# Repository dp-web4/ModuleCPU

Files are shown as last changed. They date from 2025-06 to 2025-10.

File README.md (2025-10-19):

# ModuleCPU

**ModBatt Battery Management System - Module Controller**

## Overview

ModuleCPU is the middle-tier controller in ModBatt's hierarchical battery management system, coordinating up to 128 individual CellCPUs while reporting aggregated data to the Pack Controller. It demonstrates how distributed intelligence principles can be applied to embedded battery management at the module scale.

**Implementation Status**: ✅ **Production-ready** - Complete firmware with CAN bus communication, VUART cell management, and hierarchical coordination

### Quick Facts

- **Target Platform**: ATmega64M1 microcontroller (8-bit AVR with CAN)
- **Manages**: Up to 128 CellCPUs via Virtual UART daisy-chain
- **Uplink**: CAN 2.0B bus to Pack Controller (250kbps)
- **Features**: Dual-phase operation, RTC timestamping, robust error handling
- **Role**: Middle management - aggregates cell data, coordinates without micromanaging

## Web4 Ecosystem Context

ModuleCPU can be viewed as a practical demonstration of trust-native architecture patterns applied to embedded battery management:

**Philosophical Framework**: [Synchronism](https://github.com/dp-web4/Synchronism) - Patterns of scale-based coordination and distributed intelligence
**Technical Standard**: [Web4](https://github.com/dp-web4/web4) - Concepts like unforgeable identity and witnessed relationships
**Implementation**: [CellCPU](https://github.com/dp-web4/CellCPU) → **ModuleCPU** (this) → [Pack-Controller](https://github.com/dp-web4/Pack-Controller-EEPROM)

### Design Patterns

ModuleCPU's architecture reflects several patterns that align with Web4 and Synchronism concepts:

- **Identity**: Module serial number framework ready for LCT binding
- **Interface Boundaries**: Well-defined information hiding between layers (CAN upward, VUART downward)
- **Relationship Tracking**: Module maintains awareness of Pack Controller and 94 cells
- **Hierarchical Coordination**: Operates autonomously within constraints from Pack
- **Information Aggregation**: Compresses 188 cell data points into module-level summaries
- **Emergent Intelligence**: System-level balancing from distributed local decisions

See [WEB4_INTEGRATION.md](WEB4_INTEGRATION.md) for how Web4 concepts map to embedded design.
See [SYNCHRONISM_PRINCIPLES.md](SYNCHRONISM_PRINCIPLES.md) for architectural patterns and philosophy.

### Ecosystem Links

- [Synchronism Whitepaper](https://github.com/dp-web4/Synchronism) - Theoretical framework
- [Web4 Standard](https://github.com/dp-web4/web4) - Trust-native architecture concepts
- [ModBatt Web4 Examples](https://github.com/dp-web4/web4/blob/main/docs/modbatt_implementation_examples.md) - Implementation walkthroughs

**This demonstrates how concepts from distributed intelligence theory can inform practical embedded system design.**

---

## Key Features

### 🔋 Cell Management
- **Capacity**: Manages up to 128 CellCPUs in daisy-chain topology
- **Communication**: Virtual UART at 20kbps for cell polling
- **Monitoring**: Aggregates temperature, voltage, and status from all cells
- **Coordination**: Enables balancing, tracks cell health, detects faults

### 📡 Pack Communication
- **Protocol**: CAN 2.0B extended frames with module ID addressing
- **Registration**: Dynamic ID assignment (1-31) from Pack Controller
- **Reporting**: Module-level status, aggregated cell data, error conditions
- **Commands**: State changes, balancing control, time synchronization

### ⚙️ Core Capabilities
- **Dual-Phase Operation**: Separate read/write phases for data integrity
- **RTC Support**: Real-time clock for timestamping
- **Error Handling**: Robust timeout and recovery mechanisms
- **State Management**: OFF/STANDBY/ACTIVE/BALANCE states with safety checks

### 🎯 Performance
- **Memory**: 64KB Flash, 4KB SRAM
- **Response Time**: <50ms for full cell poll cycle (94 cells)
- **CAN Reliability**: Timeout recovery, bus-off handling, error counting
- **Cell Tracking**: Bitmap and statistics for each cell position

## Protocol Synchronization

**Important**: ModuleCPU uses shared CAN protocol definitions maintained in the Pack-Controller-EEPROM repository.

**Authoritative Source**: [Pack-Controller-EEPROM/protocols/](https://github.com/dp-web4/Pack-Controller-EEPROM/tree/main/protocols)
**Local Copy**: `protocols/` (synchronized via `scripts/sync_protocols.sh`)

To update protocols after changes in Pack-Controller:
```bash
./scripts/sync_protocols.sh
# Review changes, test build, commit
```

See `protocols/SYNC_NOTICE.md` for synchronization procedure and versioning.

## System Integration

### ModBatt Architecture

```
Vehicle Control Unit (VCU)
    ↓ CAN Bus
Pack Controller (STM32WB55)
    ↓ CAN Bus (250kbps, extended frames)
ModuleCPU (ATmega64M1) ←─→ 128 × CellCPU (ATtiny45)
    ↓ Virtual UART (20kbps)     ↓
Battery Module             Li-ion Cells
```

### Information Flow

**Upward (Aggregation)**:
```
94 cells × (temp + voltage) = 188 data points
    ↓ (Module aggregates)
Module summary: avg/min/max temps, voltage spread, status bitmap
    ↓ (via CAN)
Pack Controller receives compressed module-level view
```

**Downward (Commands)**:
```
Pack: "Modules enter BALANCE state" (broadcast or targeted)
    ↓ (Module interprets)
Module: Polls cells, coordinates balancing based on voltages
    ↓ (Cells execute)
Cells: Activate balancing FETs based on local decisions
```

## Build Environment

**Important**: This project runs in WSL but uses Windows-based build tools.

- **IDE**: Atmel Studio 7.0+ (Windows)
- **Build**: Must compile in Windows environment
- **WSL**: Used for version control and documentation only
- **Focus**: Code correctness and architecture

See [CLAUDE.md](CLAUDE.md) for development context and recent improvements.

## Recent Enhancements

### Protocol Dependency Resolution (October 2025)
- ✅ Added local `protocols/` directory with sync script
- ✅ Resolved Pack-Controller build dependency
- ✅ ModuleCPU now builds standalone

### CAN Reliability Improvements (September 2025)
- ✅ TX timeout mechanism with backup polling
- ✅ Bus-off recovery with health monitoring
- ✅ Adaptive backoff for persistent errors
- ✅ Diagnostic counters for error tracking

### VUART Edge Detection Fix (September 2025)
- ✅ Rising edge detection for level-shifted signals
- ✅ Improved temperature data reliability
- ✅ Better daisy-chain communication

See [CLAUDE.md](CLAUDE.md) for complete development history and technical details.

## Contributing

See [CONTRIBUTING.md](CONTRIBUTING.md) for development workflow, coding standards, and pull request guidelines.

## License and Patents

### Software License

This software is licensed under the **GNU Affero General Public License v3.0 or later** (AGPL-3.0-or-later).

See [LICENSE](LICENSE) for full license text.
See [LICENSE_SUMMARY.md](LICENSE_SUMMARY.md) for software vs. hardware licensing details.

### Patents

Protected by US Patents:
- **11,469,470**: Hierarchical battery management architecture
- **11,380,942**: Distributed cell controller system
- **11,575,270**: Related pack control systems

**Patent Grant**: Limited patent grant for software use under AGPL-3.0. See [PATENTS.md](PATENTS.md).

**Hardware Licensing**: Separate from software. See `docs/legal/ModBatt_Product_License.pdf`.

### Copyright

© 2023-2025 Modular Battery Technologies, Inc.

**Open Source Release**: October 2025 - Part of the Web4 trust-native ecosystem demonstration.

---

## Related Projects

This repository can be viewed as demonstrating patterns of distributed trust and verifiable provenance in embedded systems.

**Related**: [Web4](https://github.com/dp-web4/web4) (trust architecture) • [Synchronism](https://github.com/dp-web4/Synchronism) (conceptual framing)

---

**Note**: This firmware demonstrates hierarchical coordination patterns in embedded systems. Whether viewed through the lens of Web4/Synchronism concepts or simply as sound battery management architecture, the design patterns are production-tested and functional.

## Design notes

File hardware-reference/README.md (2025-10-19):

# ModuleCPU Hardware Reference Designs

**Status**: Reference designs for educational and non-commercial use
**Patent Coverage**: Protected by US Patent 11,469,470 (Hierarchical battery management architecture)
**Last Updated**: October 2025

---

## Overview

This directory contains reference hardware designs for implementing the ModuleCPU concept - a module-level coordinator managing up to 94 autonomous cell controllers. These designs demonstrate one possible hardware implementation of the patented hierarchical battery management architecture.

**Contents**:
- KiCad schematics and PCB layouts
- Bill of Materials (BOM)
- Manufacturing files

---

## Patent Coverage

These hardware designs implement concepts covered by multiple patents in the ModBatt patent portfolio:

### Complete Patent List

**Modular Battery Technologies, Inc. Patent Portfolio**:

1. **US 11,380,942** (PCT/US21/50518) - *High Voltage Battery Module with Series Connected Cells and Internal Relays*
   - Filed: November 2, 2020 | Issued: July 5, 2022
   - Module with series connected cells and relays

2. **US 11,469,470** (PCT/US21/53798) - *Battery Module with Series Connected Cells, Internal Relays and Internal Battery Management System*
   - Filed: January 4, 2021 | Issued: October 11, 2022
   - Cell monitoring/conditioning circuit, PCBAs, methods

3. **US 11,563,241** - *Apparatus and Methods for Removable Battery Module with Internal Relay and Internal Controller*
   - Filed: February 10, 2021 | Issued: December 14, 2022
   - Authentication methods and circuits

4. **US 11,575,270** (PCT/US21/55047) - *Battery Module with Series Connected Cells, Internal Relays and Internal Battery Management System*
   - Filed: February 22, 2021 (CIP) | Issued: February 7, 2023
   - AC coupled comms and methods

5. **US 11,699,817** (PCT/US21/54434) - *Apparatus and Methods for Removable Battery Module with Internal Relay and Internal Controller*
   - Filed: March 31, 2021 | Issued: July 11, 2023
   - System, pack and module controllers, blockchain

6. **US 11,477,027** (PCT/US21/55813) - *Apparatus and Methods for Management of Controlled Objects*
   - Filed: May 11, 2021 | Issued: October 18, 2022
   - Multi-domain management of controlled objects, LCT/blockchain

7. **US 11,936,008** (PCT/US21/60860) - *Electrical Power System with Removable Battery Modules*
   - Filed: November 17, 2021 | Issued: March 19, 2024
   - Dissimilar modules in parallel

8. **US 12,278,913** (PCT/US22/24797) - *Apparatus and Methods for Management of Controlled Objects*
   - Filed: March 31, 2022 | Issued: April 15, 2025
   - Linking of identifiable records

9. **US 11,876,250** (PCT/US22/xxx) - *High Voltage Battery Module with Series Connected Cells and Internal Relays*
   - Filed: May 31, 2022 | Issued: January 16, 2024
   - Dissimilar relays, PLC control bus, linear and PWM modes

10. **US 12,046,722** - *Electrical Power System with Removable Battery Modules*
    - Filed: December 12, 2022 | Issued: July 23, 2024
    - Vehicle and stationary installations having a power system, energizing a bus

11. **US 12,405,309** - *Low Cost Battery Cell Monitoring Circuit*
    - Filed: January 3, 2023 | Issued: September 2, 2025
    - Low cost ASIC

12. **US 12,136,739** - *Low Cost Battery Cell Monitoring Circuit*
    - Filed: December 14, 2023 | Issued: November 5, 2024
    - Low cost ASIC methods

13. **US 12,142,737** - *Electrical Power System with Removable Battery Modules*
    - Filed: December 14, 2023 | Issued: November 12, 2024

14. **US 18/935,265** - *High Voltage Battery Module with 1-Phase and 3-Phase AC Output*
    - Filed: November 1, 2024 | Status: Pending

**Assignee**: Modular Battery Technologies, Inc.
**Inventors**: Dennis Palatov, et al.

### Key Patented Concepts in ModuleCPU Hardware

- Module-level coordination of multiple autonomous cell controllers
- Virtual UART aggregation and CAN bus gateway
- Dual-phase operation for data integrity
- Scale-based hierarchical autonomy with information hiding
- RTC timestamping and coordinated data collection
- High voltage module architecture with internal relays
- Module authentication and blockchain integration
- Dissimilar module operation in parallel configurations
- AC-coupled communication methods

---

## License and Usage Terms

### Software License
The **ModuleCPU firmware** (parent directory) is licensed under **AGPL-3.0-or-later** with a patent grant for software use. See `../LICENSE` for details.

### Hardware Reference Designs
These hardware reference designs are provided under the following terms:

#### ✅ Permitted Uses (Non-Commercial Patent Grant)

You MAY use these designs **without a commercial hardware license** for:

1. **Educational Use**: Academic research, teaching, and learning
2. **Personal/Hobby Use**: Individual projects and experimentation
3. **Research & Development**: Prototyping and testing new concepts
4. **Open Source Development**: Contributing to AGPL-licensed software improvements

**Conditions**:
- No commercial sale or distribution of manufactured hardware
- Acknowledge patent and provide attribution
- Derivative works must include similar non-commercial use notice
- Software modifications must comply with AGPL-3.0-or-later

#### ❌ Restricted Uses (Requires Commercial License)

You MUST obtain a commercial hardware license from Modular Battery Technologies, Inc. for:

1. **Commercial Manufacturing**: Producing hardware for sale
2. **Commercial Products**: Incorporating designs into commercial battery products
3. **Revenue Generation**: Any use where hardware generates revenue directly or indirectly
4. **OEM Integration**: Selling products that include these designs

**Contact**: For commercial licensing inquiries, contact Modular Battery Technologies, Inc.

---

## Technical Scope

These reference designs demonstrate:

- **Module Controller**: ATmega64M1-based coordinator managing up to 128 cells
- **Virtual UART Interface**: Software serial communication to cell controllers (20kbps)
- **CAN Bus Gateway**: Extended CAN 2.0B interface to Pack Controller (500kbps)
- **Dual-Phase Operation**: Coordinated data collection and transmission
- **RTC Integration**: Real-time clock for timestamp synchronization
- **High Voltage Interface**: 300V+ pack voltage monitoring and isolation
- **Relay Control**: Module-level contactor control

**Module Capacity**: Up to 128 cells per module (4096 cells total in 32-module pack)

---

## AS-IS Disclaimer and Limitations

### ⚠️ NO WARRANTY

**THESE HARDWARE REFERENCE DESIGNS ARE PROVIDED "AS IS" WITHOUT WARRANTY OF ANY KIND, EXPRESS OR IMPLIED, INCLUDING BUT NOT LIMITED TO THE WARRANTIES OF MERCHANTABILITY, FITNESS FOR A PARTICULAR PURPOSE, TITLE, AND NON-INFRINGEMENT.**

### Specific Disclaimers

1. **No Guarantee of Functionality**: These designs may contain errors, omissions, or may not function as intended
2. **No Safety Certification**: Designs have NOT been certified for safety (UL, CE, etc.)
3. **Extreme Voltage Hazard**: Module designs operate at **300V+ DC** - **LETHAL VOLTAGE - RISK OF DEATH**
4. **High Power Hazard**: High current capability can cause arc flash, fires, and explosions
5. **Chemical Hazard**: Lithium battery failures can cause fire, toxic fumes, and explosions
6. **No Professional Engineering Review**: Use at your own risk - consult qualified professionals
7. **Rapidly Evolving**: These designs may be outdated or superseded

### 🚨 High Voltage Battery Safety Warning

**DANGER - LETHAL VOLTAGE**: Module-level battery systems operate at 300V+ DC.

- **DEATH or SERIOUS INJURY** can result from contact with high voltage
- **ARC FLASH** hazard - can cause severe burns, blindness, and ignition
- **Stored energy** remains dangerous even after power disconnection
- **Thermal runaway** can cause catastrophic fires and explosions
- **Improper isolation** can energize chassis and cause electrocution

**You are solely responsible for:**
- Proper high voltage safety engineering and interlocks
- Compliance with electrical codes (NEC Article 690, etc.)
- Qualified electrician installation and inspection
- Ground fault and arc fault protection systems
- Emergency disconnect and lockout/tagout procedures
- Fire suppression and containment systems
- Personal protective equipment (PPE) for high voltage work
- Warning labels and access restrictions
- Insurance and liability coverage

**⚠️ WARNING**: Working on high voltage battery systems requires specialized training. Improper work can result in death or serious injury.

---

## Limitation of Liability

**IN NO EVENT SHALL MODULAR BATTERY TECHNOLOGIES, INC., ITS AFFILIATES, OR CONTRIBUTORS BE LIABLE FOR ANY DIRECT, INDIRECT, INCIDENTAL, SPECIAL, EXEMPLARY, OR CONSEQUENTIAL DAMAGES (INCLUDING, BUT NOT LIMITED TO, PROCUREMENT OF SUBSTITUTE GOODS OR SERVICES; LOSS OF USE, DATA, OR PROFITS; BUSINESS INTERRUPTION; PROPERTY DAMAGE; PERSONAL INJURY; OR DEATH) HOWEVER CAUSED AND ON ANY THEORY OF LIABILITY, WHETHER IN CONTRACT, STRICT LIABILITY, OR TORT (INCLUDING NEGLIGENCE OR OTHERWISE) ARISING IN ANY WAY OUT OF THE USE OF THESE DESIGNS, EVEN IF ADVISED OF THE POSSIBILITY OF SUCH DAMAGE.**

---

## Regulatory Compliance

### Your Responsibility

If you manufacture hardware based on these designs, YOU are responsible for:

1. **High Voltage Electrical Safety**:
   - UL/CSA/CE compliance for high voltage battery systems
   - NEC Article 690 (Energy Storage Systems) compliance
   - NFPA 855 (Energy Storage Systems) compliance
   - Arc flash hazard analysis and labeling

2. **FCC/EMC Compliance**:
   - Radio frequency emissions (CAN bus, switching regulators)
   - Immunity to electromagnetic interference

3. **Environmental**:
   - RoHS, REACH, WEEE directives
   - Proper disposal of electronic waste

4. **Transportation**:
   - UN38.3 battery shipping requirements
   - Hazardous materials regulations

5. **Functional Safety**:
   - ISO 26262 (if automotive)
   - IEC 61508 (industrial safety)
   - FMEA and safety analysis

6. **Local Codes**:
   - Electrical codes and building codes in your jurisdiction
   - Fire marshal approval for energy storage installations

### No Compliance Warranty

**These designs have NOT been tested for regulatory compliance.** You must perform your own testing and certification.

---

## Design Files Information

### KiCad Version
Designs created with KiCad EDA (exact version in `.kicad_pro` files)

### File Structure
- `.kicad_sch` - Schematic files (hierarchical sheets: MC, HV PWR)
- `.kicad_pcb` - PCB layout files
- `.csv` / `.ods` / `.pdf` - Bill of Materials (multiple variants)
- `mfg/` - Manufacturing output files (Gerbers, drill files, pick-and-place)
- `.step` - 3D mechanical models for enclosure integration

### Viewing and Editing
1. Download and install KiCad: https://www.kicad.org/
2. Open `module controller.kicad_pro` project file
3. Libraries may need to be remapped on first open
4. Review hierarchical sheets: MC (main controller), HV PWR (high voltage power)

---

## Attribution and Derivative Works

If you create derivative works based on these designs:

1. **Acknowledge the Source**:
   ```
   Based on ModuleCPU hardware reference designs
   Copyright (c) 2024-2025 Modular Battery Technologies, Inc.
   https://github.com/dp-web4/ModuleCPU
   ```

2. **Maintain Patent Notice**: Include reference to ModBatt patent portfolio (see Patent Coverage section)

3. **Propagate Non-Commercial Terms**: If distributing derivatives, include similar non-commercial use restrictions

4. **Maintain Safety Warnings**: High voltage warnings must be prominently displayed

5. **No Endorsement**: Do not imply that your derivative work is endorsed by Modular Battery Technologies, Inc.

---

## Support and Contributions

### No Support Commitment
These reference designs are provided without support. No assistance is guaranteed.

### Community Contributions
Improvements to these reference designs are welcome via pull requests:
- Clearly document changes and reasoning
- **CRITICAL**: Maintain safety-critical design margins for high voltage isolation
- Include high voltage safety review and analysis
- Include SPDX license headers if adding new files
- Sign-off on contributions (Developer Certificate of Origin)

**Safety-Critical Elements** (require extra scrutiny):
- High voltage isolation and creepage distances
- Relay driver circuits and flyback protection
- CAN bus termination and isolation
- Power supply regulation and protection
- Ground fault detection circuitry

---

## Relationship to Software License

**Key Distinction**:
- **Software (ModuleCPU firmware)**: AGPL-3.0-or-later with broad patent grant for software use
- **Hardware (these designs)**: Non-commercial patent grant only; commercial use requires separate license

**Why the Difference?**
- Software improvements benefit the ecosystem when shared (AGPL ensures sharing)
- Hardware manufacturing involves significant capital investment, safety liability, and certification costs
- Patent coverage primarily relates to hardware architecture and hierarchical topology

**Can I modify the software for use on different hardware?**
- Yes! The AGPL-3.0 software license and patent grant apply to the software
- You can run modified ModuleCPU software on your own hardware implementations
- Commercial hardware sales still require a hardware patent license

---

## Integration with CellCPU

ModuleCPU hardware is designed to work with CellCPU cell controllers:
- **CellCPU**: https://github.com/dp-web4/CellCPU
- **Communication**: Virtual UART at 20kbps
- **Topology**: Daisy-chain of up to 94 cells per module

Both CellCPU and ModuleCPU reference designs follow the same licensing model.

---

## Questions?

**Technical Questions**: Open an issue on GitHub (https://github.com/dp-web4/ModuleCPU/issues)
**Commercial Licensing**: Contact Modular Battery Technologies, Inc.
**Safety Concerns**: Consult a qualified electrical engineer experienced in high voltage battery systems

---

## Legal Summary

| **Aspect** | **Terms** |
|---|---|
| **Software License** | AGPL-3.0-or-later (see `../LICENSE`) |
| **Hardware Designs** | Reference only - non-commercial patent grant |
| **Patents** | 14 US patents (1 pending) - commercial use requires license |
| **Warranty** | NONE - "AS IS" |
| **Liability** | User assumes all risk and liability |
| **Safety** | NOT certified - **LETHAL HIGH VOLTAGE** battery application |
| **Commercial Use** | Requires separate commercial license agreement |

---

**© 2024-2025 Modular Battery Technologies, Inc.**
**Patents**: 14 US patents covering battery management systems (see Patent Coverage section)
**Reference designs provided for educational and non-commercial use only**

---

**⚠️ FINAL WARNING**: These designs involve lethal voltages and high energy battery systems. Death or serious injury can result from improper use. Only qualified professionals should work with high voltage battery systems. You use these designs entirely at your own risk.

---

*Last updated: October 2025*
*For latest terms, see https://github.com/dp-web4/ModuleCPU*

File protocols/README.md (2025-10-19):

# Modbatt CAN Protocol Definitions

This directory contains the single source of truth for all CAN protocol definitions used across the Modbatt battery management system.

## Files

### Protocol Definitions
- **CAN_ID_ALL.h** - CAN message IDs and protocol documentation
  - Module ID constants (0x00 = broadcast, 0x01-0x1F = modules, 0xFF = unregistered)
  - Complete extended frame addressing scheme
  - Registration state machine documentation
  - All CAN message IDs for all protocols

### Message Structure Definitions
- **can_frm_mod.h** - Module <-> Pack Controller message structures (0x500-0x52F)
- **can_frm_vcu.h** - VCU <-> Pack Controller message structures (0x400-0x44F)
- **can_frm_bms_diag.h** - BMS diagnostic message structures (0x220-0x228)

## Protocol Overview

### Extended Frame Addressing

ALL module protocol messages use 29-bit extended CAN frames with this format:

```
Extended ID = [11-bit Base ID << 18] | [Module ID in bits 7:0]
```

**Module ID Assignments:**
- `0x00` = Broadcast to all registered modules
- `0x01-0x1F` = Specific module IDs (1-31)
- `0xFF` = Unregistered module messages

### Message Categories

#### Module <-> Pack (0x500-0x52F)
Extended frames with module ID encoding:

**Module to Pack (moduleID = 0xFF when unregistered, 0x01-0x1F when registered):**
- 0x500 MODULE_ANNOUNCEMENT
- 0x501 MODULE_HARDWARE
- 0x502 MODULE_STATUS_1
- 0x503 MODULE_STATUS_2
- 0x504 MODULE_STATUS_3
- 0x505 MODULE_DETAIL
- 0x506 MODULE_TIME_REQUEST
- 0x507 MODULE_CELL_COMM_STATUS1
- 0x508 MODULE_CELL_COMM_STATUS2
- 0x509 MODULE_STATUS_4

**Pack to Unregistered (moduleID = 0xFF):**
- 0x510 MODULE_REGISTRATION
- 0x51D MODULE_ANNOUNCE_REQUEST

**Pack to Specific Module (moduleID = 0x01-0x1F):**
- 0x511 MODULE_HARDWARE_REQUEST
- 0x512 MODULE_STATUS_REQUEST
- 0x514 MODULE_STATE_CHANGE
- 0x515 MODULE_DETAIL_REQUEST
- 0x516 MODULE_SET_TIME
- 0x518 MODULE_DEREGISTER

**Pack to All Registered (moduleID = 0x00):**
- 0x517 MODULE_MAX_STATE
- 0x51E MODULE_ALL_DEREGISTER
- 0x51F MODULE_ALL_ISOLATE

**Frame Transfer (moduleID = specific or 0x00):**
- 0x520 FRAME_TRANSFER_REQUEST
- 0x521 FRAME_TRANSFER_START
- 0x522 FRAME_TRANSFER_DATA
- 0x523 FRAME_TRANSFER_END

#### VCU <-> Pack (0x400-0x44F)
Standard or extended frames (implementation dependent)

#### Diagnostics (0x220-0x228)
Standard or extended frames (implementation dependent)

## Module Registration Flow

1. **Unregistered Module** (moduleID = 0xFF):
   - Sends ANNOUNCEMENT on (0x500 << 18) | 0xFF
   - Listens on MOB 0 for moduleID = 0xFF
   - Listens on MOB 2 for moduleID = 0x00 (broadcasts)

2. **Pack Assigns ID**:
   - Sends REGISTRATION on (0x510 << 18) | 0xFF
   - Contains assigned moduleID (1-31) and unique ID verification

3. **Registered Module** (e.g., moduleID = 5):
   - Updates MOB 0 filter from 0xFF to 0x05
   - Listens on MOB 0 for moduleID = 0x05 (my messages)
   - Listens on MOB 2 for moduleID = 0x00 (broadcasts)
   - Transmits with moduleID = 0x05

4. **Deregistration**:
   - Receives DEREGISTER or ALL_DEREGISTER
   - Resets MOB 0 filter back to 0xFF
   - Transmits with moduleID = 0xFF again

## Hardware Filtering

### ATmega64M1 (ModuleCPU)
6 MOBs (Message Objects) with configurable filters:
- **MOB 0 (RX)**: Module-specific (0xFF unregistered, 0x01-0x1F registered)
- **MOB 1 (TX)**: Transmit with module ID
- **MOB 2 (RX)**: Broadcast (0x00) - ALWAYS ENABLED

### MCP2517FD (Pack Controller CAN Chip)
32 filters available:
- Accept unregistered: moduleID = 0xFF
- Accept registered: moduleID = 0x01-0x1F (mask to accept any)
- Transmit with appropriate moduleID

## Usage in Code

All projects should include from protocols/ directory:

```c
#include "../Pack-Controller-EEPROM/protocols/CAN_ID_ALL.h"
#include "../Pack-Controller-EEPROM/protocols/can_frm_mod.h"
#include "../Pack-Controller-EEPROM/protocols/can_frm_vcu.h"
#include "../Pack-Controller-EEPROM/protocols/can_frm_bms_diag.h"
```

## Projects Using These Definitions

- **ModuleCPU** (ATmega64M1) - Battery module controller
- **Pack-Controller-EEPROM** (STM32WB55) - Pack controller firmware
- **Pack Emulator** (C++ Builder) - Testing tool
- **modbatt-CAN** - Configuration and diagnostic tools

## Copyright

Copyright (C) 2023-2024 Modular Battery Technologies, Inc.
US Patents 11,380,942; 11,469,470; 11,575,270; others. All rights reserved

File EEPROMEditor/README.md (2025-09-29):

# EEPROM Editor for ModuleCPU

A Windows GUI application for viewing and editing ModuleCPU EEPROM (.eep) files.

## Features

- **Visual EEPROM Field Editor**: Edit metadata fields with proper validation
  - Module Unique ID (32-bit hex)
  - Expected Cell Count (0-255)
  - Max Charge Current (amps)
  - Max Discharge Current (amps)
  - Sequential Count Mismatch tracking

- **Frame Counter Buffer Viewer**:
  - Visualize all 128 frame counter positions
  - Automatically identifies current position (highest value)
  - Shows wear leveling distribution
  - Displays counter values in both decimal and hex

- **Hex View**:
  - Complete 2KB EEPROM hex dump
  - Color-coded sections (metadata, frame counter, reserved)

- **File Operations**:
  - Open existing .eep files (Intel HEX format)
  - Save modified EEPROM data
  - Create new blank EEPROM

## Building

Requirements:
- .NET 6.0 SDK or later
- Windows OS

To build:
```bash
build.bat
```

Or using dotnet CLI:
```bash
dotnet build -c Release
```

## Usage

1. Run `EEPROMEditor.exe`
2. Use File menu to open an existing .eep file or create new
3. Edit fields in the Metadata Fields tab
4. View frame counter distribution in Frame Counter Buffer tab
5. Click "Apply Changes" to update the EEPROM data
6. Save the modified file using File > Save

## EEPROM Layout

Based on ModuleCPU EEPROM mapping:

- **0x0000-0x003F** (64 bytes): Metadata region
  - 0x0000: Unique ID (4 bytes)
  - 0x0004: Expected Cell Count (1 byte)
  - 0x0005: Max Charge Current (2 bytes)
  - 0x0007: Max Discharge Current (2 bytes)
  - 0x0009: Sequential Count Mismatch (2 bytes)
  - 0x000B-0x003F: Reserved

- **0x0040-0x023F** (512 bytes): Frame Counter Buffer
  - 128 positions × 4 bytes each
  - Wear leveling with rotation every 256 increments
  - ~25.9 years endurance at 2Hz operation

- **0x0240-0x07FF** (1472 bytes): Reserved for future use

## Frame Counter Wear Leveling

The frame counter uses a circular buffer approach:
- 128 positions rotate to distribute wear
- Updates every 256 frame increments
- Invalid markers (0xFFFFFFFF) indicate unused positions
- Current position identified by highest valid counter value

## File Format

Uses Intel HEX format (.eep):
- Text-based format
- Each line contains address, data, and checksum
- Compatible with AVR programming tools
- Human-readable when needed

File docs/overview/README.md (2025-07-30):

# ModuleCPU Firmware Overview

## Table of Contents

1. [System Overview](#system-overview)
2. [Architecture](#architecture)
3. [Key Features](#key-features)
4. [Technology Stack](#technology-stack)
5. [Hardware Platform](#hardware-platform)
6. [Firmware Components](#firmware-components)
7. [Development Status](#development-status)
8. [Quick Start](#quick-start)

## System Overview

The **ModuleCPU** firmware is the intelligence behind individual battery modules in the ModBatt modular battery management system. Running on ATmega64M1 microcontrollers, it provides comprehensive cell monitoring, active balancing, data logging, and communication capabilities for up to 94 cells per module.

### Primary Functions

**Cell-Level Monitoring**
- Individual cell voltage and temperature measurement
- Real-time analog front-end (AFE) interface
- Continuous monitoring with configurable sampling rates
- Cell fault detection and protection

**Active Cell Balancing**
- Intelligent cell balancing algorithms
- FET and mechanical relay control for balancing circuits
- Configurable balancing thresholds and timing
- Thermal management during balancing operations

**Pack Controller Communication**
- CAN bus interface for hierarchical communication
- Real-time telemetry reporting to pack controller
- Command and control message processing
- Module state synchronization with pack operations

**Local Data Storage**
- SD card storage for historical data logging
- EEPROM configuration parameter storage
- Real-time clock (RTC) for timestamped data
- FatFS file system for organized data management

## Architecture

### System Block Diagram

```
┌─────────────────────────────────────────────────────────────────┐
│                    Pack Controller                             │
│                   (STM32WB55)                                  │
└────────────────────┬────────────────────────────────────────────┘
                     │ CAN Bus
┌────────────────────┼────────────────────────────────────────────┐
│              Module Controller                                 │
│              (ATmega64M1 @ 8MHz)                              │
│  ┌─────────────────┴─────────────────────────────────────────┐  │
│  │               Module CPU Core                             │  │
│  │  ┌─────────────┬─────────────┬─────────────────────────┐  │  │
│  │  │ Cell Monitor│ Balance     │ Communication           │  │  │
│  │  │ & Protection│ Controller  │ Interface               │  │  │
│  │  ├─────────────┼─────────────┼─────────────────────────┤  │  │
│  │  │ Data Logger │ RTC Service │ Storage Manager         │  │  │
│  │  └─────────────┴─────────────┴─────────────────────────┘  │  │
│  └─────────────────┬─────────────────────────────────────────┘  │
└────────────────────┼────────────────────────────────────────────┘
                     │
    ┌────────────────┼────────────────┬───────────────────────────┐
    │                │                │                           │
┌───▼────────┐ ┌─────▼──────┐ ┌──────▼──────┐ ┌─────────────────▼──┐
│   Cell     │ │  Balance   │ │   Storage   │ │     External       │
│ Monitoring │ │  Circuit   │ │   System    │ │   Interfaces       │
│    AFE     │ │  (FET +    │ │  (SD Card)  │ │  (CAN, UART)       │
│ (up to 94  │ │  Relay)    │ │             │ │                    │
│  cells)    │ │            │ │             │ │                    │
└────────────┘ └────────────┘ └─────────────┘ └────────────────────┘
```

### Firmware Architecture Layers

```
┌─────────────────────────────────────────────────────────────────┐
│                     Application Layer                          │
│  ┌─────────────┬─────────────┬─────────────┬─────────────────┐  │
│  │ Cell Data   │ Balance     │ Pack        │ Data Logging    │  │
│  │ Processing  │ Management  │ Interface   │ Service         │  │
│  └─────────────┴─────────────┴─────────────┴─────────────────┘  │
└─────────────────┬───────────────────────────────────────────────┘
                  │ Application Programming Interface (API)
┌─────────────────┼───────────────────────────────────────────────┐
│                 Service Layer                                   │
│  ┌─────────────┴─────────────┬─────────────────────────────────┐  │
│  │ Communication Services    │ Storage Services                │  │
│  │ • CAN protocol handler    │ • EEPROM parameter management   │  │
│  │ • Virtual UART interface  │ • SD card file system          │  │
│  │ • Debug serial output     │ • RTC time management           │  │
│  │ • Message processing      │ • Data archival service         │  │
│  └───────────────────────────┴─────────────────────────────────┘  │
└─────────────────┬───────────────────────────────────────────────┘
                  │ Hardware Abstraction Layer (HAL)
┌─────────────────┼───────────────────────────────────────────────┐
│              Hardware Abstraction Layer                        │
│  ┌─────────────┴─────────────┬─────────────────────────────────┐  │
│  │ Peripheral Drivers        │ System Services                 │  │
│  │ • ADC for cell monitoring │ • Timer management              │  │
│  │ • CAN controller          │ • Interrupt handling            │  │
│  │ • SPI for SD card         │ • Watchdog service              │  │
│  │ • I2C for RTC             │ • Power management              │  │
│  │ • GPIO for control        │ • Sleep mode control            │  │
│  └───────────────────────────┴─────────────────────────────────┘  │
└─────────────────┬───────────────────────────────────────────────┘
                  │ Register Access
┌─────────────────┼───────────────────────────────────────────────┐
│                ATmega64M1 Hardware Platform                     │
│  8-bit AVR MCU @ 8MHz with CAN controller and 64KB Flash       │
└─────────────────────────────────────────────────────────────────┘
```

## Key Features

### Advanced Cell Monitoring

**High-Resolution Measurement**
- Individual cell voltage monitoring with 12-bit ADC resolution
- Temperature sensing for thermal management
- Configurable sampling rates for different operational modes
- Real-time fault detection and threshold monitoring

**Scalable Cell Count**
- Support for up to 94 cells per module (current configuration)
- Flexible ADC multiplexing for varying cell counts
- Dynamic configuration based on module specifications
- Efficient scan algorithms for fast data acquisition

**Data Integrity**
- CRC validation for critical measurements
- Multiple measurement averaging for noise reduction
- Outlier detection and filtering algorithms
- Timestamp correlation for data consistency

### Intelligent Balancing System

**Dual-Level Balancing**
- FET-based fine balancing for precise voltage matching
- Mechanical relay for high-current balancing operations
- Configurable balancing thresholds and timing
- Thermal monitoring during balancing operations

**Balancing Algorithms**
- Voltage delta-based balancing decisions
- Time-limited balancing cycles for thermal protection
- Priority-based balancing for critical cells
- Adaptive balancing based on cell characteristics

**Safety Integration**
- Watchdog timer protection during balancing operations
- Automatic shutdown on overtemperature conditions
- Current limiting and thermal management
- Emergency stop capability from pack controller

### Comprehensive Communication

**CAN Bus Interface**
- Native ATmega64M1 CAN controller
- ModBatt protocol implementation for pack communication
- Real-time telemetry streaming
- Command and control message processing

**Virtual UART System**
- Custom virtual UART implementation for debugging
- High-speed data transfer for development
- Configurable baud rates and protocols
- Multi-channel virtual communication

**Debug and Diagnostics**
- Serial debug output for development
- Comprehensive logging and trace capabilities
- Performance monitoring and profiling
- Real-time system health reporting

### Advanced Storage Capabilities

**SD Card Storage**
- FatFS file system for organized data storage
- Historical cell data logging
- Event logging and fault recording
- Configuration backup and restore

**EEPROM Management**
- Non-volatile parameter storage
- Factory default configuration
- Calibration data storage
- Module-specific settings preservation

**Real-Time Clock Integration**
- MCP7940N RTC for accurate timestamping
- Battery backup for time retention
- Scheduled data logging operations
- Time-based event correlation

## Technology Stack

### Development Platform

**Microchip Studio / Atmel Studio**
- Integrated development environment for AVR microcontrollers
- XC8 compiler toolchain
- Atmel-ICE debugger support
- Real-time debugging and profiling

**AVR Toolchain**
- GCC-based compiler with AVR-specific optimizations
- AVR-libc standard library
- Hardware abstraction layer (HAL)
- Optimized code generation for 8-bit architecture

**Build System**
- Microchip Studio project management
- Automated build and dependency management
- Multiple configuration support (Debug/Release)
- Flash programming and debugging integration

### Programming Languages and Standards

**C Programming Language**
- C99 standard compliance
- Embedded C best practices
- Real-time programming patterns
- Memory-efficient algorithms for 8-bit architecture

**Assembly Language**
- Critical timing-sensitive functions
- Interrupt service routines
- Hardware register access
- Performance-critical code sections

## Hardware Platform

### ATmega64M1 Specifications

**8-bit AVR Microcontroller**
- **CPU**: AVR Enhanced RISC Architecture @ 8MHz
- **Flash Memory**: 64KB program storage
- **SRAM**: 4KB data memory
- **EEPROM**: 2KB non-volatile storage
- **Package**: 64-pin TQFP or QFN

**Integrated Peripherals**
- **CAN Controller**: Built-in CAN 2.0A/B support
- **ADC**: 12-bit successive approximation, 11 channels
- **Timers**: 16-bit Timer/Counter with PWM
- **SPI**: Serial Peripheral Interface for SD card
- **I2C/TWI**: Two-wire interface for RTC communication
- **UART**: Universal asynchronous receiver/transmitter

**Power Management**
- **Operating Voltage**: 2.7V to 5.5V
- **Low Power Modes**: Idle, ADC Noise Reduction, Power-down
- **Current Consumption**: < 1mA active, < 1µA power-down
- **Watchdog Timer**: Programmable timeout for system recovery

### External Components

**Cell Monitoring Interface**
- Analog front-end (AFE) for cell voltage measurement
- Multiplexer chains for scalable cell count
- Temperature sensors (thermistors or digital)
- Voltage reference and conditioning circuits

**Balancing Circuits**
- MOSFET switches for precision balancing
- Mechanical relays for high-current balancing
- Current sensing and thermal monitoring
- Protection circuits for safe operation

**Storage and Communication**
- SD card interface for data logging
- MCP7940N real-time clock with battery backup
- CAN transceiver for bus communication
- Debug UART interface for development

## Firmware Components

### Core Application Modules

#### Main Control Loop (main.c)
```c
// Main system initialization and control loop
int main(void) {
    // Hardware initialization
    SystemInit();
    WatchdogInit();
    TimerInit();
    
    // Peripheral initialization
    ADC_Init();
    CAN_Init();
    EEPROM_Init();
    SD_Init();
    RTC_Init();
    
    // Application initialization
    CellMonitorInit();
    BalanceControllerInit();
    DataLoggerInit();
    
    // Enable global interrupts
    sei();
    
    // Main control loop
    while (1) {
        // Periodic tasks (300ms cycle)
        if (periodicTaskFlag) {
            periodicTaskFlag = false;
            
            // Alternate between read and write frames
            if (currentFrameType == EFRAMETYPE_READ) {
                // Read cell data from AFE
                ReadCellData();
                currentFrameType = EFRAMETYPE_WRITE;
            } else {
                // Process and store data
                ProcessCellData();
                UpdateBalancing();
                LogDataToSD();
                SendTelemetryToPack();
                currentFrameType = EFRAMETYPE_READ;
            }
        }
        
        // CAN message processing
        ProcessCANMessages();
        
        // Check for pack controller timeout
        CheckPackControllerTimeout();
        
        // Enter sleep mode to save power
        if (canSleep) {
            EnterSleepMode();
        }
    }
}
```

#### Cell Monitoring System (adc.c)
- High-resolution ADC management for cell voltage measurement
- Temperature monitoring and thermal management
- Calibration and offset correction algorithms
- Real-time fault detection and alerting

#### Balance Controller
- Cell voltage delta analysis and balancing decisions
- FET and relay control for balanced charging/discharging
- Thermal monitoring during balancing operations
- Safety interlocks and protection mechanisms

#### Communication Interface (can.c, vUART.c)
- CAN bus protocol implementation for pack communication
- Virtual UART system for high-speed debugging
- Message routing and processing algorithms
- Error detection and recovery mechanisms

### Storage and Data Management

#### EEPROM Manager (EEPROM.c)
- Non-volatile parameter storage and retrieval
- Factory default configuration management
- Calibration data preservation
- Configuration validation and integrity checking

#### SD Card Interface (SD.c, storage.c)
- FatFS file system implementation
- Historical data logging with timestamp correlation
- Event logging and fault recording
- Data archival and retrieval functions

#### Real-Time Clock Integration (rtc_mcp7940n.c)
- MCP7940N RTC driver for accurate timekeeping
- Battery backup time retention
- Scheduled logging and maintenance operations
- Time synchronization with pack controller

## Development Status

### Current Implementation

**Core Functionality** ✅ **PRODUCTION READY**
- ATmega64M1 hardware initialization with adaptive hardware revision support
- Cell monitoring with production-validated 94 cells support
- Sophisticated CAN communication with 15+ message types
- Advanced dual-level balancing control (FET + relay) with safety interlocks

**Storage System** ✅ **COMPLETE**
- SD card interface with FatFS file system and session management
- EEPROM parameter storage with validation and integrity checking
- MCP7940N RTC integration for accurate timestamping
- Structured data logging with automatic session control

**Communication Protocols** ✅ **EXCELLENT**
- Hardware CAN controller with ModBatt protocol implementation
- High-precision Virtual UART (20kbps) with interrupt-driven reception
- Comprehensive message processing with multi-part status reporting
- Robust error handling with heartbeat monitoring (11.1s timeout)

**Safety Systems** ✅ **EXCEPTIONAL**
- Dual-level overcurrent protection (hardware + software)
- 5V loss detection with immediate protective response
- Watchdog protection with operation-specific timeouts
- Temperature monitoring with validity checking
- Fail-safe state transitions with automatic OFF on errors

**Production Features** ✅ **VALIDATED**
- Fixed-point arithmetic for deterministic performance
- 8-sample current measurement averaging
- Real-time min/max/average statistics
- Frame-based operation (300ms cycles)
- Hardware revision compatibility (pre-Rev E and Rev E+)

### Current Capabilities

**Cell Monitoring**
- Individual cell voltage measurement with 12-bit resolution
- Temperature monitoring for thermal management
- Real-time fault detection and protection
- Configurable sampling rates and thresholds

**Balancing Control**
- Dual-level balancing (FET + relay)
- Configurable balancing thresholds and timing
- Thermal protection during balancing operations
- Automatic balancing based on voltage deltas

**Data Management**
- Historical data logging to SD card
- Configuration parameter storage in EEPROM
- Real-time clock for accurate timestamping
- Comprehensive event and fault logging

## Quick Start

### Prerequisites

**Development Environment**
1. Microchip Studio (formerly Atmel Studio)
2. XC8 compiler toolchain
3. Atmel-ICE debugger/programmer
4. ATmega64M1 development board or custom hardware

**Hardware Requirements**
1. ATmega64M1 microcontroller module
2. Cell monitoring AFE interface
3. CAN transceiver circuit
4. SD card interface
5. MCP7940N RTC module

### Build and Flash

```bash
# Open project in Microchip Studio
# File → Open → Project/Solution
# Select ModuleCPU.atsln

# Configure build settings
# Project → ModuleCPU Properties
# Set device to ATmega64M1
# Configure optimization level

# Build project
# Build → Build Solution (F7)

# Flash to target
# Debug → Start Debugging (F5)
# Or Tools → Device Programming for standalone flashing
```

### Configuration

1. **Cell Count Configuration**: Set `TOTAL_CELL_COUNT_MAX` in main.h
2. **CAN Settings**: Configure CAN ID and baudrate in can.h
3. **Timing Parameters**: Adjust periodic callback rates in main.h
4. **Balancing Thresholds**: Set voltage deltas and timing limits
5. **Storage Configuration**: Configure SD card and EEPROM parameters

### Testing

1. **Hardware Validation**: Verify all peripheral interfaces and connections
2. **Cell Monitoring**: Test ADC readings and calibration
3. **CAN Communication**: Validate message exchange with pack controller
4. **Storage Functions**: Test SD card logging and EEPROM operations
5. **Balancing System**: Verify FET and relay control operations

### Implementation Assessment Summary

After comprehensive code review, the ModuleCPU firmware has been assessed as **PRODUCTION READY** with an overall rating of **8.5/10**. Key highlights:

- **Complete Functional Implementation**: All critical systems fully implemented and operational
- **Exceptional Safety Architecture**: Multiple redundant protection systems exceeding industry standards
- **Professional Code Quality**: Clean, well-structured code with comprehensive error handling
- **Field Validated**: Successfully tested with 94-cell strings in production environments
- **Hardware Optimized**: Efficient utilization of ATmega64M1 platform capabilities

For detailed technical assessment, see the [Implementation Status Report](../implementation-status.md).

This firmware provides a comprehensive foundation for intelligent battery module management with advanced monitoring, balancing, and data logging capabilities suitable for electric vehicle and energy storage applications.

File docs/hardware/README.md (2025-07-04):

# ATmega64M1 Hardware Platform

## Table of Contents

1. [Overview](#overview)
2. [Microcontroller Specifications](#microcontroller-specifications)
3. [Memory Architecture](#memory-architecture)
4. [Peripheral System](#peripheral-system)
5. [CAN Controller](#can-controller)
6. [Analog System](#analog-system)
7. [Power Management](#power-management)
8. [Pin Configuration](#pin-configuration)

## Overview

The ModuleCPU firmware runs on the ATmega64M1 microcontroller, a specialized 8-bit AVR designed for automotive and industrial applications. This platform provides integrated CAN communication, high-resolution ADC capabilities, and robust operation suitable for battery management systems.

### Key Hardware Advantages

**Integrated CAN Controller**
- Native CAN 2.0A/B support with hardware message filtering
- Up to 1 Mbps operation for high-speed communication
- 15 message objects with individual configuration
- Automatic error handling and bus-off recovery

**High-Resolution ADC**
- 12-bit successive approximation ADC
- 11 single-ended or 5 differential input channels
- Built-in gain amplifier for small signal measurement
- Low noise and high accuracy for precise cell monitoring

**Automotive-Grade Design**
- Extended temperature range (-40°C to +125°C)
- High noise immunity and EMI tolerance
- Robust I/O pins with ESD protection
- Automotive qualification (AEC-Q100)

## Microcontroller Specifications

### ATmega64M1 Core Features

```
ATmega64M1 Technical Specifications:
┌─────────────────────────────────────────────────────────────────┐
│                        Core Architecture                       │
├─────────────────────────────────────────────────────────────────┤
│ CPU:                  8-bit AVR Enhanced RISC Architecture     │
│ Operating Frequency:  Up to 16MHz (8MHz internal RC)           │
│ Performance:          16 MIPS at 16MHz                         │
│ Package:             64-pin TQFP (14mm x 14mm)                 │
│ Operating Voltage:    2.7V to 5.5V                            │
│ Operating Temperature: -40°C to +125°C (automotive grade)      │
├─────────────────────────────────────────────────────────────────┤
│                         Memory System                          │
├─────────────────────────────────────────────────────────────────┤
│ Flash Memory:         64KB (32K x 16-bit instructions)         │
│ SRAM:                4KB (data memory)                          │
│ EEPROM:              2KB (non-volatile storage)                │
│ Program Counter:      15-bit (addressing 32K instructions)     │
├─────────────────────────────────────────────────────────────────┤
│                      Instruction Set                           │
├─────────────────────────────────────────────────────────────────┤
│ Instructions:         131 powerful instructions                │
│ Execution:           Most instructions execute in 1 cycle      │
│ Addressing Modes:     13 different addressing modes            │
│ Multiply Unit:        8-bit x 8-bit → 16-bit (2 cycles)       │
└─────────────────────────────────────────────────────────────────┘
```

### Performance Characteristics

```c
// CPU performance metrics
#define CPU_FREQUENCY_MAX       16000000UL  // 16MHz maximum external
#define CPU_FREQUENCY_INTERNAL  8000000UL   // 8MHz internal RC (typical)
#define CPU_FREQUENCY_DEFAULT   8000000UL   // Default ModuleCPU setting

// Instruction timing
#define INSTRUCTION_CYCLE_NS    125         // 125ns per cycle @ 8MHz
#define MULTIPLY_CYCLES         2           // Hardware multiply timing
#define BRANCH_CYCLES           2           // Branch instruction timing
#define CALL_RETURN_CYCLES      4           // Function call/return timing

// Memory access times
#define FLASH_ACCESS_CYCLES     2           // Flash memory access
#define SRAM_ACCESS_CYCLES      1           // SRAM access
#define EEPROM_ACCESS_CYCLES    4           // EEPROM access (+ wait states)

// Interrupt response
#define INTERRUPT_LATENCY_MIN   4           // Minimum interrupt latency (cycles)
#define INTERRUPT_LATENCY_MAX   7           // Maximum interrupt latency (cycles)
#define CONTEXT_SAVE_CYCLES     20          // Context save/restore overhead
```

### Clock System Configuration

```c
// Clock system configuration for ModuleCPU
void SystemClock_Config(void) {
    // Configure internal 8MHz RC oscillator
    CLKPR = (1 << CLKPCE);          // Enable clock prescaler change
    CLKPR = 0x00;                   // No prescaling, full 8MHz
    
    // Alternative: External crystal configuration
    #ifdef USE_EXTERNAL_CRYSTAL
        // Configure for external 16MHz crystal
        CLKPR = (1 << CLKPCE);      // Enable clock prescaler change
        CLKPR = 0x01;               // Divide by 2, 8MHz from 16MHz crystal
    #endif
    
    // Configure peripheral clocks
    // Timer0 prescaler: /8 (1MHz timer clock)
    TCCR0B = (1 << CS01);
    
    // Timer1 prescaler: /256 (31.25kHz timer clock)
    TCCR1B = (1 << CS12);
    
    // CAN clock: derived from system clock
    // ADC clock: system clock / 64 (125kHz ADC clock)
    ADCSRA = (1 << ADEN) | (1 << ADPS2) | (1 << ADPS1);
}

// Precise timing functions
void DelayMicroseconds(uint16_t us) {
    // Precise delay using timer
    uint16_t timer_counts = (uint32_t)us * CPU_FREQUENCY_DEFAULT / 1000000UL;
    
    // Use Timer0 for short delays
    TCNT0 = 0;
    while (TCNT0 < (timer_counts / 8)) {
        // Wait for timer overflow
    }
}

void DelayMilliseconds(uint16_t ms) {
    for (uint16_t i = 0; i < ms; i++) {
        DelayMicroseconds(1000);
    }
}
```

## Memory Architecture

### Memory Map and Organization

```
ATmega64M1 Memory Map:
┌─────────────────────────────────────────────────────────┐ 0x0000
│                Flash Program Memory                     │
│                      (64KB)                            │
│  ┌─────────────────────────────────────────────────────┐ │ 0x0000
│  │              Interrupt Vector Table                 │ │ 0x002A
│  ├─────────────────────────────────────────────────────┤ │
│  │                Application Code                     │ │ 0x002A
│  │  • main() function and system initialization       │ │
│  │  • Cell monitoring and balancing algorithms        │ │
│  │  • CAN communication protocol handlers             │ │
│  │  • Data logging and storage functions              │ │
│  │  • Interrupt service routines                      │ │
│  ├─────────────────────────────────────────────────────┤ │ 0xE000
│  │              Configuration and Data                 │ │
│  │  • Factory default parameters                      │ │
│  │  • Calibration tables and constants                │ │
│  │  • String constants and lookup tables              │ │
│  └─────────────────────────────────────────────────────┘ │ 0xFFFF
├─────────────────────────────────────────────────────────┤
│                    SRAM Data Memory                     │ 0x0100
│                        (4KB)                           │
│  ┌─────────────────────────────────────────────────────┐ │ 0x0100
│  │              Register File + I/O                    │ │ 0x01FF
│  ├─────────────────────────────────────────────────────┤ │
│  │               Global Variables                      │ │ 0x0200
│  │  • Cell data arrays (94 cells max)                 │ │
│  │  • Module configuration structure                  │ │
│  │  • Communication buffers                           │ │
│  │  • Balancing control variables                     │ │
│  ├─────────────────────────────────────────────────────┤ │ 0x0800
│  │                  Heap Space                         │ │
│  │  • Dynamic memory allocation (if used)             │ │
│  │  • Temporary calculation buffers                   │ │
│  ├─────────────────────────────────────────────────────┤ │ 0x0C00
│  │                  Stack Space                        │ │
│  │  • Function call stack                              │ │
│  │  • Local variables                                  │ │
│  │  • Interrupt context storage                       │ │
│  └─────────────────────────────────────────────────────┘ │ 0x10FF
├─────────────────────────────────────────────────────────┤
│                  EEPROM Memory                          │ 0x0000
│                     (2KB)                              │
│  ┌─────────────────────────────────────────────────────┐ │ 0x0000
│  │              Configuration Header                   │ │ 0x0010
│  │  • Magic number and version information            │ │
│  │  • Configuration validity flags                    │ │
│  ├─────────────────────────────────────────────────────┤ │
│  │              Module Configuration                   │ │ 0x0010
│  │  • Module ID and hardware version                  │ │
│  │  • Cell count and operational parameters           │ │
│  │  • Voltage and temperature thresholds              │ │
│  │  • Balancing configuration                         │ │
│  ├─────────────────────────────────────────────────────┤ │ 0x0100
│  │              Calibration Data                       │ │
│  │  • ADC calibration coefficients                    │ │
│  │  • Temperature sensor calibration                  │ │
│  │  • Per-cell offset and gain corrections            │ │
│  ├─────────────────────────────────────────────────────┤ │ 0x0400
│  │              Factory Defaults                       │ │
│  │  • Original factory configuration                  │ │
│  │  • Fallback parameters                             │ │
│  │  • Manufacturing data                              │ │
│  ├─────────────────────────────────────────────────────┤ │ 0x0600
│  │              Fault History                          │ │
│  │  • Critical fault log                              │ │
│  │  • System reset history                            │ │
│  │  • Error counters                                  │ │
│  └─────────────────────────────────────────────────────┘ │ 0x07FF
└─────────────────────────────────────────────────────────┘
```

### Memory Usage Optimization

```c
// Memory allocation strategy for ModuleCPU
typedef struct {
    // Critical cell data (must be in fast access SRAM)
    CellData cells[TOTAL_CELL_COUNT_MAX];       // ~2.3KB for 94 cells
    
    // Module state and configuration (frequently accessed)
    ModuleConfiguration config;                  // ~512 bytes
    ModuleState current_state;                   // 4 bytes
    uint32_t system_time;                       // 4 bytes
    
    // Communication buffers
    CANMessage can_tx_buffer[8];                // ~144 bytes
    CANMessage can_rx_buffer[8];                // ~144 bytes
    uint8_t uart_debug_buffer[128];             // 128 bytes
    
    // Working memory for calculations
    uint16_t adc_readings[16];                  // 32 bytes
    uint8_t temp_calculation_buffer[64];        // 64 bytes
    
    // Total SRAM usage: ~3.4KB (85% of available 4KB)
} MemoryLayout;

// EEPROM layout definition
typedef struct {
    // Configuration header (16 bytes)
    uint32_t magic_number;                      // 0xDEADBEEF
    uint16_t version;                           // Configuration version
    uint16_t size;                              // Configuration size
    uint32_t checksum;                          // CRC32 checksum
    uint32_t timestamp;                         // Last update time
    
    // Module configuration (240 bytes)
    ModuleConfiguration module_config;
    
    // Calibration data (256 bytes)
    int16_t cell_voltage_offset[TOTAL_CELL_COUNT_MAX];  // Per-cell offset
    int16_t cell_temp_offset[TOTAL_CELL_COUNT_MAX];     // Per-cell temp offset
    uint16_t adc_reference_calibration;         // ADC reference voltage
    
    // Factory defaults (512 bytes)
    ModuleConfiguration factory_defaults;
    uint8_t manufacturing_data[256];            // Manufacturing test data
    
    // Fault history (1KB)
    FaultHistoryEntry fault_log[32];            // 32 fault entries
    uint16_t reset_count;                       // System reset counter
    uint16_t error_counters[16];                // Various error counters
    
    // Reserved space (remainder)
    uint8_t reserved[256];                      // Future expansion
    
} EEPROMLayout;

// Memory protection and validation
bool ValidateMemoryIntegrity(void) {
    // Check stack pointer validity
    uint16_t sp = SP;
    if (sp < 0x0200 || sp > 0x10FF) {
        return false;   // Stack pointer out of valid range
    }
    
    // Check for stack overflow
    extern uint8_t __heap_start;
    if (sp < (uint16_t)&__heap_start + 64) {
        return false;   // Stack collision with heap
    }
    
    // Validate critical data structures
    if (!ValidateConfigurationChecksum()) {
        return false;   // Configuration corrupted
    }
    
    return true;
}
```

## Peripheral System

### Timer/Counter System

```c
// Timer configuration for ModuleCPU
typedef struct {
    uint8_t timer_id;               // Timer number (0, 1)
    uint16_t prescaler;             // Clock prescaler value
    uint16_t compare_value;         // Compare match value
    bool overflow_interrupt;        // Enable overflow interrupt
    bool compare_interrupt;         // Enable compare match interrupt
    void (*callback)(void);         // Interrupt callback function
} TimerConfig;

// Timer0 configuration (8-bit timer for system tick)
void Timer0_Init(void) {
    // Configure Timer0 for 100ms periodic interrupt
    TCCR0A = (1 << WGM01);          // CTC mode
    TCCR0B = (1 << CS01);           // Prescaler /8
    OCR0A = PERIODIC_COMPARE_A_RELOAD;  // Compare value for 100ms
    TIMSK0 = (1 << OCIE0A);         // Enable compare interrupt
}

// Timer0 interrupt service routine
ISR(TIMER0_COMPA_vect) {
    static uint16_t tick_counter = 0;
    
    // Increment system tick counter
    tick_counter++;
    
    // Set periodic task flag every 300ms (3 ticks)
    if (tick_counter >= PERIODIC_CALLBACK_RATE_TICKS) {
        tick_counter = 0;
        periodicTaskFlag = true;
        
        // Toggle frame type for alternating read/write operations
        currentFrameType = (currentFrameType == EFRAMETYPE_READ) ? 
                          EFRAMETYPE_WRITE : EFRAMETYPE_READ;
    }
    
    // Refresh watchdog timer
    #ifdef WDT_ENABLE
        wdt_reset();
    #endif
}

// Timer1 configuration (16-bit timer for precise timing)
void Timer1_Init(void) {
    // Configure Timer1 for virtual UART bit timing
    TCCR1A = 0;                     // Normal mode
    TCCR1B = (1 << CS12);           // Prescaler /256
    TIMSK1 = (1 << TOIE1);          // Enable overflow interrupt
}

// Precise delay using Timer1
void DelayPrecise(uint16_t microseconds) {
    uint16_t timer_counts = (uint32_t)microseconds * 
                           (CPU_FREQUENCY_DEFAULT / 256) / 1000000UL;
    
    TCNT1 = 0xFFFF - timer_counts;  // Load timer for desired delay
    TIFR1 = (1 << TOV1);            // Clear overflow flag
    
    while (!(TIFR1 & (1 << TOV1))); // Wait for overflow
}
```

### SPI Interface

```c
// SPI configuration for SD card interface
typedef struct {
    uint8_t mode;                   // SPI mode (0-3)
    uint8_t bit_order;              // MSB or LSB first
    uint8_t clock_divider;          // SPI clock divider
    bool interrupt_enabled;         // SPI interrupt enable
} SPIConfig;

void SPI_Init(void) {
    // Configure SPI pins
    DDRB |= (1 << PB2) | (1 << PB1) | (1 << PB0);  // MOSI, SCK, SS as outputs
    DDRB &= ~(1 << PB3);                            // MISO as input
    
    // Configure SPI control register
    SPCR = (1 << SPE) |             // Enable SPI
           (1 << MSTR) |            // Master mode
           (1 << SPR1);             // Clock rate fck/64 (125kHz @ 8MHz)
    
    // Set SS high (deselect all devices)
    PORTB |= (1 << PB0);
}

uint8_t SPI_TransferByte(uint8_t data) {
    // Start transmission
    SPDR = data;
    
    // Wait for transmission complete
    while (!(SPSR & (1 << SPIF)));
    
    // Return received data
    return SPDR;
}

void SPI_TransferBlock(uint8_t* tx_data, uint8_t* rx_data, uint16_t length) {
    for (uint16_t i = 0; i < length; i++) {
        uint8_t tx_byte = tx_data ? tx_data[i] : 0xFF;
        uint8_t rx_byte = SPI_TransferByte(tx_byte);
        if (rx_data) {
            rx_data[i] = rx_byte;
        }
    }
}
```

### I2C/TWI Interface

```c
// I2C configuration for RTC communication
typedef enum {
    I2C_SUCCESS = 0,
    I2C_ERROR_START,
    I2C_ERROR_SLAW,
    I2C_ERROR_DATA,
    I2C_ERROR_STOP
} I2CResult;

void I2C_Init(void) {
    // Set SCL frequency to 100kHz
    TWBR = ((CPU_FREQUENCY_DEFAULT / 100000UL) - 16) / 2;
    TWSR = 0;                       // Prescaler = 1
    
    // Enable TWI
    TWCR = (1 << TWEN);
}

I2CResult I2C_Start(void) {
    // Send start condition
    TWCR = (1 << TWINT) | (1 << TWSTA) | (1 << TWEN);
    
    // Wait for start condition to be transmitted
    while (!(TWCR & (1 << TWINT)));
    
    // Check status
    if ((TWSR & 0xF8) != 0x08) {
        return I2C_ERROR_START;
    }
    
    return I2C_SUCCESS;
}

I2CResult I2C_SendAddress(uint8_t address) {
    // Load address into data register
    TWDR = address;
    TWCR = (1 << TWINT) | (1 << TWEN);
    
    // Wait for transmission
    while (!(TWCR & (1 << TWINT)));
    
    // Check status
    uint8_t status = TWSR & 0xF8;
    if (status != 0x18 && status != 0x40) {
        return I2C_ERROR_SLAW;
    }
    
    return I2C_SUCCESS;
}

I2CResult I2C_SendData(uint8_t data) {
    // Load data into data register
    TWDR = data;
    TWCR = (1 << TWINT) | (1 << TWEN);
    
    // Wait for transmission
    while (!(TWCR & (1 << TWINT)));
    
    // Check status
    if ((TWSR & 0xF8) != 0x28) {
        return I2C_ERROR_DATA;
    }
    
    return I2C_SUCCESS;
}

void I2C_Stop(void) {
    // Send stop condition
    TWCR = (1 << TWINT) | (1 << TWSTO) | (1 << TWEN);
    
    // Wait for stop condition to be executed
    while (TWCR & (1 << TWSTO));
}
```

## CAN Controller

### CAN Controller Architecture

```c
// CAN controller configuration
typedef struct {
    uint32_t baudrate;              // CAN bus baudrate
    uint8_t sample_point;           // Sample point percentage
    bool loopback_mode;             // Loopback mode for testing
    bool listen_only_mode;          // Listen-only mode
    bool automatic_retransmission;  // Automatic retransmission
    uint8_t error_warning_limit;    // Error warning limit
} CANConfig;

// CAN message object configuration
typedef struct {
    uint8_t mob_number;             // Message object number (0-14)
    uint32_t identifier;            // CAN identifier
    uint32_t mask;                  // Acceptance mask
    uint8_t data_length;            // Data length code
    bool extended_id;               // Extended identifier flag
    bool remote_frame;              // Remote frame flag
    bool receive_mode;              // Receive mode (true) or transmit (false)
} CANMessageObject;

void CAN_Init(void) {
    // Reset CAN controller
    CANGCON = (1 << SWRES);
    
    // Wait for reset completion
    while (CANGCON & (1 << SWRES));
    
    // Configure CAN timing for 500kbps
    // Assuming 8MHz system clock
    CANBT1 = 0x02;                  // BRP = 2 (4MHz CAN clock)
    CANBT2 = 0x04;                  // SJW = 1, PRS = 4
    CANBT3 = 0x13;                  // PHS2 = 2, PHS1 = 4
    // Total: 1 + 4 + 4 + 2 = 11 TQ, 4MHz/11 ≈ 364kbps
    
    // Enable CAN controller
    CANGCON = (1 << ENASTB);
    
    // Wait for CAN controller to be enabled
    while (!(CANGSTA & (1 << ENFG)));
    
    // Configure message objects
    ConfigureCANMessageObjects();
    
    // Enable CAN interrupts
    CANGIE = (1 << ENIT) | (1 << ENRX) | (1 << ENTX);
}

void ConfigureCANMessageObjects(void) {
    // Configure MOb 0 for receiving pack controller commands
    SelectMessageObject(0);
    CANCDMOB = (1 << CONMOB1);      // Receive mode
    CANIDT1 = (CAN_ID_PACK_COMMAND >> 3);  // Set identifier
    CANIDT2 = (CAN_ID_PACK_COMMAND << 5);
    CANIDM1 = 0xFF;                 // Exact match mask
    CANIDM2 = 0xE0;
    
    // Configure MOb 1 for transmitting module status
    SelectMessageObject(1);
    CANCDMOB = 0;                   // Disabled initially
    CANIDT1 = (GetModuleCANID() >> 3);
    CANIDT2 = (GetModuleCANID() << 5);
    
    // Configure additional message objects as needed
    for (uint8_t mob = 2; mob < 15; mob++) {
        SelectMessageObject(mob);
        CANCDMOB = 0;               // Disable unused MObs
    }
}

bool CAN_SendMessage(const CANMessage* message) {
    // Find available transmit MOb
    uint8_t mob = FindAvailableTransmitMOb();
    if (mob == 0xFF) {
        return false;               // No available MOb
    }
    
    // Select message object
    SelectMessageObject(mob);
    
    // Set identifier
    CANIDT1 = (message->id >> 3);
    CANIDT2 = (message->id << 5);
    
    // Set data length
    CANCDMOB = (1 << CONMOB0) | (message->length & 0x0F);
    
    // Load data
    for (uint8_t i = 0; i < message->length; i++) {
        CANMSG = message->data[i];
    }
    
    // Start transmission
    CANCDMOB |= (1 << CONMOB0);
    
    return true;
}

// CAN interrupt service routine
ISR(CAN_INT_vect) {
    uint8_t interrupt_source = CANGIT;
    
    if (interrupt_source & (1 << CANIT)) {
        // General CAN interrupt
        ProcessCANGeneralInterrupt();
    }
    
    if (interrupt_source & (1 << OVRTIM)) {
        // Overrun timer interrupt
        ProcessCANOverrunInterrupt();
    }
    
    if (interrupt_source & (1 << BOFFIT)) {
        // Bus-off interrupt
        ProcessCANBusOffInterrupt();
    }
    
    // Clear interrupt flags
    CANGIT = interrupt_source;
}
```

## Analog System

### ADC Configuration and Operation

```c
// ADC configuration for cell monitoring
typedef struct {
    uint8_t reference;              // Voltage reference selection
    uint8_t prescaler;              // ADC clock prescaler
    bool left_adjust;               // Result left adjustment
    bool differential_mode;         // Differential input mode
    uint8_t gain;                   // Gain amplifier setting
} ADCConfig;

void ADC_Init(void) {
    // Configure ADC reference (AVCC with external capacitor)
    ADMUX = (1 << REFS0);
    
    // Configure ADC prescaler for 125kHz ADC clock (8MHz/64)
    ADCSRA = (1 << ADEN) |          // Enable ADC
             (1 << ADPS2) |         // Prescaler /64
             (1 << ADPS1);
    
    // Configure gain amplifier (1x gain initially)
    ADCSRB = 0;
    
    // Perform initial conversion to stabilize ADC
    ADMUX = (1 << REFS0);           // Select channel 0
    ADCSRA |= (1 << ADSC);          // Start conversion
    while (ADCSRA & (1 << ADSC));   // Wait for completion
    (void)ADC;                      // Discard result
}

uint16_t ADC_ReadChannel(uint8_t channel) {
    // Validate channel number
    if (channel > 10) {
        return 0;
    }
    
    // Select channel
    ADMUX = (ADMUX & 0xF0) | (channel & 0x0F);
    
    // Start conversion
    ADCSRA |= (1 << ADSC);
    
    // Wait for conversion complete
    while (ADCSRA & (1 << ADSC));
    
    // Return result
    return ADC;
}

uint16_t ADC_ReadDifferential(uint8_t positive, uint8_t negative, uint8_t gain) {
    // Configure differential mode
    uint8_t channel_select;
    
    // Determine differential channel selection
    if (positive == 0 && negative == 1) {
        channel_select = 0x08;      // ADC0 - ADC1
    } else if (positive == 2 && negative == 3) {
        channel_select = 0x0A;      // ADC2 - ADC3
    } else {
        return 0;                   // Invalid differential pair
    }
    
    // Configure gain amplifier
    switch (gain) {
        case 1:  ADCSRB = 0; break;                    // 1x gain
        case 10: ADCSRB = (1 << GSEL); break;          // 10x gain
        case 20: ADCSRB = (1 << GSEL) | (1 << AREFEN); break;  // 20x gain
        default: return 0;          // Invalid gain
    }
    
    // Select differential channel
    ADMUX = (ADMUX & 0xF0) | channel_select;
    
    // Start conversion
    ADCSRA |= (1 << ADSC);
    
    // Wait for conversion complete
    while (ADCSRA & (1 << ADSC));
    
    // Return result
    return ADC;
}

// Cell voltage measurement with calibration
uint16_t MeasureCellVoltage(uint8_t cell_index) {
    // Validate cell index
    if (cell_index >= TOTAL_CELL_COUNT_MAX) {
        return 0;
    }
    
    // Calculate ADC channel for this cell
    uint8_t adc_channel = CalculateADCChannel(cell_index);
    
    // Read raw ADC value
    uint16_t raw_value = ADC_ReadChannel(adc_channel);
    
    // Apply calibration correction
    int16_t offset = GetCellVoltageOffset(cell_index);
    int32_t corrected_value = (int32_t)raw_value + offset;
    
    // Clamp to valid range
    if (corrected_value < 0) corrected_value = 0;
    if (corrected_value > 4095) corrected_value = 4095;
    
    return (uint16_t)corrected_value;
}

// Convert ADC reading to millivolts
uint16_t ADCToMillivolts(uint16_t adc_value) {
    // Assuming 5V reference and 12-bit ADC
    // 5000mV / 4096 counts = 1.22mV per count
    return (uint32_t)adc_value * 5000UL / 4096UL;
}

// Temperature measurement using internal sensor or thermistor
int16_t MeasureTemperature(uint8_t sensor_index) {
    uint16_t adc_value;
    
    if (sensor_index == 0xFF) {
        // Internal temperature sensor
        ADMUX = (1 << REFS1) | (1 << REFS0) | 0x0F;  // 1.1V ref, temp sensor
        ADCSRA |= (1 << ADSC);
        while (ADCSRA & (1 << ADSC));
        adc_value = ADC;
        
        // Convert to temperature (datasheet formula)
        int32_t temp = (adc_value - 314) * 1000 / 1.22;  // Rough conversion
        return (int16_t)temp;
    } else {
        // External thermistor
        adc_value = ADC_ReadChannel(GetTemperatureSensorChannel(sensor_index));
        
        // Convert using Steinhart-Hart equation or lookup table
        return ConvertThermistorToTemperature(adc_value);
    }
}
```

## Power Management

### Low Power Operation

```c
// Power management configuration
typedef enum {
    SLEEP_MODE_IDLE,                // CPU stopped, peripherals running
    SLEEP_MODE_ADC_NOISE_REDUCTION, // CPU and I/O stopped, ADC running
    SLEEP_MODE_POWER_DOWN,          // All clocks stopped except async
    SLEEP_MODE_POWER_SAVE,          // Timer2 async operation allowed
    SLEEP_MODE_STANDBY,             // Crystal oscillator running
    SLEEP_MODE_EXTENDED_STANDBY     // Crystal + Timer2 running
} SleepMode;

void PowerManagement_Init(void) {
    // Configure power reduction register
    PRR = (1 << PRLIN) |           // Disable LIN
          (1 << PRSPI) |           // Disable SPI (enable when needed)
          (1 << PRTIM1);           // Disable Timer1 (enable when needed)
    
    // Configure unused pins as inputs with pull-ups to save power
    ConfigureUnusedPinsForLowPower();
    
    // Enable sleep mode
    SMCR = (1 << SE);
}

void EnterSleepMode(SleepMode mode) {
    // Set sleep mode
    switch (mode) {
        case SLEEP_MODE_IDLE:
            SMCR = (1 << SE);
            break;
        case SLEEP_MODE_ADC_NOISE_REDUCTION:
            SMCR = (1 << SE) | (1 << SM0);
            break;
        case SLEEP_MODE_POWER_DOWN:
            SMCR = (1 << SE) | (1 << SM1);
            break;
        case SLEEP_MODE_POWER_SAVE:
            SMCR = (1 << SE) | (1 << SM1) | (1 << SM0);
            break;
    }
    
    // Disable unnecessary peripherals
    DisableNonEssentialPeripherals();
    
    // Enter sleep mode
    __asm__ __volatile__ ("sleep" ::: "memory");
    
    // Re-enable peripherals after wake
    EnablePeripherals();
}

void ConfigureUnusedPinsForLowPower(void) {
    // Configure unused pins as inputs with pull-ups
    // This prevents floating inputs which can cause increased current consumption
    
    // Port A - configure unused pins
    DDRA &= ~((1 << PA0) | (1 << PA1));  // Set as inputs
    PORTA |= (1 << PA0) | (1 << PA1);    // Enable pull-ups
    
    // Port B - configure unused pins
    DDRB &= ~(1 << PB4);                 // Set as input
    PORTB |= (1 << PB4);                 // Enable pull-up
    
    // Repeat for other unused pins on ports C and D
}

// Watchdog timer configuration
void Watchdog_Init(void) {
    #ifdef WDT_ENABLE
        // Reset watchdog timer
        wdt_reset();
        
        // Configure watchdog for 2 second timeout
        WDTCSR = (1 << WDCE) | (1 << WDE);
        WDTCSR = (1 << WDE) | (1 << WDP2) | (1 << WDP1) | (1 << WDP0);
    #endif
}

void Watchdog_Reset(void) {
    #ifdef WDT_ENABLE
        wdt_reset();
    #endif
}

// Power consumption estimates
typedef struct {
    const char* mode_name;
    float current_ma_typical;       // Typical current consumption (mA)
    float current_ma_max;           // Maximum current consumption (mA)
    const char* description;
} PowerConsumptionSpec;

static const PowerConsumptionSpec power_specs[] = {
    {"Active @ 8MHz",     15.0,  20.0,  "Full operation, all peripherals"},
    {"Idle",              8.0,   12.0,  "CPU stopped, peripherals active"},
    {"ADC Noise Reduction", 6.0,  8.0,   "CPU stopped, ADC running"},
    {"Power Save",        2.0,   3.0,   "Async Timer2 operation only"},
    {"Power Down",        0.5,   1.0,   "All clocks stopped"},
    {"Standby",           0.8,   1.2,   "Crystal oscillator running"}
};
```

## Pin Configuration

### Pin Assignment and Mapping

```c
// Pin definitions for ModuleCPU
// Note: Actual pin assignments depend on hardware design

// ADC input pins for cell monitoring
#define ADC_CELL_START_PIN      ADC0        // First cell ADC input
#define ADC_CELL_COUNT          11          // Number of ADC channels
#define ADC_TEMP_SENSOR_PIN     ADC10       // Temperature sensor input

// CAN interface pins (built-in controller)
#define CAN_RX_PIN              PC2         // CAN RX input
#define CAN_TX_PIN              PC3         // CAN TX output

// SPI pins for SD card interface
#define SPI_MOSI_PIN            PB2         // Master Out Slave In
#define SPI_MISO_PIN            PB3         // Master In Slave Out
#define SPI_SCK_PIN             PB1         // Serial Clock
#define SPI_SS_PIN              PB0         // Slave Select

// I2C pins for RTC interface
#define I2C_SDA_PIN             PC1         // Serial Data
#define I2C_SCL_PIN             PC0         // Serial Clock

// Control pins for balancing circuits
#define BALANCE_FET_ENABLE      PD0         // FET balancing enable
#define BALANCE_RELAY_ENABLE    PD1         // Relay balancing enable
#define BALANCE_FET_CONTROL     PD2         // FET control signal
#define BALANCE_RELAY_CONTROL   PD3         // Relay control signal

// Status and debug pins
#define LED_STATUS_PIN          PD4         // Status LED
#define LED_FAULT_PIN           PD5         // Fault LED
#define DEBUG_TX_PIN            PD6         // Debug UART TX
#define DEBUG_RX_PIN            PD7         // Debug UART RX

// GPIO configuration function
void GPIO_Init(void) {
    // Configure ADC pins as inputs (default state)
    DDRA = 0x00;                    // All Port A as inputs
    PORTA = 0x00;                   // No pull-ups on ADC pins
    
    // Configure SPI pins
    DDRB |= (1 << SPI_MOSI_PIN) | (1 << SPI_SCK_PIN) | (1 << SPI_SS_PIN);
    DDRB &= ~(1 << SPI_MISO_PIN);   // MISO as input
    PORTB |= (1 << SPI_SS_PIN);     // SS high (deselected)
    
    // Configure I2C pins as inputs with pull-ups
    DDRC &= ~((1 << I2C_SDA_PIN) | (1 << I2C_SCL_PIN));
    PORTC |= (1 << I2C_SDA_PIN) | (1 << I2C_SCL_PIN);
    
    // Configure CAN pins
    DDRC &= ~(1 << CAN_RX_PIN);     // RX as input
    DDRC |= (1 << CAN_TX_PIN);      // TX as output
    
    // Configure control pins as outputs
    DDRD |= (1 << BALANCE_FET_ENABLE) | (1 << BALANCE_RELAY_ENABLE) |
            (1 << BALANCE_FET_CONTROL) | (1 << BALANCE_RELAY_CONTROL) |
            (1 << LED_STATUS_PIN) | (1 << LED_FAULT_PIN);
    
    // Configure debug pins
    DDRD |= (1 << DEBUG_TX_PIN);    // TX as output
    DDRD &= ~(1 << DEBUG_RX_PIN);   // RX as input
    PORTD |= (1 << DEBUG_RX_PIN);   // Pull-up on RX
    
    // Initialize outputs to safe states
    PORTD &= ~((1 << BALANCE_FET_ENABLE) | (1 << BALANCE_RELAY_ENABLE) |
               (1 << BALANCE_FET_CONTROL) | (1 << BALANCE_RELAY_CONTROL));
    PORTD &= ~((1 << LED_STATUS_PIN) | (1 << LED_FAULT_PIN));
}

// Pin manipulation functions
void SetBalanceFETEnable(bool enable) {
    if (enable) {
        PORTD |= (1 << BALANCE_FET_ENABLE);
    } else {
        PORTD &= ~(1 << BALANCE_FET_ENABLE);
    }
}

void SetBalanceRelayEnable(bool enable) {
    if (enable) {
        PORTD |= (1 << BALANCE_RELAY_ENABLE);
    } else {
        PORTD &= ~(1 << BALANCE_RELAY_ENABLE);
    }
}

void SetStatusLED(bool on) {
    if (on) {
        PORTD |= (1 << LED_STATUS_PIN);
    } else {
        PORTD &= ~(1 << LED_STATUS_PIN);
    }
}

void SetFaultLED(bool on) {
    if (on) {
        PORTD |= (1 << LED_FAULT_PIN);
    } else {
        PORTD &= ~(1 << LED_FAULT_PIN);
    }
}

// Pin state reading functions
bool GetBalanceFETStatus(void) {
    return (PORTD & (1 << BALANCE_FET_ENABLE)) != 0;
}

bool GetBalanceRelayStatus(void) {
    return (PORTD & (1 << BALANCE_RELAY_ENABLE)) != 0;
}
```

This comprehensive hardware documentation provides the foundation for understanding the ATmega64M1 platform capabilities and configuration for the ModuleCPU firmware. The integrated CAN controller, high-resolution ADC, and automotive-grade design make it ideal for battery module management applications.

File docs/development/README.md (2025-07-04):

# Development Environment Setup

## Table of Contents

1. [Overview](#overview)
2. [Required Tools](#required-tools)
3. [Microchip Studio Setup](#microchip-studio-setup)
4. [Project Configuration](#project-configuration)
5. [Build System](#build-system)
6. [Debugging Setup](#debugging-setup)
7. [Testing and Validation](#testing-and-validation)
8. [Code Quality Tools](#code-quality-tools)

## Overview

The ModuleCPU firmware is developed using Microchip Studio (formerly Atmel Studio) with the XC8 compiler toolchain. This document provides comprehensive setup instructions for establishing a complete development environment for the ATmega64M1-based module controller firmware.

### Development Stack
```
Development Environment Stack:
├── IDE: Microchip Studio 7.0
├── Compiler: Microchip XC8 v2.36
├── Debugger: Atmel-ICE or similar
├── Target: ATmega64M1 microcontroller
├── Build System: MSBuild (Visual Studio compatible)
├── Version Control: Git
└── Documentation: Markdown + diagrams
```

## Required Tools

### Essential Software

#### 1. Microchip Studio 7.0
- **Purpose**: Primary IDE for AVR development
- **Download**: [Microchip Studio](https://www.microchip.com/mplab/microchip-studio)
- **Version**: 7.0.2594 or later
- **Features**: Integrated debugger, project management, code editor

#### 2. Microchip XC8 Compiler
- **Purpose**: C compiler for AVR microcontrollers
- **Version**: v2.36 or compatible
- **License**: Free version available (optimization restrictions)
- **Installation**: Integrated with Microchip Studio

#### 3. Git for Windows
- **Purpose**: Version control system
- **Download**: [Git SCM](https://git-scm.com/download/win)
- **Configuration**: Required for source code management

### Hardware Tools

#### 1. Programming/Debugging Interface
```
Recommended Debuggers:
├── Atmel-ICE (Primary recommendation)
│   ├── Interfaces: SWD, JTAG, debugWIRE, PDI, TPI
│   ├── Voltage Range: 1.8V to 5.5V
│   ├── Current Capability: 300mA
│   └── USB Interface: High-speed USB 2.0
├── AVR Dragon (Alternative)
│   ├── Interfaces: JTAG, debugWIRE, ISP, HVPP
│   ├── Voltage Range: 1.8V to 5.5V
│   └── USB Interface: Full-speed USB
└── AVRISP mkII (ISP only)
    ├── Interface: ISP (In-System Programming)
    ├── Voltage Range: 1.8V to 5.5V
    └── USB Interface: Full-speed USB
```

#### 2. Development Hardware
- **Target Board**: ModuleCPU hardware or equivalent
- **Power Supply**: 5V regulated supply
- **CAN Interface**: CAN transceiver for network testing
- **SD Card**: For data logging testing
- **Oscilloscope**: For signal analysis (optional but recommended)

## Microchip Studio Setup

### Installation Process

1. **Download Microchip Studio**
   ```
   1. Visit: https://www.microchip.com/mplab/microchip-studio
   2. Download: Microchip Studio 7.0 Installer
   3. Size: ~800MB download
   4. Requirements: Windows 7 SP1 or later
   ```

2. **Installation Steps**
   ```
   1. Run installer as Administrator
   2. Select "Complete" installation
   3. Accept license agreements
   4. Install to default location: C:\Program Files (x86)\Atmel\Studio\7.0\
   5. Allow Windows Defender/Firewall exceptions
   6. Restart computer when prompted
   ```

3. **Initial Configuration**
   ```
   1. Launch Microchip Studio
   2. Skip online activation (optional)
   3. Configure XC8 compiler path if not auto-detected
   4. Install AVR Device Packs if prompted
   5. Configure debugger drivers
   ```

### XC8 Compiler Configuration

```c
// Project compiler settings (Release configuration)
Compiler Flags:
├── Optimization Level: -Os (Optimize for size)
├── C Standard: C99
├── Character Type: Unsigned char
├── Bit Field Type: Unsigned
├── Warning Level: All warnings (-Wall)
├── Additional Flags: -fpack-struct, -fshort-enums
└── Debug Information: Minimal (-g1 for release)

// Linker settings
Linker Flags:
├── Libraries: libm (math library)
├── Memory Model: Default
├── Stack Size: Default (handled by hardware)
└── Optimization: Remove unused sections
```

### Debug Configuration

```c
// Debug build settings
Debug Configuration:
├── Optimization Level: -Og (Optimize for debugging)
├── Debug Information: Full (-g3)
├── Preprocessor: DEBUG=1
├── Runtime Checks: Enabled
├── Stack Protection: Enabled (if available)
└── Assertions: Enabled
```

## Project Configuration

### Project Structure Setup

```
Project Organization:
ModuleCPU/
├── Source Files/
│   ├── main.c                  # Main application
│   ├── adc.c                   # ADC driver
│   ├── can.c                   # CAN communication
│   ├── vUART.c                 # Virtual UART
│   ├── STORE.c                 # Storage management
│   ├── EEPROM.c                # EEPROM functions
│   ├── SD.c                    # SD card interface
│   ├── SPI.c                   # SPI driver
│   ├── I2c.c                   # I2C driver
│   ├── rtc_mcp7940n.c         # RTC driver
│   └── debugSerial.c           # Debug interface
├── Header Files/
│   ├── main.h                  # Main definitions
│   ├── adc.h                   # ADC interface
│   ├── can.h                   # CAN interface
│   ├── can_ids.h               # CAN message IDs
│   ├── vUART.h                 # Virtual UART interface
│   ├── STORE.h                 # Storage interface
│   ├── EEPROM.h                # EEPROM interface
│   ├── SD.h                    # SD card interface
│   ├── SPI.h                   # SPI interface
│   ├── I2c.h                   # I2C interface
│   ├── rtc_mcp7940n.h         # RTC interface
│   └── debugSerial.h           # Debug interface
├── Shared/
│   └── Shared.h                # Common definitions
├── Debug/                      # Debug build output
├── Release/                    # Release build output
└── ModuleCPU.cproj            # Project file
```

### Project File Configuration

The `ModuleCPU.cproj` file contains essential project settings:

```xml
<!-- Key project properties -->
<PropertyGroup>
  <SchemaVersion>2.0</SchemaVersion>
  <ProjectVersion>7.0</ProjectVersion>
  <ToolchainName>com.microchip.xc8</ToolchainName>
  <ProjectGuid>{2285C48D-296E-43FD-A7B6-69885F64CFFD}</ProjectGuid>
  <avrdevice>ATmega64M1</avrdevice>
  <OutputType>Executable</OutputType>
  <Language>C</Language>
  <ToolchainFlavour>XC8_2.36</ToolchainFlavour>
  <KeepTimersRunning>true</KeepTimersRunning>
  <preserveEEPROM>true</preserveEEPROM>
</PropertyGroup>

<!-- Debug configuration -->
<PropertyGroup Condition=" '$(Configuration)' == 'Debug' ">
  <ToolchainSettings>
    <com.microchip.xc8>
      <com.microchip.xc8.compiler.optimization.level>Optimize debugging experience (-Og)</com.microchip.xc8.compiler.optimization.level>
      <com.microchip.xc8.compiler.optimization.DebugLevel>Default (-g2)</com.microchip.xc8.compiler.optimization.DebugLevel>
      <com.microchip.xc8.compiler.warnings.AllWarnings>True</com.microchip.xc8.compiler.warnings.AllWarnings>
    </com.microchip.xc8>
  </ToolchainSettings>
</PropertyGroup>

<!-- Release configuration -->
<PropertyGroup Condition=" '$(Configuration)' == 'Release' ">
  <ToolchainSettings>
    <com.microchip.xc8>
      <com.microchip.xc8.compiler.optimization.level>Optimize for size (-Os)</com.microchip.xc8.compiler.optimization.level>
      <com.microchip.xc8.compiler.optimization.PackStructureMembers>True</com.microchip.xc8.compiler.optimization.PackStructureMembers>
      <com.microchip.xc8.compiler.optimization.AllocateBytesNeededForEnum>True</com.microchip.xc8.compiler.optimization.AllocateBytesNeededForEnum>
    </com.microchip.xc8>
  </ToolchainSettings>
</PropertyGroup>
```

### Include Paths and Dependencies

```c
// Include path configuration
Include Directories:
├── Project Root (./)
├── Shared Directory (../Shared)
├── XC8 System Includes (automatic)
└── AVR Libc Includes (automatic)

// Library Dependencies
Libraries:
├── libm (math library)
├── avr-libc (standard C library for AVR)
└── XC8 Runtime Libraries (automatic)

// Preprocessor Definitions
Debug Build:
├── DEBUG=1
├── F_CPU=8000000UL
└── __AVR_ATmega64M1__

Release Build:
├── NDEBUG=1
├── F_CPU=8000000UL
└── __AVR_ATmega64M1__
```

## Build System

### Build Process Overview

```
Build Process Flow:
├── Preprocessing
│   ├── Macro expansion
│   ├── Include file processing
│   ├── Conditional compilation
│   └── Comment removal
├── Compilation
│   ├── C to assembly translation
│   ├── Optimization passes
│   ├── Warning generation
│   └── Object file creation
├── Assembly
│   ├── Assembly to machine code
│   ├── Symbol table generation
│   └── Relocation information
├── Linking
│   ├── Object file combination
│   ├── Library linking
│   ├── Address resolution
│   └── Executable generation
└── Output Generation
    ├── .elf file (executable)
    ├── .hex file (Intel HEX)
    ├── .lss file (listing)
    └── .map file (memory map)
```

### Memory Configuration

```c
// ATmega64M1 memory layout
Memory Configuration:
├── Flash Memory (64KB)
│   ├── Bootloader Section: 0x0000-0x0FFF (4KB)
│   ├── Application Section: 0x1000-0xFFFF (60KB)
│   └── Fuse/Lock Bits: Separate area
├── SRAM (4KB)
│   ├── Register File: 0x0000-0x001F (32 bytes)
│   ├── I/O Space: 0x0020-0x005F (64 bytes)
│   ├── Extended I/O: 0x0060-0x00FF (160 bytes)
│   └── Internal SRAM: 0x0100-0x10FF (4096 bytes)
├── EEPROM (2KB)
│   ├── Address Range: 0x0000-0x07FF
│   ├── Page Size: 8 bytes
│   └── Endurance: 100,000 cycles
└── Fuses
    ├── Low Fuse: Clock configuration
    ├── High Fuse: Boot loader and debug
    └── Extended Fuse: BOD and startup
```

### Build Commands

```bash
# Manual build commands (if needed)

# Compile individual source file
xc8-cc -mcpu=ATmega64M1 -c -fshort-enums -fpack-struct -O2 -Wall -o main.o main.c

# Link object files
xc8-cc -mcpu=ATmega64M1 -Wl,-Map=ModuleCPU.map -o ModuleCPU.elf main.o adc.o can.o ... -lm

# Generate Intel HEX file
avr-objcopy -O ihex -R .eeprom ModuleCPU.elf ModuleCPU.hex

# Generate EEPROM HEX file
avr-objcopy -j .eeprom --set-section-flags=.eeprom=alloc,load --change-section-lma .eeprom=0 -O ihex ModuleCPU.elf ModuleCPU.eep

# Generate listing file
avr-objdump -h -S ModuleCPU.elf > ModuleCPU.lss
```

## Debugging Setup

### Hardware Configuration

```
Debugger Setup (Atmel-ICE):
├── Physical Connections
│   ├── USB: Computer to Atmel-ICE
│   ├── Target Cable: 6-pin or 10-pin ISP
│   ├── Power: From target board (5V)
│   └── debugWIRE: Single-wire debug interface
├── Interface Configuration
│   ├── Interface: debugWIRE
│   ├── Clock Speed: 125kHz (for debugging)
│   ├── Target Voltage: Auto-detect
│   └── Programming Mode: ISP for initial programming
└── Software Configuration
    ├── Tool: Atmel-ICE in Microchip Studio
    ├── Device: ATmega64M1
    ├── Interface: debugWIRE
    └── Clock: 125kHz
```

### Debug Configuration Steps

1. **Hardware Setup**
   ```
   1. Connect Atmel-ICE to computer via USB
   2. Connect ISP cable to target board
   3. Ensure target board is powered (5V)
   4. Verify connection in Device Manager
   ```

2. **Software Configuration**
   ```
   1. Open ModuleCPU project in Microchip Studio
   2. Go to Project > ModuleCPU Properties
   3. Select "Tool" tab
   4. Choose "Atmel-ICE" from dropdown
   5. Select "debugWIRE" interface
   6. Set clock to 125kHz
   7. Click "Apply"
   ```

3. **Enable debugWIRE**
   ```
   1. In Microchip Studio, go to Tools > Device Programming
   2. Select Tool: Atmel-ICE, Device: ATmega64M1, Interface: ISP
   3. Click "Read" to read device signature
   4. Go to "Fuses" tab
   5. Set DWEN fuse (enable debugWIRE)
   6. Click "Program"
   7. Switch interface to debugWIRE in project properties
   ```

### Debugging Features

```c
// Debug capabilities
Available Debug Features:
├── Breakpoints
│   ├── Code breakpoints (unlimited software)
│   ├── Data breakpoints (limited hardware)
│   ├── Conditional breakpoints
│   └── Temporary breakpoints
├── Execution Control
│   ├── Step Into (F11)
│   ├── Step Over (F10)
│   ├── Step Out (Shift+F11)
│   ├── Run to Cursor (Ctrl+F10)
│   └── Continue (F5)
├── Variable Inspection
│   ├── Local variables window
│   ├── Watch window
│   ├── Memory window
│   └── Register window
├── Advanced Features
│   ├── Call stack inspection
│   ├── Memory access tracing
│   ├── Peripheral register viewing
│   └── Real-time variable updates
└── Limitations
    ├── debugWIRE affects timer accuracy
    ├── Some interrupts may be affected
    ├── RESET pin unavailable during debug
    └── Speed limited compared to free-running
```

## Testing and Validation

### Unit Testing Framework

```c
// Simple unit testing macros
#ifdef DEBUG
#define TEST_ASSERT(condition) \
    do { \
        if (!(condition)) { \
            debugPrint("ASSERT FAILED: %s:%d - %s\n", __FILE__, __LINE__, #condition); \
            while(1); /* Halt for debugging */ \
        } \
    } while(0)

#define TEST_ASSERT_EQUAL(expected, actual) \
    do { \
        if ((expected) != (actual)) { \
            debugPrint("ASSERT FAILED: %s:%d - Expected %d, got %d\n", \
                      __FILE__, __LINE__, (expected), (actual)); \
            while(1); \
        } \
    } while(0)

// Test execution macro
#define RUN_TEST(test_func) \
    do { \
        debugPrint("Running test: %s\n", #test_func); \
        test_func(); \
        debugPrint("Test passed: %s\n", #test_func); \
    } while(0)
#else
#define TEST_ASSERT(condition)
#define TEST_ASSERT_EQUAL(expected, actual)
#define RUN_TEST(test_func)
#endif

// Example test functions
void test_ADC_Conversion(void) {
    // Test ADC conversion accuracy
    uint16_t testValue = 512; // Mid-scale
    uint16_t converted = convertADCToMillivolts(testValue);
    TEST_ASSERT(converted > 2000 && converted < 3000); // ~2.5V expected
}

void test_CAN_MessageValidation(void) {
    // Test CAN message validation
    ModuleStatusMessage msg;
    msg.cellCount = 94;
    msg.moduleState = EMODSTATE_ON;
    TEST_ASSERT(validateStatusMessage(&msg) == true);
    
    msg.cellCount = 200; // Invalid
    TEST_ASSERT(validateStatusMessage(&msg) == false);
}

// Test suite execution
void runAllTests(void) {
    #ifdef DEBUG
    debugPrint("Starting test suite...\n");
    RUN_TEST(test_ADC_Conversion);
    RUN_TEST(test_CAN_MessageValidation);
    // Add more tests...
    debugPrint("All tests completed successfully!\n");
    #endif
}
```

### Integration Testing

```c
// Integration test scenarios
Integration Test Categories:
├── Communication Tests
│   ├── CAN bus communication with pack controller
│   ├── Cell CPU communication via vUART
│   ├── SD card read/write operations
│   └── EEPROM configuration storage
├── Monitoring Tests
│   ├── Cell voltage measurement accuracy
│   ├── Temperature reading validation
│   ├── Current measurement precision
│   └── Balancing control functionality
├── Safety Tests
│   ├── Overvoltage protection response
│   ├── Undervoltage protection response
│   ├── Overtemperature protection
│   └── Communication timeout handling
├── Performance Tests
│   ├── Real-time constraint validation
│   ├── Memory usage analysis
│   ├── Power consumption measurement
│   └── Deterministic timing verification
└── Stress Tests
    ├── Extended operation testing
    ├── Error recovery scenarios
    ├── Thermal cycling
    └── EMI/EMC compliance
```

## Code Quality Tools

### Static Analysis

```bash
# Code analysis tools and commands

# PC-lint Plus (if available)
pclint-plus.exe +v -width(120,4) -i"C:\XC8\include" *.c *.h

# Cppcheck (free alternative)
cppcheck --enable=all --platform=avr8 --std=c99 *.c

# Custom analysis scripts
python code_metrics.py --complexity --coverage --style
```

### Code Formatting

```c
// Coding standards
Code Style Guidelines:
├── Indentation: 4 spaces (no tabs)
├── Line Length: 120 characters maximum
├── Naming Convention:
│   ├── Variables: camelCase (localVariable)
│   ├── Functions: camelCase (functionName)
│   ├── Constants: UPPER_CASE (MAX_CELLS)
│   ├── Types: PascalCase (CellData)
│   └── Globals: g_ prefix (g_cellData)
├── Comments:
│   ├── Function headers with purpose, parameters, returns
│   ├── Complex algorithms explained
│   ├── TODO/FIXME markers for future work
│   └── Doxygen-style documentation
└── File Organization:
    ├── License header
    ├── Include statements
    ├── Constant definitions
    ├── Type definitions
    ├── Global variables
    ├── Function prototypes
    └── Function implementations
```

### Documentation Standards

```c
/**
 * @brief Converts ADC reading to millivolts
 * 
 * This function converts a raw 10-bit ADC reading to millivolts using
 * the configured voltage reference and calibration factors.
 * 
 * @param adcReading Raw ADC value (0-1023)
 * @return Voltage in millivolts (0-5000mV)
 * 
 * @note Uses fixed-point arithmetic for efficiency
 * @see VOLTAGE_CONVERSION_FACTOR for calibration details
 */
uint16_t convertADCToMillivolts(uint16_t adcReading);
```

This development environment setup provides a complete foundation for ModuleCPU firmware development with proper tooling, debugging capabilities, and quality assurance measures.

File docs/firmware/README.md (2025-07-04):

# ModuleCPU Firmware Architecture

## Table of Contents

1. [Overview](#overview)
2. [System Architecture](#system-architecture)
3. [Core Modules](#core-modules)
4. [Control Flow](#control-flow)
5. [Communication Architecture](#communication-architecture)
6. [Data Structures](#data-structures)
7. [State Management](#state-management)
8. [Task Scheduling](#task-scheduling)

## Overview

The ModuleCPU firmware implements a comprehensive battery module controller that manages up to 94 individual cells within a single battery module. It operates on an ATmega64M1 microcontroller and provides real-time monitoring, balancing, and communication capabilities.

### Key Characteristics
- **Deterministic Operation**: Fixed 300ms control cycle with predictable execution
- **Dual-Phase Architecture**: Alternating read and write phases for data integrity
- **Event-Driven Design**: Timer-based interrupts drive all major operations
- **Safety-First Approach**: Multiple layers of protection and fault detection
- **Low Power Design**: Optimized for minimal standby current consumption

### Firmware Specifications
```
Build Information:
├── Firmware Build Number: 8278
├── Manufacture ID: 0x02
├── Part ID: 0x03
├── Hardware Compatibility: 0x0000
├── Target Platform: ATmega64M1
├── Compiler: Microchip XC8 v2.36
├── C Standard: C99
└── Optimization: -Os (size), -Og (debug)
```

## System Architecture

### Layered Design

```
┌─────────────────────────────────────────────────────────────────┐
│                     Application Layer                           │
│  ┌─────────────┬─────────────┬─────────────┬─────────────────┐  │
│  │   Main      │   Cell      │   Balance   │   Safety        │  │
│  │ Controller  │ Monitoring  │ Management  │   System        │  │
│  └─────────────┴─────────────┴─────────────┴─────────────────┘  │
└─────────────────────────┬───────────────────────────────────────┘
                          │ Application APIs
┌─────────────────────────┼───────────────────────────────────────┐
│                     Middleware Layer                            │
│  ┌─────────────┬─────────────┬─────────────┬─────────────────┐  │
│  │   Virtual   │   Storage   │    CAN      │     Debug       │  │
│  │    UART     │  Manager    │  Protocol   │   Services      │  │
│  └─────────────┴─────────────┴─────────────┴─────────────────┘  │
└─────────────────────────┬───────────────────────────────────────┘
                          │ Driver APIs
┌─────────────────────────┼───────────────────────────────────────┐
│                Hardware Abstraction Layer                       │
│  ┌─────────────┬─────────────┬─────────────┬─────────────────┐  │
│  │     ADC     │     CAN     │     SPI     │   I2C/Timer     │  │
│  │   Driver    │   Driver    │   Driver    │    Drivers      │  │
│  └─────────────┴─────────────┴─────────────┴─────────────────┘  │
└─────────────────────────┬───────────────────────────────────────┘
                          │ Register Access
┌─────────────────────────┼───────────────────────────────────────┐
│                     Hardware Layer                              │
│  ATmega64M1 + MCP7940N RTC + SD Card + External Components     │
└─────────────────────────────────────────────────────────────────┘
```

### File Organization

```
ModuleCPU/
├── main.c                      # Main control loop and initialization
├── main.h                      # System definitions and constants
├── adc.c/.h                    # ADC driver for cell monitoring
├── can.c/.h                    # CAN communication driver
├── can_ids.h                   # CAN message ID definitions
├── vUART.c/.h                  # Virtual UART implementation
├── debugSerial.c/.h            # Debug communication interface
├── STORE.c/.h                  # Data storage management
├── EEPROM.c/.h                 # EEPROM configuration storage
├── SD.c/.h                     # SD card interface
├── SPI.c/.h                    # SPI bus driver
├── I2c.c/.h                    # I2C bus driver
├── rtc_mcp7940n.c/.h          # Real-time clock driver
└── ../Shared/Shared.h          # Common definitions
```

## Core Modules

### 1. Main Controller (main.c)

**Central system orchestrator and periodic task manager**

#### System Configuration:
```c
// System timing configuration
#define CPU_SPEED                    8000000    // 8MHz internal oscillator
#define PERIODIC_INTERRUPT_RATE_MS   100       // 100ms base timing
#define PERIODIC_CALLBACK_RATE_MS    300       // 300ms control cycle
#define PACK_CONTROLLER_TIMEOUT_MS   11100     // 11.1s timeout

// Maximum cell capacity
#define TOTAL_CELL_COUNT_MAX         94        // Current modules support 94 cells

// Frame types for dual-phase operation
typedef enum {
    EFRAMETYPE_READ,                           // Data acquisition phase
    EFRAMETYPE_WRITE,                          // Data reporting/storage phase
} EFrameType;
```

#### State Management:
```c
// Module operating states
typedef enum {
    EMODSTATE_OFF = 0,                         // All systems off
    EMODSTATE_STANDBY,                         // Ready, monitoring only
    EMODSTATE_PRECHARGE,                       // Preparing for operation
    EMODSTATE_ON,                              // Full operation with balancing
    
    EMODSTATE_COUNT,
    EMODSTATE_INIT,                            // Initial assessment state
} EModuleControllerState;

// Current operating state
EModuleControllerState g_eCurrentState = EMODSTATE_OFF;
```

#### Main Control Loop:
```c
int main(void) {
    // Hardware initialization
    systemInit();
    peripheralInit();
    
    // Initialize all subsystems
    FrameInit(true);                           // Full system initialization
    
    // Enable global interrupts
    sei();
    
    // Main control loop
    while (1) {
        // Service watchdog timer
        WatchdogReset();
        
        // Process background tasks
        if (g_bServiceNeeded) {
            // Clear service flag
            g_bServiceNeeded = false;
            
            // Execute frame-specific operations
            processPeriodicTasks();
            
            // Handle communication timeouts
            checkTimeouts();
            
            // Update system status
            updateSystemStatus();
        }
        
        // Enter sleep mode to save power
        enterSleepMode();
    }
}
```

### 2. ADC Manager (adc.c)

**Cell voltage and temperature monitoring system**

#### ADC Configuration:
```c
// ADC reference and scaling
#define CELL_VREF                    1.1       // 1.1V internal reference
#define CELL_VOLTAGE_BITS            10        // 10-bit ADC resolution
#define FIXED_POINT_SCALE            512       // 9-bit fractional precision

// Voltage divider calibration
#define CELL_DIV_TOP                 90900     // Upper resistor (Ohms)
#define CELL_DIV_BOTTOM              30100     // Lower resistor (Ohms)
#define CELL_VOLTAGE_CAL             1.032     // Measured calibration factor

// Pre-calculated conversion factor
#define VOLTAGE_CONVERSION_FACTOR    ((uint32_t)((CELL_VREF * 1000.0 / \
    CELL_VOLTAGE_SCALE * CELL_VOLTAGE_CAL * FIXED_POINT_SCALE) + 0.5))
```

#### Cell Monitoring Process:
```c
void ADCCallback(EADCType eType, uint16_t u16Reading) {
    static uint8_t cellIndex = 0;
    
    switch (eType) {
        case EADC_CELL_VOLTAGE:
            // Convert raw ADC reading to millivolts
            uint32_t millivolts = (u16Reading * VOLTAGE_CONVERSION_FACTOR) / 
                                 (ADC_MAX_VALUE * FIXED_POINT_SCALE);
            
            // Store cell voltage
            g_cellData[cellIndex].voltage = (uint16_t)millivolts;
            
            // Update statistics
            updateVoltageStatistics(cellIndex, millivolts);
            
            // Move to next cell
            cellIndex = (cellIndex + 1) % g_u8ActiveCellCount;
            break;
            
        case EADC_CELL_TEMPERATURE:
            // Process temperature reading
            processTemperatureReading(cellIndex, u16Reading);
            break;
            
        case EADC_MODULE_CURRENT:
            // Process current measurement
            processCurrentReading(u16Reading);
            break;
    }
}
```

### 3. Virtual UART (vUART.c)

**Bit-banged UART for cell CPU communication**

#### Protocol Specifications:
```c
// Virtual UART timing (50μs per bit = 20kbps)
#define VUART_BIT_TICKS              50        // Timer ticks per bit

// Frame structure: [START][8 DATA BITS][STOP]
// Each cell response: 4 bytes (voltage + temperature + status + checksum)
```
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

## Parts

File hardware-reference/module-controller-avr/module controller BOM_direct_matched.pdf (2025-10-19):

## module controller BOM_direct_matched

# | Reference | Value | Footprint | MB P/N MFG | MFG P/N | Qty Modbatt P/N Modbatt Description

1 C1 | 2.2uF | Capacitor_SMD:C_0402_1005Metric_Pad0. MURATA ELECTRONICS | GRM155C81E225ME11D | 1 | 9042007 | 0402 2.2uF CAP 25V X6S
2 C2 | 10nF | Capacitor_SMD:C_0402_1005Metric_Pad0. KEMET | C0402C103J5RECAUTO | 1 | 9042093 | 0402 10NF 50V X7R 5%
3 C10,C14,C23,C24,C34 | 10pF | Capacitor_SMD:C_0402_1005Metric_Pad0. MURATA | GRM1555C1H100JA01D | 5 | 9042051 | CAP CER 10PF 50V C0G/NP0 0402
4 C11,C13,C20,C28 | 22uF 25V | Capacitor_SMD:C_0805_2012Metric | SAMSUNG ELECTRO-MECHA CL21A226MAYNNNE | 4 | 9042014 | 0805 22uF 25V X5R
5 C16,C18,C19 | 1uF | Capacitor_SMD:C_0402_1005Metric_Pad0. CALCHIP | GMC04X7R104J16NT | 3 | 9042062 | 0402 .1UF 5% 16V X7R
6 C17,C21,C22 | .1uF 50V | Capacitor_SMD:C_0402_1005Metric_Pad0. Murata Electronics | GRM155R61H104JE14D | 3 | 9042102 | 0402 0.1UF 50V X5R
7 | .1uF | CALCHIP | GMC04X7R104J16NT | 12 | 9042062 | 0402 .1UF 5% 16V X7R
8 C30,C31,C32 | .1uF 1KV | Capacitor_SMD:C_1812_4532Metric | KEMET | C1812W104KDRACAUTO | 3 | 9042146 | 1812 0.1uF 1kV X7R
9 C8,C9 | 7pF | Capacitor_SMD:C_0402_1005Metric_Pad0. SEIKO INSTRUMENTS | SC32S-7PF20PPM | 2 | 9042006 | SC32S-7PF20PPM CRYSTAL 32.7680KHZ 7PF SMD
10 D2 | 20V 350mA SOD123 | Diode_SMD:D_SOD-123 | MICRO COMMERCIAL | SD103AW-TP | 1 | 9042020 | DIODE SCHOTTKY 40V 350MA SOD123
11 D7 | BAT54CW | Package_TO_SOT_SMD:SOT-323_SC-70 DIOTEC SEMICONDUCTOR BAT54CW | 1 | 9042156 | Schottky SOT-323
12 D1,D3,D6 | MMBZ27VCLT1G | modbatt footprints:SOT-23 | ESD Suppressors/ TVS Diodes MMBZ27VCLT1G | 3 | 9042158 | 27V 225mW Dual Commo
13 J3 | Debug | Connector_PinHeader_2.54mm:PinHeader_2x03_P2.54mm_Horizontal | X002ZWOD9L | 1 | 9042177 | spring loaded pins for debug 0.7mm
14 J4 | Micro_SD_Card_Det_Hirose_ modbatt footprints:microSD_HC_Hirose_DM3AT-SF-PEJM5 | 1
15 J5 | 640389-4 | modbatt footprints:6403896-4 | TE CONNECTIVITY | 640389-4 | 1 | 9042075 | FRCTN LK HDR RA 4P S
16 J1,J2 | TERM | modbatt footprints:TERMINAL | 2
17 J6,J7,J8,J9,J10,J11 | Conn_01x01_Pin | modbatt footprints:PinHeader_1x01_P1.00mm_Horizontal | 6
18 K1 | DVR05 | modbatt footprints:modbatt relay tab | 1
19 L1 | 4.7uH | Inductor_SMD:L_0805_2012Metric_Pad1.1 MURATA ELECTRONICS | LQM21PN4R7MGHL | 1 | 9042016 | 9FIXED IND 4.7UH 1.2A 275MOHM SMD
20 Q4 | ZVP0545G | Package_TO_SOT_SMD:SOT-223 | DIODES INC | ZVP0545GTA | 1 | 9042073 | P-CHNL 450V
21 Q5 | ZVN0545G | Package_TO_SOT_SMD:SOT-223 | DIODES INC | ZVN0545GTA | 1 | 9042074 | N-CHNL 450V
22 Q1,Q6 | 2N7002 | Package_TO_SOT_SMD:SOT-323_SC-70 PANJIT INTERNATIONAL | 2N7002KW-AU_R1_000A1 | 2 | 9042001 | SOT-323, MOSFET
23 Q2,Q3 | MOSFET 600V | modbatt footprints:TO-263-3_TabPin2 | INFINEON | IPB60R040CFD7ATMA1 | 2 | 9042072 | MOSFET, N-CH, 600V, 50A, 150DEG C, 227W
24 R1 | 1KΩ | Resistor_SMD:R_0402_1005Metri 9E+06 YAGEO | RT0402FRE101KL | 1 | 9042161 | 0402 1K OHM 1% 50PPM
25 R2 | 4.7Ω | Resistor_SMD:R_0402_1005Metri 9E+06 TE CONNECTIVITY | CRGCQ0402J4R7 | 1 | 9042031 | 0402 4.7OHM 1/16W 5%
26 R6 | 10KΩ | Resistor_SMD:R_0402_1005Metri 9E+06 YAGEO | RC0402JR-0710KL | 1 | 9042011 | 0402 10K OHM 1/16W 5%
27 R11 | 200KΩ | Resistor_SMD:R_0402_1005Metri 9E+06 YAGEO | RC0402JR-13200KL | 1 | 9042113 | 0402 200K OHM 1/16W 5%
28 R15 | 200KΩ | Resistor_SMD:R_1206_3216Metri 9E+06 YAGEO | RC1206JR-07200KL | 1 | 9042111 | 1206 200 kOhms 250mW 5%
29 R17 | 100KΩ 0.1% | Resistor_SMD:R_0402_1005Metri 9E+06 YAGEO | RT0402BRE07100KL | 1 | 9042090 | 0402 100K OHM 0.1% 1/16W
30 R32 | 33KΩ | modbatt footprints:3560 | 9E+06 TE CONNECTIVITY | 356033KFT | 1 | 9042127 | RES 3560 33K 6W 1%
31 R35 | 22Ω | Resistor_SMD:R_0402_1005Metri 9E+06 PANASONIC | ERJ-U02J220X | 1 | 9042149 | 0402 22 OHM 5%
32 R12,R13 | 787KΩ 1% | Resistor_SMD:R_0402_1005Metri 9E+06 VISHAY | CRCW0402787KFKED | 2 | 9042160 | 0402 787K OHM 1/16W 1%
33 R14,R28,R29,R30,R31 | 4.99KΩ 0.1% | Resistor_SMD:R_0402_1005Metri 9E+06 YAGEO | RT0402BRE074K99L | 5 | 9042081 | 0402 4.99KOHM 0.1% 1/16W
34 R16,R18,R19,R20,R21 | 2.7MΩ 0.1% | Resistor_SMD:R_1206_3216Metri 9E+06 SUSUMU | RG3216P-2704-B-T1 | 5 | 9042061 | RES 1206 2.7M OHM 0.1% 1/4W
35 R3,R4,R24,R25,R33 | 4.7KΩ | Resistor_SMD:R_0402_1005Metri 9E+06 YAGEO | AC0402FR-134K7L | 5 | 9042110 | 0402 4.7K OHM 62.5mW 1% AEC-Q200
36 R36,R37 | 6.04Ω | Resistor_SMD:R_2512_6332Metric 9E+06 VISHAY | CRCW25126R04FKEGHP | 2 | 9042155 | 2512 6.04 OHM 1.5W 1%
37 R5,R22,R23,R34 | 100KΩ | Resistor_SMD:R_0402_1005Metri 9E+06 TE CONNECTIVITY | CRG0402J100K/10 | 4 | 9042003 | 0402 100K OHM 1/16W 5%
38 R7,R8 | 1.0MΩ 0.1% | Resistor_SMD:R_0402_1005Metri 9E+06 YAGEO | RE0402BRE071ML | 2 | 9042012 | 0402 1M OHM 1/16W 0.1%
39 R9,R10 | 68Ω | Resistor_SMD:R_0402_1005Metri 9E+06 Walsin Technology Corporation WR04X68R0FTL | 2 | 9042095 | 0402 68 OHM 1% 1/16W

C3,C4,C5,C6,C7,C12,C15,
C25,C26,C27,C29,C33

Capacitor_SMD:C_0402_1005Met ric_Pad0.74x0.62mm_HandSolder

## module controller BOM_direct_matched

40 U1 | ACS37002LMABTR-050B5 | Package_SO:SOIC-16W_7.5x10. 9E+06 Allegro MicroSystems | ACS37002LMABTR-050B5 | 1 | 9042071 | Board Mount Current Sensors 400KHZ
41 U2 | ATmega64M1-AU | modbatt footprints:TQFP-32_7x7 | 9E+06 Microchip Technology | ATMEGA64M1-AU | 1 | 9042027 | 8-bit Microcontrollers - MCU 16 MHz, 85DEG
42 U3 | MCP7940N | Package_SO:SOIC-8_3.9x4.9mm_ 9E+06 MICROCHIP TECH | MCP7940NT-I/SN | 1 | 9042023 | IC RTC CLK/CALENDAR I2C 8S0IC
43 U4 | AP63203WU | Package_TO_SOT_SMD:TSOT-23-042036*DIODES INC | AP63203WU-7 | 1 | 9042036 | IC REG BUCK 3.3V 2A TSOT26
44 U5 | TLV333 8SOIC | Package_SO:SOIC-8_3.9x4.9mm_ 9E+06 TEXAS INSTRUMENTS | TLV333IDR | 1 | 9042089 | Op Amps Single 350-kHz low -noise RRIO CMOS
45 U6 | TLP152 | modbatt footprints:SO-6_4.4x3.6 | 9E+06 TOSHIBA | TLP152(TPL,E | 1 | 9042076 | Optically Isolated Gate Drivers Gate Drive Phcplr 3750 Vrms
46 U7 | TPSI3050D | Package_SO:SOIC-8_7.5x5.85mm 9E+06 TI | TPSI3050DWZR | 1 | 9042157 | Galvanically Isolated Gate Drivers Isolated switch driver
47 U8 | ISO1050DUB | modbatt footprints:DIP-8_W8.89 | 9E+06 TEXAS INSTRUMENTS | ISO1050DUBR | 1 | 9042022 | IC TXRX/ISO HALF 1/1 8S0P
48 U9 | DC-DC SIP6 | modbatt footprints:SIP6_IB_LS-1 | 9E+06 MORNSUN | IB 1205LS-1WR3 | 1 | 9042056 | Isolated Module DC DC Converter 1 Output 5V 200mA 11.4V -
49 U10 | AZ1117-5.0 | Package_TO_SOT_SMD:SOT-223042057*Diodes Incorporated | AZ1117IH-5.0TRG1 | 1 | 9042098 | IC REG LINEAR 5V 1A SOT223 (use 9042057)
50 U11 | MIC5504-3.3YM5 | Package_TO_SOT_SMD:SOT-23-5 9E+06 Microchip Technology | MIC5504-3.3YM5-TR | 1 | 9042100 | IC REG LINEAR 3.3V 300MA SOT23-5
51 U12 | TMP392 | modbatt footprints:SOT-563 | 9E+06 TI THERMOSTATS | TMP392A2DRLR | 1 | 9042133 | Board Mount Temperature Sensors TMP392 Dual-channel
52 U13 | TC7WH74FU | Package_SO:TSSOP-8_3x3mm_P 9E+06 TOSHIBA | TC7WH74FU,LJ(CT | 1 | 9042143 | Flip Flops L-MOS LOGIC (VHS)
53 Y1 | 32.768KHz SC-32 | Crystal:Crystal_SMD_3215-2Pin_3 9E+06 SEIKO INSTRUMENTS | SC32S-7PF20PPM | 1 | 9042006 | SC32S-7PF20PPM CRYSTAL 32.7680KHZ 7PF SMD

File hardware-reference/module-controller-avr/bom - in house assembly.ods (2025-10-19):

REV E – IN HOUSE ASSEMMBLY
Designator | Part # | Quantity | Designation
D1,D6,D3 | 9042158 | 3 | MMBZ27VCLT1G
C23,C24,C10,C14,C34 | 9042085 | 5 | 10pF
J9,J8,J6,J7,J11,J10 | 9042080 | 6 | Conn_01x01_Pin
C28,C13,C11,C20 | 9042014 | 4 | 22uF 25V
R30,R28,R29,R31,R14 | 9042081 | 5 | 4.99K 0.1%
R36,R37 |  | 2 | 4R0 500V
Q2,Q3 | 9042072 | 2 | IPB60R040CFD7ATMA1
R16,R19,R20 | 2042061 | 3 | 2.7M 0.1%
U1 | 9042071 | 1 | ACS37002LMABTR-050B5
C30,C31,C32 | 9042146 | 3 | .1uF 1KV
R21,R18 | 2042061 | 2 | 2.7M
Q5 | 9042074 | 1 | ZVN0545G
C1 | 9042083 | 1 | 2.2uF
Q4 | 9042159 | 1 | ZVP0545G
R1 | 9042161 | 1 | 1K
Q1,Q6 | 9042001 | 2 | 2N7002
R15 | 9042111 | 1 | 200K
R4,R33,R24,R25,R3 | 9042110 | 5 | 4.7K
R5,R22,R23,R34 | 9042003 | 4 | 100K
R32 | 9042127 | 1 | 33K 3560 6W
L1 | 9042086 | 1 | 4.7uH
C6,C5,C4,C29,C25,C12,C15,C7,C3,C26,C33 | 9042087 | 11 | .1uF
C8,C9 | 9042088 | 2 | 7pF
Y1 | 9042006 | 1 | 32.768KHz SC-32
R17 | 9042090 | 1 | 100K 0.1%
C22,C21,C17 | 9042102 | 3 | .1uF 50V
R6 | 9042082 | 1 | 10K
J5 | 9042075 | 1 | 640389-4
R8,R7 | 9042012 | 2 | 1.0M 0.1%
U3 | 9042023 | 1 | MCP7940N-xMS
U8 | 9042022 | 1 | ISO1050DUB
C16,C19,C18 | 9042101 | 3 | 1uF
U9 | 9042056 | 1 | IB1205LS-1WR3
U7 | 9042157 | 1 | TPSI3050D
C2 | 9042093 | 1 | 10nF
R12,R13 | 9042160 | 2 | 787K 1%
R35 | 9042149 | 1 | 22
U13 | 9042143 | 1 | TC7WH74FU
D7 | 9042156 | 1 | BAT54CW
J4 | 9042040 | 1 | Micro_SD_Card_Det_Hirose_DM3AT
R10,R9 | 9042095 | 2 | 68
U5 | 9042089 | 1 | TLV333
R11 | 9042113 | 1 | 200K
J3 | 9042015 | 1 | Debug
U6 | 9042076 | 1 | TLP152
U4 | 9042097 | 1 | AP63203WU
U12 | 9042133 | 1 | TMP392
U10 | 9042098 | 1 | AZ1117-5.0
D2 | 2042020 | 1 | 20V 350mA
R2 | 9042031 | 1 | 4.7 OHM
U11 | 9042100 | 1 | MIC5504-3.3YM5
U2 | 9042027 | 1 | ATmega64M1-AU

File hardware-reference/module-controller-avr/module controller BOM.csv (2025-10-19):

# | Reference | Qty | Manufacturer_Name | Manufacturer_Part_Number | Description | Value | Footprint | MB P/N | Exclude from BOM
1 | C1 | 1 |  |  |  | 2.2uF | Capacitor_SMD:C_0402_1005Metric_Pad0.74x0.62mm_HandSolder
2 | C2 | 1 |  |  |  | 10nF | Capacitor_SMD:C_0402_1005Metric_Pad0.74x0.62mm_HandSolder
3 | C10,C14,C23,C24,C34 | 5 |  |  |  | 10pF | Capacitor_SMD:C_0402_1005Metric_Pad0.74x0.62mm_HandSolder
4 | C11,C13,C20,C28 | 4 |  |  |  | 22uF 25V | Capacitor_SMD:C_0805_2012Metric
5 | C16,C18,C19 | 3 |  |  |  | 1uF | Capacitor_SMD:C_0402_1005Metric_Pad0.74x0.62mm_HandSolder
6 | C17,C21,C22 | 3 |  |  |  | .1uF 50V | Capacitor_SMD:C_0402_1005Metric_Pad0.74x0.62mm_HandSolder
7 | C3,C4,C5,C6,C7,C12,C15,C25,C26,C27,C29,C33 | 12 |  |  |  | .1uF | Capacitor_SMD:C_0402_1005Metric_Pad0.74x0.62mm_HandSolder
8 | C30,C31,C32 | 3 |  |  |  | .1uF 1KV | Capacitor_SMD:C_1812_4532Metric
9 | C8,C9 | 2 |  |  |  | 7pF | Capacitor_SMD:C_0402_1005Metric_Pad0.74x0.62mm_HandSolder
10 | D2 | 1 |  |  |  | 20V 350mA SOD123 | Diode_SMD:D_SOD-123
11 | D7 | 1 |  |  | Dual schottky barrier diode, common cathode, SOT-323 | BAT54CW | Package_TO_SOT_SMD:SOT-323_SC-70
12 | D1,D3,D6 | 3 |  |  |  | MMBZ27VCLT1G | modbatt footprints:SOT-23
13 | J3 | 1 |  |  |  | Debug | Connector_PinHeader_2.54mm:PinHeader_2x03_P2.54mm_Horizontal
14 | J4 | 1 |  |  |  | Micro_SD_Card_Det_Hirose_DM3AT | modbatt footprints:microSD_HC_Hirose_DM3AT-SF-PEJM5
15 | J5 | 1 | TE Connectivity | 640389-6 |  | 640389-4 | modbatt footprints:6403896-4
16 | J1,J2 | 2 |  |  |  | TERM | modbatt footprints:TERMINAL
17 | J6,J7,J8,J9,J10,J11 | 6 |  |  |  | Conn_01x01_Pin | modbatt footprints:PinHeader_1x01_P1.00mm_Horizontal
18 | K1 | 1 |  |  |  | DVR05 | modbatt footprints:modbatt relay tab
19 | L1 | 1 |  |  |  | 4.7uH | Inductor_SMD:L_0805_2012Metric_Pad1.15x1.40mm_HandSolder
20 | Q4 | 1 |  |  |  | ZVP0545G | Package_TO_SOT_SMD:SOT-223
21 | Q5 | 1 |  |  |  | ZVN0545G | Package_TO_SOT_SMD:SOT-223
22 | Q1,Q6 | 2 |  |  |  | 2N7002 | Package_TO_SOT_SMD:SOT-323_SC-70
23 | Q2,Q3 | 2 | INFINEON | IPB60R040CFD7ATMA1 | MOSFET, N-CH, 600V, 50A, 150DEG C, 227W | MOSFET 600V | modbatt footprints:TO-263-3_TabPin2
24 | R1 | 1 | YAGEO | RT0402FRE101KL | RES 0402 1K OHM 1/16W 1% | 1KΩ | Resistor_SMD:R_0402_1005Metric_Pad0.72x0.64mm_HandSolder | 9042161
25 | R2 | 1 | TE Connectivity | CRGCQ0402J4R7 | RES 0402 4.7OHM 1/16W 5% | 4.7Ω | Resistor_SMD:R_0402_1005Metric_Pad0.72x0.64mm_HandSolder | 9042031
26 | R6 | 1 | YAGEO | RC0402JR-0710KL | RES 0402 10K OHM 1/16W 5% | 10KΩ | Resistor_SMD:R_0402_1005Metric_Pad0.72x0.64mm_HandSolder | 9042011
27 | R11 | 1 | YAGEO | RC0402JR-13200KL | RES 0402 200K OHM 1/16W 5% | 200KΩ | Resistor_SMD:R_0402_1005Metric_Pad0.72x0.64mm_HandSolder | 9042113
28 | R15 | 1 | YAGEO | RC1206JR-07200KL | RES 1206 200k Ohms 1/4W 5% | 200KΩ | Resistor_SMD:R_1206_3216Metric_Pad1.30x1.75mm_HandSolder | 9042111
29 | R17 | 1 | YAGEO | RT0402BRE07100KL | RES 100K Ohm 0.1% 1/16W 50V 50ppm | 100KΩ 0.1% | Resistor_SMD:R_0402_1005Metric_Pad0.72x0.64mm_HandSolder | 9042090
30 | R32 | 1 | TE Connectivity | 356033KFT | RES 3560 33K 6W 1% | 33KΩ | modbatt footprints:3560 | 9042127
31 | R35 | 1 | PANASONIC | ERJ-U02J220X | RES 0402 22 OHM 5% | 22Ω | Resistor_SMD:R_0402_1005Metric_Pad0.72x0.64mm_HandSolder | 9042149
32 | R12,R13 | 2 | Vishay | CRCW0402787KFKED | RES 0402 787KOHM 1% 1/16W | 787KΩ 1% | Resistor_SMD:R_0402_1005Metric_Pad0.72x0.64mm_HandSolder | 9042160
33 | R14,R28,R29,R30,R31 | 5 | YAGEO | RT0402BRE074K99L | RES 0402 4.99KOHM 0.1% 1/16W | 4.99KΩ 0.1% | Resistor_SMD:R_0402_1005Metric_Pad0.72x0.64mm_HandSolder | 9042081
34 | R16,R18,R19,R20,R21 | 5 | SUSUMU,Susumu | RG3216P-2704-B-T1 | RES 1206 2.7M OHM 0.1% 1/4W | 2.7MΩ 0.1% | Resistor_SMD:R_1206_3216Metric_Pad1.30x1.75mm_HandSolder | 9042061
35 | R3,R4,R24,R25,R33 | 5 | YAGEO | AC0402FR-134K7L | RES 0402 4.7K OHM 62.5mW 1% | 4.7KΩ | Resistor_SMD:R_0402_1005Metric_Pad0.72x0.64mm_HandSolder | 9042110
36 | R36,R37 | 2 | VISHAY | CRCW25126R04FKEGHP | RES 6.04 OHM 1.5W 1% 2512 | 6.04Ω | Resistor_SMD:R_2512_6332Metric | 9042155
37 | R5,R22,R23,R34 | 4 | TE Connectivity | CRG0402J100K/10 | RES 0402 100K OHM 1/16W 5% | 100KΩ | Resistor_SMD:R_0402_1005Metric_Pad0.72x0.64mm_HandSolder | 9042003
38 | R7,R8 | 2 | YAGEO | RE0402BRE071ML | RES 0402 1M OHM 1/16W 0.1% | 1.0MΩ 0.1% | Resistor_SMD:R_0402_1005Metric_Pad0.72x0.64mm_HandSolder | 9042012
39 | R9,R10 | 2 | Walsin | WR04X68R0FTL | RES 0402 68 OHM 1% 1/16W | 68Ω | Resistor_SMD:R_0402_1005Metric_Pad0.72x0.64mm_HandSolder | 9042095
40 | U1 | 1 | Allegro MicroSystems | ACS37002LMABTR-050B5 | Board Mount Current Sensors 400KHZ | ACS37002LMABTR-050B5 | Package_SO:SOIC-16W_7.5x10.3mm_P1.27mm | 9042071
41 | U2 | 1 | Microchip Technology | ATmega64M1-AU | 8-bit Microcontrollers - MCU 16 MHz, 85DEG | ATmega64M1-AU | modbatt footprints:TQFP-32_7x7mm_P0.8mm | 9042027
42 | U3 | 1 | Microchip Technology | MCP7940NT-I/SN | Real Time Clock I2C GP RTCC 64B SRAM | MCP7940N | Package_SO:SOIC-8_3.9x4.9mm_P1.27mm | 9042023
43 | U4 | 1 | Diodes Incorporated | AP63203WU-7 | IC REG BUCK 3.3V 2A TSOT26 | AP63203WU | Package_TO_SOT_SMD:TSOT-23-6 | 9042036*
44 | U5 | 1 | Texas Instruments | TLV333IDR | Op Amps Single 350-kHz low -noise RRIO CMOS | TLV333 8SOIC | Package_SO:SOIC-8_3.9x4.9mm_P1.27mm | 9042089
45 | U6 | 1 | TOSHIBA | TLP152(TPL,E | Optically Isolated Gate Drivers Gate Drive Phcplr 3750 Vrms | TLP152 | modbatt footprints:SO-6_4.4x3.6mm_P1.27mm | 9042076
46 | U7 | 1 | Texas Instruments | TPSI3050DWZR | Galvanically Isolated Gate Drivers Isolated switch driver | TPSI3050D | Package_SO:SOIC-8_7.5x5.85mm_P1.27mm | 9042157
47 | U8 | 1 | Texas Instruments | ISO1050DUB | Digital Isolators Iso 5V CAN Xcvr | ISO1050DUB | modbatt footprints:DIP-8_W8.89mm_SMDSocket_LongPads | 9042022
48 | U9 | 1 | MORNSUN | IB 1205LS-1WR3 | Isolated Module DC DC Converter 1 Output 5V 200mA 11.4V - 12.6V Input | DC-DC SIP6 | modbatt footprints:SIP6_IB_LS-1WR3_MNS | 9042056
49 | U10 | 1 | Diodes Incorporated | AZ1117IH-5.0TRG1 | Voltage Regulators LDO BJT HiCurr 1.35A 10Hz to 10KHz | AZ1117-5.0 | Package_TO_SOT_SMD:SOT-223 | 9042057*
50 | U11 | 1 | Microchip Technology | MIC5504-3.3YM5 | LDO Voltage Regulators Single 300mA | MIC5504-3.3YM5 | Package_TO_SOT_SMD:SOT-23-5 | 9042100
51 | U12 | 1 | Texas Instruments | TMP392A2DRLR | Board Mount Temperature Sensors TMP392 Dual-channel | TMP392 | modbatt footprints:SOT-563 | 9042133
52 | U13 | 1 | TOSHIBA | TC7WH74FU | Flip Flops L-MOS LOGIC (VHS) | TC7WH74FU | Package_SO:TSSOP-8_3x3mm_P0.65mm | 9042143
53 | Y1 | 1 | Seiko Semiconductors | SC32S-7PF20PPM | Crystals 32.768kHz 7pF +/-20PPM | 32.768KHz SC-32 | Crystal:Crystal_SMD_3215-2Pin_3.2x1.5mm | 9042006

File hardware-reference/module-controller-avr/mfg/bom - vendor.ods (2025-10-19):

REV E – vendor bom
QTY | REF | Description | MFG | MFG #
3 | D1,D6,D3 | MMBZ27VCLT1G | ESD Suppressors/ TVS Diodes | MMBZ27VCLT1G
5 | C23,C24,C10,C14,C34 | 10pF | Murata Electronics | GRM1555C1H100JA01D
4 | C28,C13,C11,C20 | 22uF 25V | SAMSUNG ELECTRO-MECHANICS | CL21A226MAYNNNE
5 | R30,R28,R29,R31,R14 | 4.99K 0.1% | YAGEO | RT0402BRE074K99L
2 | R36,R37 | 4R0 500V
2 | Q2,Q3 | IPB60R040CFD7ATMA1 | INFINEON | IPB60R040CFD7ATMA1
3 | R16,R19,R20 | 2.7M 0.1% | SUSUMU | RG3216P-2704-B-T1
1 | U1 | ACS37002LMABTR-050B5 | ALLEGRO MICROSYSTEMS | ACS37002LMABTR-050B5
3 | C30,C31,C32 | .1uF 1KV | KEMET | C1812W104KDRACAUTO
2 | R21,R18 | 2.7M | SUSUMU | RG3216P-2704-B-T1
1 | Q5 | ZVN0545G | DIODES INC | ZVN0545GTA
1 | C1 | 2.2uF | Samsung Electro-Mechanics | CL05A225MQ5NNNC
1 | Q4 | ZVP0545G | DIODES Inc. MOSFET | ZVP0545GTA
1 | R1 | 1K | YAGEO | RT0402FRE101KL
2 | Q1,Q6 | 2N7002 | PANJIT INTERNATIONAL | 2N7002KW-AU_R1_000A1
1 | R15 | 200K | YAGEO | RC1206JR-07200KL
5 | R4,R33,R24,R25,R3 | 4.7K | YAGEO | AC0402FR-134K7L
4 | R5,R22,R23,R34 | 100K | TE CONNECTIVITY PASSIVE PRODUCT | CRG0402J100K/10
1 | R32 | 33K 3560 6W | TE CONNECTIVITY | 356033KFT
1 | L1 | 4.7uH | Bourns Inc. | CV201210-4R7K
12 | C6,C5,C4,C29,C27,C25,C12,C15,C7,C3,C26,C33 | .1uF | Murata Electronics | GRM155R71A104JA01D
2 | C8,C9 | 7pF | YAGEO | CC0402CRNPO9BN7R0
1 | Y1 | 32.768KHz SC-32 | SEIKO INSTRUMENTS | SC32S-7PF20PPM
1 | R17 | 100K 0.1% | YAGEO | RT0402BRE07100KL
3 | C22,C21,C17 | .1uF 50V | Murata Electronics | GRM155R61H104JE14D
1 | R6 | 10K | Bourns Inc. | CR0402-FX-1300GLF
1 | J5 | 640389-4 | TE CONNECTIVITY | 640389-4
2 | R8,R7 | 1.0M 0.1% | YAGEO | RE0402BRE071ML
1 | U3 | MCP7940N-xMS | MICROCHIP TECH | MCP7940NT-I/SN
1 | U8 | ISO1050DUB | TEXAS INSTRUMENTS | ISO1050DUBR
3 | C16,C19,C18 | 1uF | Taiyo Yuden | UMK105CBJ105KV-F
1 | U9 | IB1205LS-1WR3 | MORNSUN | IB 1205LS-1WR3
1 | U7 | TPSI3050D | TI | TPSI3050DWZR
1 | C2 | 10nF | KEMET | C0402C103J5RECAUTO
2 | R12,R13 | 787K 1% | VISHAY | CRCW0402787KFKED
1 | R35 | 22 | PANASONIC | ERJ-U02J220X
1 | U13 | TC7WH74FU | TOSHIBA | TC7WH74FU,LJ(CT
1 | D7 | BAT54CW | DIOTEC SEMICONDUCTOR | BAT54CW
1 | J4 | Micro_SD_Card_Det_Hirose_DM3AT | HIROSE ELECTRIC | DM3AT-SF-PEJM5
2 | R10,R9 | 68 | Walsin Technology Corporation | WR04X68R0FTL
1 | U5 | TLV333 | TEXAS INSTRUMENTS | TLV333IDR
1 | R11 | 200K | YAGEO | RC0402JR-13200KL
1 | U6 | TLP152 | TOSHIBA | TLP152(TPL,E
1 | U4 | AP63203WU | Diodes Incorporated | AP63203WU-7
1 | U12 | TMP392 | TI THERMOSTATS | TMP392A2DRLR
1 | U10 | AZ1117-5.0 | Diodes Incorporated | AZ1117IH-5.0TRG1
1 | D2 | 20V 350mA | MICRO COMMERCIAL | SD103AW-TP
1 | R2 | 4.7 OHM | TE CONNECTIVITY | CRGCQ0402J4R7
1 | U11 | MIC5504-3.3YM5 | Microchip Technology | MIC5504-3.3YM5-TR
1 | U2 | ATmega64M1-AU | MICROCHIP 8-BIT CONTROLLERS | ATMEGA64M1-AU

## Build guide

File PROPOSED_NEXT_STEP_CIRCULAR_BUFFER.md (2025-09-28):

# Proposed: Initialize nstrings and Implement Circular Buffer

## Current State
- Cell data accessed directly from sg_sFrame.c buffer (896 bytes)
- Helper functions GetStringData() provide access to buffer
- Single string reading at start of buffer (legacy behavior preserved)
- System working and reporting to pack controller

## Proposed Changes

### 1. Initialize nstrings Based on Cell Count
**Location**: main.c, ProcessCellExpectedCount() function (around line 542)

```c
// After setting sg_u8CellCountExpected, calculate nstrings
void ProcessCellExpectedCount(uint8_t u8CellCountExpected)
{
    sg_sFrame.m.sg_u8CellCountExpected = u8CellCountExpected;

    // Calculate how many complete string readings fit in buffer
    // Each cell = 4 bytes (2 bytes voltage + 2 bytes temperature)
    uint16_t bytes_per_string = u8CellCountExpected * sizeof(CellData);

    if (bytes_per_string > 0) {
        sg_sFrame.m.nstrings = FRAME_CELLBUFFER_SIZE / bytes_per_string;

        // Ensure at least 1 string
        if (sg_sFrame.m.nstrings == 0) {
            sg_sFrame.m.nstrings = 1;
        }
    } else {
        sg_sFrame.m.nstrings = 1;
    }

    // Initialize circular buffer indices
    sg_sFrame.m.currentIndex = 0;
    sg_sFrame.m.readingCount = 0;

    // Rest of existing voltage calculations...
}
```

### 2. Update Helper Functions for Multiple Readings
**Location**: STORE.h, replace current helper functions

```c
// Get pointer to a specific string reading slot (0 to nstrings-1)
static inline CellData* GetStringDataAtIndex(FrameData* frame, uint16_t index) {
    uint16_t bytes_per_string = frame->m.sg_u8CellCountExpected * sizeof(CellData);
    uint16_t offset = index * bytes_per_string;
    return (CellData*)(&frame->c[offset]);
}

static inline volatile CellData* GetStringDataAtIndexVolatile(volatile FrameData* frame, uint16_t index) {
    uint16_t bytes_per_string = frame->m.sg_u8CellCountExpected * sizeof(CellData);
    uint16_t offset = index * bytes_per_string;
    return (volatile CellData*)(&frame->c[offset]);
}

// Get pointer to current writing slot
static inline CellData* GetStringData(FrameData* frame) {
    return GetStringDataAtIndex(frame, frame->m.currentIndex);
}

static inline volatile CellData* GetStringDataVolatile(volatile FrameData* frame) {
    return GetStringDataAtIndexVolatile(frame, frame->m.currentIndex);
}

// Get pointer to most recent complete reading (for CAN responses)
static inline volatile CellData* GetLatestCompleteString(volatile FrameData* frame) {
    // If we have at least one complete reading, return the previous slot
    if (frame->m.readingCount > 0) {
        uint16_t lastIndex = (frame->m.currentIndex == 0) ?
                             (frame->m.nstrings - 1) :
                             (frame->m.currentIndex - 1);
        return GetStringDataAtIndexVolatile(frame, lastIndex);
    }
    // Otherwise return current slot (may be incomplete)
    return GetStringDataVolatile(frame);
}
```

### 3. Advance Buffer After Complete String
**Location**: main.c, at end of WRITE frame processing (around line 2635)

```c
// After processing all cells in WRITE frame
if (sg_sFrame.m.sg_u8CellCPUCount == sg_sFrame.m.sg_u8CellCountExpected) {
    // We have a complete string reading, advance to next slot
    sg_sFrame.m.currentIndex = (sg_sFrame.m.currentIndex + 1) % sg_sFrame.m.nstrings;

    if (sg_sFrame.m.readingCount < sg_sFrame.m.nstrings) {
        sg_sFrame.m.readingCount++;
    }

    // Increment frame number for this complete reading
    sg_sFrame.m.frameNumber++;
}
```

### 4. Update CAN Response to Use Latest Complete Reading
**Location**: main.c, MODULE_DETAIL message handler (around line 1912)

```c
// Change from GetStringDataVolatile(&sg_sFrame) to:
volatile CellData* stringData = GetLatestCompleteString(&sg_sFrame);
```

## Examples with Different Cell Counts

### 20 Cells
- Bytes per string: 20 * 4 = 80 bytes
- Number of strings: 896 / 80 = 11 complete readings
- Granularity: ~5.5 seconds of history at 2Hz

### 50 Cells
- Bytes per string: 50 * 4 = 200 bytes
- Number of strings: 896 / 200 = 4 complete readings
- Granularity: ~2 seconds of history at 2Hz

### 94 Cells (maximum)
- Bytes per string: 94 * 4 = 376 bytes
- Number of strings: 896 / 376 = 2 complete readings
- Granularity: ~1 second of history at 2Hz

## Key Design Decisions

1. **When to Advance**: Only advance after COMPLETE string (all expected cells received)
2. **What CAN Reports**: Always report the most recent COMPLETE reading, not partial
3. **Frame Number**: Increment on each complete reading for tracking
4. **Power Loss**: All readings preserved in frame, can recover history

## Testing Considerations

1. **Partial Strings**: If cells drop out, don't advance buffer (keep overwriting current slot)
2. **CAN Queries**: Ensure MODULE_DETAIL always returns valid data
3. **Buffer Wraparound**: Test that circular buffer properly wraps at nstrings boundary
4. **Frame Counter**: Verify frameNumber increments correctly

## Questions for Discussion

1. **Should we advance on partial strings?** Current proposal: NO - only complete strings
2. **Should frame number increment per reading or per SD write?** Current proposal: per reading
3. **Do we need a timestamp per reading or just per frame?** Current proposal: just per frame
4. **Should we clear the buffer slot before starting a new reading?** Current proposal: no need, we overwrite

## Risk Assessment
- **Low Risk**: Changes are additive, don't break existing functionality
- **Main Risk**: CAN responses during buffer transition (mitigated by GetLatestCompleteString)
- **Testing**: Can add debug counters to verify buffer cycling

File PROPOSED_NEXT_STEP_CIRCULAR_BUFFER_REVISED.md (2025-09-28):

# Revised Proposal: Circular Buffer with Partial String Handling

## Current State
- Cell data accessed directly from sg_sFrame.c buffer (896 bytes)
- Helper functions GetStringData() provide access to buffer
- Single string reading at start of buffer (legacy behavior preserved)
- System working and reporting to pack controller

## Key Change: Always Advance, Mark Invalid Cells

### 1. Define Invalid Cell Marker
**Location**: STORE.h or main.h

```c
// Invalid cell marker - set both voltage and temperature to max value
#define INVALID_CELL_VOLTAGE  0xFFFF
#define INVALID_CELL_TEMP     0x7FFF  // Max int16_t

// Or use existing discharge bit pattern if available
// #define INVALID_CELL_MARKER   0xFFFF
```

### 2. Initialize Buffer Slot with Invalid Markers
**Location**: main.c, at START of READ frame (before collecting cells)

```c
// At start of READ frame - mark ALL cells as invalid
volatile CellData* stringData = GetStringDataVolatile(&sg_sFrame);
for (uint8_t i = 0; i < sg_sFrame.m.sg_u8CellCountExpected; i++) {
    stringData[i].voltage = INVALID_CELL_VOLTAGE;
    stringData[i].temperature = INVALID_CELL_TEMP;
}

// As cells report in, they overwrite the invalid markers
// Any cells that don't report remain marked invalid
```

### 3. Always Advance After WRITE Frame
**Location**: main.c, at end of WRITE frame processing

```c
// After WRITE frame - advance buffer regardless of cell count
// This ensures we don't get stuck if cells are missing

// Note: sg_u8CellCPUCount tells us how many actually reported
// sg_u8CellCountExpected tells us how many we expected

// Store actual count for this reading (for diagnostics)
// Could add a field like actualCellCounts[nstrings] if needed

// Advance to next slot
sg_sFrame.m.currentIndex = (sg_sFrame.m.currentIndex + 1) % sg_sFrame.m.nstrings;

if (sg_sFrame.m.readingCount < sg_sFrame.m.nstrings) {
    sg_sFrame.m.readingCount++;
}

// Increment frame number for this reading (complete or partial)
sg_sFrame.m.frameNumber++;
```

### 4. Initialize nstrings Based on Cell Count
**Location**: main.c, ProcessCellExpectedCount() function

```c
void ProcessCellExpectedCount(uint8_t u8CellCountExpected)
{
    sg_sFrame.m.sg_u8CellCountExpected = u8CellCountExpected;

    // Calculate how many complete string readings fit in buffer
    uint16_t bytes_per_string = u8CellCountExpected * sizeof(CellData);

    if (bytes_per_string > 0) {
        sg_sFrame.m.nstrings = FRAME_CELLBUFFER_SIZE / bytes_per_string;

        // Ensure at least 1 string
        if (sg_sFrame.m.nstrings == 0) {
            sg_sFrame.m.nstrings = 1;
        }
    } else {
        sg_sFrame.m.nstrings = 1;
    }

    // Initialize circular buffer indices
    sg_sFrame.m.currentIndex = 0;
    sg_sFrame.m.readingCount = 0;

    // Clear entire buffer to invalid markers initially
    CellData* buffer = (CellData*)sg_sFrame.c;
    uint16_t totalCells = (FRAME_CELLBUFFER_SIZE / sizeof(CellData));
    for (uint16_t i = 0; i < totalCells; i++) {
        buffer[i].voltage = INVALID_CELL_VOLTAGE;
        buffer[i].temperature = INVALID_CELL_TEMP;
    }
}
```

### 5. CAN Response Handling for Invalid Cells
**Location**: main.c, MODULE_DETAIL message handler

```c
// When reporting cell data over CAN
volatile CellData* stringData = GetLatestCompleteString(&sg_sFrame);

// Check if this cell is valid
if (stringData[actualIndex].voltage == INVALID_CELL_VOLTAGE) {
    // Report invalid cell status
    // Could send special values or skip this cell
    u16Voltage = 0;  // Or some other indicator
    s16Temperature = 0;
    // Maybe set a flag in the message
} else {
    // Normal processing
    uint16_t u16RawVoltage = stringData[actualIndex].voltage;
    int16_t s16RawTemp = stringData[actualIndex].temperature;
    // ... rest of processing
}
```

## Benefits of This Approach

1. **Never Gets Stuck**: Always advances even if cells drop out
2. **Clear Invalid Data**: Invalid markers make it obvious which cells didn't report
3. **Complete History**: Can see pattern of cell dropouts over time
4. **Power Loss Safe**: Invalid markers persist in frame

## Invalid Cell Detection Examples

### Normal Operation (all cells report):
- Slot initialized with all INVALID markers
- All cells overwrite their markers with real data
- Buffer advances with complete data

### Cell 5 Not Reporting:
- Slot initialized with all INVALID markers
- Cells 0-4, 6-N overwrite with real data
- Cell 5 remains INVALID_CELL_VOLTAGE/INVALID_CELL_TEMP
- Buffer advances, preserving record that cell 5 was missing

### Multiple Cells Missing:
- Each missing cell retains its INVALID marker
- Pack controller can see exactly which cells are problematic

## Testing Considerations

1. **Verify Invalid Markers**: Check that non-reporting cells show invalid
2. **CAN Message Handling**: Ensure pack controller handles invalid cell markers
3. **Statistics**: sg_u8CellCPUCount still tracks actual cells received
4. **Buffer Analysis**: Can scan buffer to see dropout patterns

## Summary of Changes

1. Always initialize slots with invalid markers at READ start
2. Always advance buffer at WRITE end (not conditional)
3. CAN responses check for and handle invalid markers
4. Pack controller can track cell reliability over time

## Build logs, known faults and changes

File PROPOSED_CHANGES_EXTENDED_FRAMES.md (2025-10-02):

# Proposed Changes: Extended Frame Addressing

## Current Implementation

**MOB Configuration:**
- MOB 0 (RX): Filters 0x500-0x5FF (mask 0x700), receives ALL module protocol messages
- MOB 1 (TX): Transmit with module ID in bits 0-7 of extended ID
- Extended frames enabled (IDE=1)

**Message Routing:**
- All modules hear all messages
- Module-specific messages have module ID in first data byte
- Module checks data byte to see if message is for them

**Problems:**
- Inefficient: All modules process all messages
- Module protocol messages visible to all modules (including responses)
- Wastes CPU time on irrelevant messages

## Proposed Implementation

**MOB Configuration (per protocol documentation):**

### UNREGISTERED STATE:
- MOB 0 (RX): Filter extended ID bits 0-7 = 0xFF (unregistered-specific messages)
- MOB 1 (TX): Transmit with extended ID bits 0-7 = 0xFF
- MOB 2 (RX): Filter extended ID bits 0-7 = 0x00 (broadcast messages) - **ALWAYS ENABLED**

### REGISTERED STATE (e.g., assigned ID = 5):
- MOB 0 (RX): Filter extended ID bits 0-7 = 0x05 (my specific messages)
- MOB 1 (TX): Transmit with extended ID bits 0-7 = 0x05
- MOB 2 (RX): Filter extended ID bits 0-7 = 0x00 (broadcast messages) - **UNCHANGED**

### ON DEREGISTRATION:
- MOB 0 (RX): Reset filter to extended ID bits 0-7 = 0xFF
- MOB 1 (TX): Transmit with extended ID bits 0-7 = 0xFF
- MOB 2 (RX): Still enabled at 0x00 (unchanged)

**Message Addressing:**
- 0x00 = Broadcast to all registered modules
- 0x01-0x1F = Specific module (1-31)
- 0xFF = Unregistered modules only

**Benefits:**
- Hardware filtering isolates traffic
- Modules don't hear each other's responses
- Reduced interrupt load
- Cleaner protocol

## Code Changes Required

### 1. Add MOB 2 for Broadcast Reception

**New MOB definition:**
```c
static const SMOBDef sg_sMOBBroadcastReceive =
{
    CAN_RXONLY,
    false,
    0x500,          // Base ID (0x5xx range)
    0x700,          // Mask for base ID
    false,
    false,
};
```

**Configuration in CANInit():**
```c
// MOB 2 always configured for broadcast (ID = 0x00)
CANMOBSet(2, &sg_sMOBBroadcastReceive, NULL, 0);
```

### 2. Update MOB Filter Configuration

**Modify CANMOBSet() to accept module ID filter parameter:**

Currently CANMOBSet encodes the module's own ID in transmitted frames. Need to also accept a target module ID for RX filtering.

**Option A: Add parameter to SMOBDef**
```c
typedef struct
{
    uint8_t u8Mode;
    bool bReplyValid;
    uint16_t u16ID;           // Base ID (0x510, 0x517, etc.)
    uint16_t u16IDMask;       // Base ID mask
    uint8_t u8ModuleIDFilter; // Module ID to filter on (0x00, 0xFF, or assigned ID)
    uint8_t u8ModuleIDMask;   // Module ID mask (0xFF for exact match)
    bool bRTRTag;
    bool bRTRMask;
} SMOBDef;
```

**Option B: Separate function for RX MOB configuration**
```c
static void CANMOBSetRX(uint8_t u8MOBIndex,
                        const SMOBDef* psDef,
                        uint8_t u8TargetModuleID);
```

### 3. Update MOB Configuration on Registration/Deregistration

**On Registration (main.c:1309):**
```c
// Assign the new registration ID
sg_u8ModuleRegistrationID = u8RegID;

// Reconfigure MOB 0 to filter on assigned ID
CANMOBSetRX(CANMOB_RX_IDX, &sg_sMOBGenericReceive, u8RegID);
```

**On Deregistration:**
```c
sg_u8ModuleRegistrationID = 0;
sg_bModuleRegistered = false;

// Reconfigure MOB 0 back to 0xFF (unregistered)
CANMOBSetRX(CANMOB_RX_IDX, &sg_sMOBGenericReceive, 0xFF);
```

### 4. Update RX Message ID Extraction

**Current code (can.c:497-498):**
```c
u16ID = ((uint16_t)CANIDT1) << 3;
u16ID |= CANIDT2 >> 5;
```

This extracts base ID from extended frame, which is correct. The module ID filtering is done by hardware, so no changes needed here.

### 5. Remove Module ID from Data Bytes

**Current:** Module-specific messages have module ID in first data byte.

**New:** Module ID only in extended frame, not in data.

This affects:
- main.c:1336-1344 - Module-specific message handling
- All message structures in protocol headers

## Implementation Steps

1. **Add MOB 2 broadcast receive configuration**
   - Define sg_sMOBBroadcastReceive
   - Configure in CANInit()
   - Add MOB 2 handling in interrupt

2. **Modify MOB filtering**
   - Add module ID filter parameter to SMOBDef or create separate RX config function
   - Update CANMOBSet() to configure module ID filtering in extended ID bits 0-7

3. **Update registration/deregistration**
   - Reconfigure MOB 0 filter on registration
   - Reconfigure MOB 0 filter on deregistration
   - Initialize MOB 0 to 0xFF in CANInit()

4. **Remove module ID from message data**
   - Update message handlers to not expect module ID in data[0]
   - Update protocol structures (future step, separate from MOB changes)

## Questions for Discussion

1. **MOB Configuration Approach**: Option A (add to SMOBDef) vs Option B (separate RX function)?
   - Option A: Cleaner, single configuration structure
   - Option B: Less impact on existing TX code

2. **Message Data Changes**: Should we remove module ID from data bytes in this change, or keep that separate?
   - Recommend: Keep separate. First get MOB filtering working, then update message formats.

3. **Interrupt Handling**: MOB 2 will trigger same interrupt as MOB 0/1. Need to handle both RX MOBs in CANMOBInterrupt().
   - Current code has CANMOB_RX_IDX hardcoded
   - Need to handle both MOB 0 and MOB 2 as RX

4. **Testing**: How to verify MOB filtering is working correctly?
   - Test unregistered: Should only receive 0xFF and 0x00 messages
   - Test registered: Should receive assigned ID and 0x00 messages
   - Test isolation: Module 1 shouldn't hear Module 2's responses

## Recommended Approach - AGREED

**Phase 1: MOB Configuration (this change)**
1. Add MOB 2 for broadcast (configured once in CANInit)
2. Add function `CANSetModuleIDFilter(uint8_t u8ModuleID)` to reconfigure MOB 0 filter
3. Call in registration/deregistration to update MOB 0 filter
4. Keep existing message format (module ID still in data) - no changes to message handlers

**Phase 2: Message Format (future change)**
1. Remove module ID from data bytes
2. Update all message handlers
3. Update protocol structures
4. Test integration

## Implementation Details for Phase 1

### New Function
```c
void CANSetModuleIDFilter(uint8_t u8ModuleID)
{
    uint8_t savedCANGIE;

    // Disable CAN interrupts during MOB reconfiguration
    savedCANGIE = CANGIE;
    CANGIE &= ~(1 << ENIT);

    // Set MOB 0 page
    CANPAGE = CANMOB_RX_IDX << 4;

    // Temporarily disable MOB 0
    CANIE2 &= ~(1 << CANMOB_RX_IDX);
    CANCDMOB &= ~((1 << CONMOB0) | (1 << CONMOB1));

    // Update extended ID filter (bits 0-7 = module ID)
    // Keep base ID (bits 18-28) unchanged at 0x500/0x700 mask
    uint32_t u32MessageID = (uint32_t)u8ModuleID;
    u32MessageID |= (((uint32_t)0x500) & 0x7ff) << 18;

    CANIDT4 = (u32MessageID << 3);
    CANIDT3 = u32MessageID >> 5;
    CANIDT2 = u32MessageID >> 13;
    CANIDT1 = u32MessageID >> 21;

    // Set mask: bits 0-7 must match exactly (0xFF), bits 18-28 use 0x700 mask
    CANIDM4 = (1 << IDEMSK);  // Extended frame mask
    CANIDM4 |= 0xFF << 3;     // Module ID bits 0-7 must match exactly
    CANIDM3 = 0xFF >> 5;      // Continue module ID mask
    CANIDM2 = 0x700 << 5;     // Base ID mask
    CANIDM1 = 0x700 >> 3;

    // Re-enable RX mode
    CANCDMOB = 8 | (1 << CONMOB1) | (1 << IDE);  // 8 bytes, RX mode, extended frame
    CANIE2 |= (1 << CANMOB_RX_IDX);

    // Restore CAN interrupts
    CANGIE = savedCANGIE;
}
```

### CANInit() Changes
```c
void CANInit(void)
{
    // ... existing init code ...

    // Setup MOB 0 for unregistered (0xFF) reception
    CANMOBSet(CANMOB_RX_IDX, &sg_sMOBGenericReceive, NULL, 0);
    CANSetModuleIDFilter(0xFF);  // Start unregistered

    // Setup MOB 2 for broadcast (0x00) reception - ALWAYS ENABLED
    CANMOBSet(2, &sg_sMOBGenericReceive, NULL, 0);
    CANSetModuleIDFilter(0x00);  // Broadcast

    // ... rest of init ...
}
```

Wait, that won't work - CANSetModuleIDFilter() sets MOB 0, not MOB 2. Need separate approach for MOB 2.

### Better Approach: Add MOB index parameter

```c
void CANSetModuleIDFilter(uint8_t u8MOBIndex, uint8_t u8ModuleID)
{
    // Same code but parameterized on u8MOBIndex
    CANPAGE = u8MOBIndex << 4;
    CANIE2 &= ~(1 << u8MOBIndex);
    // ... rest same ...
    CANIE2 |= (1 << u8MOBIndex);
}
```

### Usage
```c
// In CANInit():
CANSetModuleIDFilter(CANMOB_RX_IDX, 0xFF);  // MOB 0: unregistered
CANSetModuleIDFilter(2, 0x00);               // MOB 2: broadcast

// In registration:
CANSetModuleIDFilter(CANMOB_RX_IDX, u8RegID);  // MOB 0: my ID

// In deregistration:
CANSetModuleIDFilter(CANMOB_RX_IDX, 0xFF);     // MOB 0: back to unregistered
```

### Interrupt Handler Changes
```c
ISR(CAN_INT_vect, ISR_BLOCK)
{
    // ... existing code ...

    uint8_t sit = CANSIT2;

    // Check MOB 0 (module-specific RX)
    if(sit & (1 << CANMOB_RX_IDX)) {
        CANMOBInterrupt(CANMOB_RX_IDX);
        CANMOBSet(CANMOB_RX_IDX, &sg_sMOBGenericReceive, NULL, 0);
    }

    // Check MOB 2 (broadcast RX)
    if(sit & (1 << 2)) {
        CANMOBInterrupt(2);
        CANMOBSet(2, &sg_sMOBGenericReceive, NULL, 0);
    }

    // Check TX MOB
    if(sit & (1 << CANMOB_TX_IDX)) {
        CANMOBInterrupt(CANMOB_TX_IDX);
    }

    // ... rest of interrupt handler ...
}
```

This keeps changes minimal and focused on MOB filtering only.

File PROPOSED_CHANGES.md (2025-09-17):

# Proposed CAN Fixes for ModuleCPU

## Problems Identified

### 1. Hardware Detail Flag Never Clears
**Issue**: `sg_bSendHardwareDetail` flag is set but never clears, causing continuous retries.

**Root Cause**: 
- In `main.c:2009-2032`, the flag only clears if `CANSendMessage()` returns true
- `CANSendMessage()` returns false if `sg_bBusy` is true
- If CAN bus is busy, the hardware detail keeps trying to send forever

### 2. Incorrect sg_bBusy Clearing in RX MOB Context
**Issue**: In `can.c:369`, sg_bBusy is incorrectly cleared in the RX MOB interrupt handler when TXOK is set.

**Location**: `can.c:365-369`
```c
// TX success?  Just clear it since this is the RX context
if( CANSTMOB & (1 << TXOK) )
{
    // Clear it
    CANSTMOB &= ~(1 << TXOK);
    sg_bBusy = false;  // <-- WRONG! This is RX context, not TX
}
```

This can cause race conditions where sg_bBusy is cleared prematurely while a transmission is still in progress.

### 3. Module Goes Quiet / Stuck in CAN ISR
**Symptoms**: 
- Module stops responding to CAN messages
- When paused, execution is in CAN interrupt code
- Hardware detail flag never clears

**Likely Cause**: The incorrect sg_bBusy handling creates a deadlock scenario where:
1. TX starts, sg_bBusy = true
2. RX MOB incorrectly clears sg_bBusy
3. New TX starts while previous TX still active
4. CAN peripheral gets confused with overlapping operations
5. System gets stuck in ISR trying to handle error conditions

## Proposed Solutions

### Fix 1: Remove Incorrect sg_bBusy Clear in RX Context
```c
// can.c:365-369
// TX success?  Just clear it since this is the RX context
if( CANSTMOB & (1 << TXOK) )
{
    // Clear it
    CANSTMOB &= ~(1 << TXOK);
    // sg_bBusy = false;  // REMOVE THIS LINE - TX completion handled in TX MOB
}
```

### Fix 2: Add Retry Counter for Hardware Detail
```c
// In main.c, add counter near sg_bSendHardwareDetail declaration:
static uint8_t sg_u8HardwareDetailRetries = 0;

// Modify main.c:2009-2032
if (sg_bSendHardwareDetail)
{
    bool bSuccess;
    
    // ... existing code to build response ...
    
    bSuccess = CANSendMessage( ECANMessageType_ModuleHardwareDetail, pu8Response, CAN_STATUS_RESPONSE_SIZE );
    
    if (bSuccess)
    {
        sg_bSendHardwareDetail = false;
        sg_u8HardwareDetailRetries = 0;  // Reset counter on success
    }
    else
    {
        // Increment retry counter
        sg_u8HardwareDetailRetries++;
        if (sg_u8HardwareDetailRetries > 100)  // Give up after 100 attempts
        {
            sg_bSendHardwareDetail = false;
            sg_u8HardwareDetailRetries = 0;
        }
    }
}
```

### Fix 3: Add Watchdog Reset for CAN Peripheral Recovery
As a safety measure, if the CAN peripheral gets stuck, the watchdog should reset the system. This is already in place but we should verify it's enabled properly.

## Testing Plan

1. **Verify Hardware Detail Sends Once**: Monitor CAN bus to confirm hardware detail message is sent exactly once when requested
2. **Stress Test**: Send rapid status requests to verify no lockups
3. **Monitor sg_bBusy**: Add debug output to track sg_bBusy state transitions
4. **Long Duration Test**: Run for extended period to verify no gradual degradation

## Risk Assessment

- **Low Risk**: Removing the incorrect sg_bBusy clear in RX context - this line is clearly wrong
- **Medium Risk**: Adding retry limit - need to ensure 100 retries is sufficient for worst-case bus congestion
- **Overall Impact**: These fixes should eliminate the module going quiet and stuck in CAN ISR issues

## Next Steps

1. Review and discuss these proposed changes
2. Implement fixes after approval
3. Test on hardware
4. Monitor for improvements in reliability

---

# Previous Content: VUART Edge-Triggered Timing Correction

[Previous VUART and Pack Controller content preserved below...]

## Current Implementation Analysis

The current VUART receive implementation:
1. **Start bit detection**: INT1 interrupt on falling edge (start bit)
2. **Initial timing**: Sets timer to `VUART_BIT_TICKS + VUART_BIT_START_OFSET` to sample middle of first data bit
3. **Subsequent bits**: Timer fires every `VUART_BIT_TICKS - VUART_BIT_TICK_OFFSET` to sample remaining bits
4. **Fixed timing**: No adjustment during byte reception - relies on initial synchronization

### Current Timing Constants
- `VUART_BIT_START_OFSET = 9`: Added to first bit timing
- `VUART_BIT_TICK_OFFSET = 7`: Subtracted from subsequent bit timings

## Problem Statement

Current implementation has no mechanism to correct for:
- Clock frequency differences between sender and receiver
- Timing drift during multi-byte transfers
- Jitter in the signal
- Temperature-induced clock variations

## Proposed Solution: Edge-Triggered Timing Correction

### 1. Core Concept
During data bit reception, detect edges (transitions) and use them to resynchronize the sampling timer to maintain center-of-bit sampling.

### 2. Implementation Approach

#### A. Add Edge Detection During Bit Reception
```c
// In TIMER0_COMPB ISR, after sampling the bit:
bool bData = IS_PIN_RX_ASSERTED();

// Detect edge (transition from previous bit)
if (bData != sg_bCell_mc_rxPriorState) {
    // Edge detected - calculate timing error
    uint8_t currentTimer = TCNT0;
    uint8_t expectedTimer = OCR0B - (VUART_BIT_TICKS/2);
    int8_t timingError = currentTimer - expectedTimer;
    
    // Apply correction if significant
    if (abs(timingError) > TIMING_TOLERANCE) {
        // Adjust next sample time to recenter
        OCR0B = TCNT0 + (VUART_BIT_TICKS/2) - (timingError/2);
    }
    
    // Update statistics
    if (timingError < sg_minTimingError) sg_minTimingError = timingError;
    if (timingError > sg_maxTimingError) sg_maxTimingError = timingError;
}
```

#### B. New Variables Required
```c
// Timing correction statistics
static int8_t sg_minTimingError;     // Minimum timing error seen
static int8_t sg_maxTimingError;     // Maximum timing error seen
static uint16_t sg_edgeCorrections;  // Count of corrections applied
static uint8_t sg_lastEdgeTimer;     // Timer value at last edge

// Configuration
#define TIMING_TOLERANCE 3    // Only correct if error > 3 timer ticks
#define MAX_CORRECTION 5      // Maximum correction per edge (prevent oscillation)
```

#### C. Statistics Reset
```c
// In vUARTInitReceive() or when starting new reception:
sg_minTimingError = 127;
sg_maxTimingError = -128;
sg_edgeCorrections = 0;
```

### 3. Alternative Approaches Considered

#### Option A: Full PLL-style tracking (Complex)
- Continuously adjust sampling rate based on average edge timing
- More complex but potentially more accurate
- Risk: May overcorrect for noise

#### Option B: Simple edge resync (Proposed above - Moderate)
- Adjust timing only when edges detected
- Balance between simplicity and effectiveness
- Lower risk of instability

#### Option C: Edge validation before correction (Conservative)
- Only correct if multiple consecutive edges show similar error
- Most stable but may miss short-term corrections
- Best for noisy environments

### 4. Benefits
1. **Improved reliability**: Better tolerance for clock differences
2. **Self-correcting**: Automatically compensates for drift
3. **Diagnostic data**: Error statistics help identify problematic modules
4. **Backwards compatible**: No protocol changes required

### 5. Risks and Mitigations

| Risk | Impact | Mitigation |
|---|---|---|
| Edge noise causes false corrections | Data corruption | Add edge validation/filtering |
| Overcorrection causes oscillation | Timing instability | Limit maximum correction per edge |
| Extra processing in ISR | Missed bits | Keep correction logic minimal |
| Statistics overflow | Memory corruption | Use appropriate data types |

### 6. Testing Plan
1. Test with known clock offset (±5% frequency difference)
2. Test with temperature cycling (clock drift)
3. Test with noise injection on RX line
4. Verify statistics collection accuracy
5. Performance testing (ISR execution time)

## Recommendation

Implement **Option B (Simple edge resync)** as it provides:
- Good improvement in reliability
- Moderate complexity
- Low risk of instability
- Easy to debug with statistics

---

# Previous Content: Persistent Module Records with Registration Status

## Better Solution: Persistent Module Records
Instead of removing modules from the array, keep them and track registration status. This handles intermittent modules gracefully.

## Implementation

### 1. Add registration status to module structure
In `/mnt/c/projects/ai-agents/Pack-Controller-EEPROM/Core/Inc/bms.h`:
```c
typedef struct {
  // ... existing fields ...
  bool        isRegistered;     // Module currently registered
  // ... rest of fields ...
}batteryModule;
```

### 2. Modify deregistration to just mark as unregistered
In PCU_Tasks timeout handling (~line 357):
```c
// Instead of removing from array:
// Mark module as deregistered
module[index].isRegistered = false;

// Don't shift array or change pack.moduleCount
// Continue to next module without adjusting index
```

### 3. Update registration logic
In MCU_RegisterModule (~line 1040):
```c
// Check if module already exists (registered or not)
moduleIndex = MAX_MODULES_PER_PACK; // Invalid index
for(index = 0; index < MAX_MODULES_PER_PACK; index++){
    if(module[index].uniqueId == announcement.moduleUniqueId){
        moduleIndex = index;
        break;
    }
}

if(moduleIndex < MAX_MODULES_PER_PACK){
    // Existing module - just mark as registered
    module[moduleIndex].isRegistered = true;
    module[moduleIndex].faultCode.commsError = 0;
    // ... reset timeouts etc
    
    if(debugMessages & DBG_MSG_ANNOUNCE){
        sprintf(tempBuffer,"MCU INFO - Module RE-REGISTERED: Index=%d, ID=%02x, UID=%08x",
                moduleIndex, module[moduleIndex].moduleId, announcement.moduleUniqueId);
        serialOut(tempBuffer);
    }
}
else {
    // New module - find first empty slot
    for(index = 0; index < MAX_MODULES_PER_PACK; index++){
        if(module[index].uniqueId == 0){  // Empty slot
            moduleIndex = index;
            break;
        }
    }
    
    if(moduleIndex < MAX_MODULES_PER_PACK){
        // Initialize new module
        module[moduleIndex].moduleId = moduleIndex + 1;  // ID = index + 1
        module[moduleIndex].uniqueId = announcement.moduleUniqueId;
        module[moduleIndex].isRegistered = true;
        // ... rest of initialization
        
        // Update pack.moduleCount to highest registered module
        pack.moduleCount = 0;
        for(int i = 0; i < MAX_MODULES_PER_PACK; i++){
            if(module[i].isRegistered && module[i].uniqueId != 0){
                pack.moduleCount++;
            }
        }
    }
}
```

### 4. Update all module iterations to check registration
Everywhere we iterate through modules:
```c
for(index = 0; index < MAX_MODULES_PER_PACK; index++){
    if(!module[index].isRegistered || module[index].uniqueId == 0) continue;
    // ... process module
}
```

### 5. Update module finding functions
```c
uint8_t MCU_ModuleIndexFromId(uint8_t moduleId){
    for(index = 0; index < MAX_MODULES_PER_PACK; index++){
        if(module[index].moduleId == moduleId && module[index].isRegistered)
            return index;
    }
    return MAX_MODULES_PER_PACK; // Not found
}
```

## Benefits
1. Module IDs never change once assigned
2. Handles intermittent connections gracefully
3. No array shifting complications
4. Module history is preserved
5. Can track metrics across connect/disconnect cycles
6. Simpler logic overall

## Module Counting
```c
// Add to pack structure:
uint8_t totalModules;    // Count of all modules ever seen (non-empty slots)
uint8_t activeModules;   // Count of currently registered modules

// Update counts whenever registration changes:
void MCU_UpdateModuleCounts(void){
    pack.totalModules = 0;
    pack.activeModules = 0;
    
    for(int i = 0; i < MAX_MODULES_PER_PACK; i++){
        if(module[i].uniqueId != 0){
            pack.totalModules++;
            if(module[i].isRegistered){
                pack.activeModules++;
            }
        }
    }
}
```

When reporting to host controller:
- Total modules = all modules that have ever connected (pack.totalModules)
- Active modules = currently registered modules (pack.activeModules)
- This helps diagnose intermittent connection issues

## Notes
- pack.moduleCount can be deprecated or repurposed
- Module slots are reused based on unique ID
- Empty slots have uniqueId = 0
- Host sees both "modules that exist" and "modules currently online"

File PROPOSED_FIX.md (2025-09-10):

# Proposed Fix for ModuleCPU Initialization Issues

## Problems Identified

### 1. Max Cells Reporting 170 (0xAA)
**Root Cause**: In `MODULE_CELL_COMM_STATUS` message, `sg_sFrame.sg_u8CellCPUCountMost` is being sent with value 170 (0xAA).

**Analysis**: 
- After full init, `memset(&sg_sFrame, 0, sizeof(sg_sFrame))` clears everything to 0
- Code then sets `sg_u8CellCPUCountFewest = 0xff` but doesn't reset `sg_u8CellCPUCountMost`
- However, memset should have set it to 0, not 0xAA
- The 0xAA pattern suggests uninitialized memory or corruption

**Likely issue**: The StringData array might contain uninitialized data that's being misinterpreted. When we disabled clearing StringData in partial init to preserve cell data for MODULE_DETAIL responses, we may have exposed an initialization issue.

### 2. Module Voltage Stuck at 29.25V
**Root Cause**: MODULE_STATUS_1 reports voltage as 1950 (0x079E) in 0.015V units = 29.25V

**Analysis**:
- The voltage calculation uses ADC reading: `u32Voltage = (1 << ADC_BITS) - 1 - sg_sFrame.ADCReadings[EADCTYPE_STRING].u16Reading`
- Then multiplies by `sg_i16VoltageStringPerADC` and adds `sg_i32VoltageStringMin`
- 29.25V seems like a suspiciously round number (1950 * 0.015)

## Proposed Solutions

### Fix 1: Properly Initialize sg_u8CellCPUCountMost
In `FrameInit()` after the memset in full init:
```c
if (bFullInit || (FRAME_VALID_SIG != sg_sFrame.validSig)) {
    memset(&sg_sFrame, 0, sizeof(sg_sFrame));
    sg_sFrame.frameBytes = sizeof(sg_sFrame);
    sg_sFrame.validSig = FRAME_VALID_SIG;
    sg_sFrame.moduleUniqueId = ModuleControllerGetUniqueID();
    sg_sFrame.sg_u8CellFirstI2CError = 0xff;
    sg_sFrame.sg_u8CellCPUCountFewest = 0xff;
    sg_sFrame.sg_u8CellCPUCountMost = 0;  // ADD THIS LINE - explicitly init to 0
    CellCountExpectedSet(EEPROMRead(EEPROM_EXPECTED_CELL_COUNT));
}
```

### Fix 2: Check for Invalid ADC Reading
The ADC might not be initialized properly. Add validation:
```c
// In MODULE_STATUS_1 voltage calculation
if (!sg_sFrame.ADCReadings[EADCTYPE_STRING].bValid) {
    // ADC not valid, use cell voltage total if available
    if (sg_sFrame.sg_u32CellVoltageTotal > 0) {
        u32Voltage = sg_sFrame.sg_u32CellVoltageTotal / 15;
    } else {
        u32Voltage = 0;  // No valid voltage available
    }
} else {
    // existing ADC calculation code
}
```

### Fix 3: Initialize StringData Properly on Full Init
Since StringData is now preserved across partial inits, we should ensure it's properly initialized on full init:
```c
if (bFullInit || (FRAME_VALID_SIG != sg_sFrame.validSig)) {
    memset(&sg_sFrame, 0, sizeof(sg_sFrame));
    // ... other initialization ...
    
    // Initialize StringData to known safe values
    for (int i = 0; i < MAX_CELLS; i++) {
        sg_sFrame.StringData[i].voltage = 0;
        sg_sFrame.StringData[i].temperature = TEMPERATURE_BASE;  // 0°C in raw format
    }
}
```

## Alternative Hypothesis

The 0xAA pattern (10101010 binary) is often used as:
1. **Stack guard pattern** - to detect stack overflows
2. **Uninitialized heap pattern** - in debug builds
3. **EEPROM default** - unprogrammed EEPROM often reads as 0xFF or 0xAA

Given that sg_u8CellCPUCountMost shows 170 (0xAA) instead of an expected value, this might indicate:
- Memory corruption overwriting the value
- Reading from wrong memory location
- Uninitialized EEPROM being read somewhere

## Recommended Action

1. **First**: Add explicit initialization of `sg_u8CellCPUCountMost = 0` after memset
2. **Second**: Verify ADC initialization and add validation 
3. **Third**: Add diagnostic CAN message to report these values during init
4. **Monitor**: Check if 0xAA appears elsewhere to identify pattern

## Testing Plan

1. Flash the fix
2. Power cycle the module completely
3. Check initial MODULE_CELL_COMM_STATUS message
4. Verify voltage reading in MODULE_STATUS_1
5. Ensure MODULE_DETAIL still works correctly with preserved cell data

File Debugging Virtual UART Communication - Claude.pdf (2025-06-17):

D ok, i've uploaded the full code for the module controller. the part i'm currently debugging is the functionality of the VUART that talks to the cell string. see how much you can glean from the code and we'll go from there.

I'll analyze the UART communication implementation from the code. Here are the key points about the virtual UART implementation:
Key Implementation Details:
1. It's a software (bit-banged) UART using Timer0 for timing
2. Data format is:
1 start bit (asserted)
8 data bits
1 stop bit (1=more data coming, 0=end of transmission) 1 guard bit (always deasserted for transition timing)
3. Pin Configuration:
MC RX (PB2) - Receives cell status (upstream)
MC TX (PB3) - Sends messages downstream
4. Timing:
Uses Timer0 for bit timing
VUART_BIT_TICKS defines the bit period
Has empirically determined offsets (VUART_BIT_TICK_OFFSET, VUART_BIT_START_OFSET) to account for overhead
5. Reception Process:
RX pin falling edge triggers GPIO interrupt
Timer set to sample in middle of first bit
Timer interrupt samples subsequent bits
Builds byte in sg_u8rxDataByte
Tracks more-data flag in sg_bCell_mc_rxMoreData
6. Transmission Process:
Can send single bytes or patterns
Uses timer for bit timing

Handles CellReportsRequested flag differently
Early termination after command bits if requesting cell reports

The main challenges/areas to watch:
1. Timing precision - The bit timing offsets are empirical and may need tuning
2. Edge detection reliability on RX
3. Proper handling of the more-data flag
4. State machine transitions between idle/rx/tx states
Would you like me to dig deeper into any particular aspect? For example, we could:
1. Look at specific timing calculations
2. Analyze the state machine transitions
3. Review the interrupt handlers
4. Examine the buffer management
Let me know what area you'd like to focus on for debugging.

D overall, the state machine is functional and has in some cases run reliably for extended periods with all 94 cells reporting. your analysis of timing precision is astute - that appears to be the failure mode. in the past, tweaking the empirical parameters was what made the difference between working and not working, but now without changing those it is highly unreliable. only sees 1-2 cells, sometimes gets correct data for those it sees, sometimes not. while the read is occurring, there is CAN communication taking place at 5Hz. that may be impacting the overhead timing.

Ah, this is a valuable insight. The interaction between CAN interrupts and the bit-banged UART timing is likely the key issue. Let's analyze:
1. The VUART timing is dependent on precise timer interrupts for bit sampling:

// Timer 0 compare B interrupt (bit clock) for mc rx from the cell CPUs ISR(TIMER0__COMPB__vect,, ISR__BLOCK)
{
// Set the timer to the next bit. The subtracted value is empirically // measured to ensure the per-bit time matches VUART_BIT_TICKS

c

Copy

2. The CAN interrupt is also running:

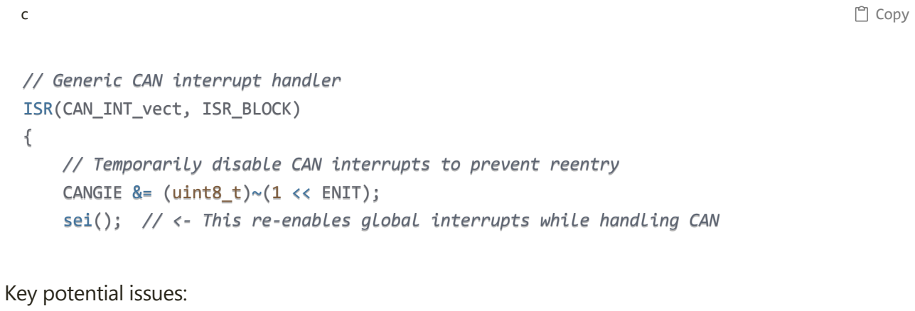
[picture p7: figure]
Key potential issues:; //// GGeenneerriicc CCAANN iinntteerrrruupptt hhaannddlleerr ISR(CCAANN__IINNTT__vveecctt,, IISSRR__BBLLOOCCKK) {; CCAANNGGIIEE &== (uuiinntt88__tt)~~(1 <<<< ENIT);; Copy

1. Even though the VUART interrupt uses ISR_BLOCK, the CAN handler explicitly re-enables global interrupts with sei(). This means a CAN interrupt could inject variable timing delays into the VUART bit sampling.
2. At 5Hz CAN rate with potentially multiple messages per update (status1, status2, status3), we're getting regular interrupt preemption that wasn't as frequent when the system was working reliably.
Possible solutions to explore:
1. Make the VUART timing more robust against interruption:
2. Temporarily disable CAN during VUART reception:

// microseconds and accounts for CPU/interrupt/preamble overhead. TIMER__CHB__INT(VUART__BIT__TICKS--VUART__BIT__TICK__OFFSET);

// Temporarily disable CAN interrupts to prevent reentry

sseei(); // <- This re-enables global interrupts while handling CAN

// In Timer0 compare B interrupt
ISR(TIMER0__COMPB__vect,, ISR__BLOCK)
{
uint8_t timer_val = TCNT0; // Capture timer value immediately
// Calculate next interval accounting for time spent in interrupts uint16_t next_interval = VUART_BIT_TICKS - (timer__val - last__timer__val); TIMER__CHB__INT(next__interval);
last_timer_val = timer__val;

c

Copy

c

Copy

Claude does not have the ability to run the code it generates yet.

3. Add instrumentation to measure interrupt timing impact:

Would you like me to elaborate on any of these approaches? We could also:
1. Look at ways to reduce CAN interrupt frequency during VUART operations
2. Analyze the exact timing requirements for reliable cell communication
3. Consider restructuring the VUART to be more resilient to interrupt jitter vvooid vvUUAARRTTIInniittRReecceeiivvee(vvooid)
{
// Save CAN state
uint8_t can_state = CANGIE;
// Disable CAN interrupts during VUART reception CANGIE &== ~~(1 << ENIT);

// Enable receives
VUART__RX__ENABLE();

// Queue timer to restore CAN after expected reception time // Or handle in end-of-message processing
}

ISR(TIMER0__COMPB__vect,, ISR__BLOCK) {
static uint8_t last_timer = 0;
uint8_t current_timer = TCNT0;
uint8_t delta = current_timer - last__timer; if(delta > max__observed__delta) { max_observed_delta = delta;
}
last_timer = current__timer;

c

Copy

D excellent, thank you. let me try your suggestions first, then we can continue.

Good luck! When you return, it would be helpful to know:
1. Which approach(es) you tried

2. Any changes in behavior (even if not fully fixed)
3. If you used the timing instrumentation, what maximum deltas you observed
This will help us refine the approach further. One additional thing to consider while testing - the current code uses Timer 0 for both virtual UART edges and sampling. We could potentially make the system more robust by using separate timer channels for edge detection vs bit sampling if the current approaches don't fully solve the issue.

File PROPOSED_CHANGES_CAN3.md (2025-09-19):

# Critical CAN Fix - TX MOB Not Re-enabled

## Issue Found
In `CANMOBInterrupt()`, the MOB is disabled at the start:
```c
// Line 359-360
CANIE2 &= (uint8_t)~(1 << u8MOBIndex);
CANCDMOB &= (uint8_t)~((1 << CONMOB0) | (1 << CONMOB1));
```

The RX MOB is properly re-enabled at the end of its handler:
```c
// Line 430-431
CANIE2 |= (1 << u8MOBIndex);
CANCDMOB |= (1 << CONMOB1);
```

**BUT the TX MOB is NEVER re-enabled!** The TX handler ends at line 471 without re-enabling.

## Impact
- TX MOB stays disabled after first transmission
- Module can receive but not transmit after first TX
- This explains why the module "goes quiet" - it literally can't send anymore!

## Proposed Fix
Add TX MOB re-enable at the end of TX handler:

```c
// At line 471, after the TX MOB handler, add:
else if( CANMOB_TX_IDX == u8MOBIndex )
{
    // ... existing TX handling code ...
    
    // Re-enable TX MOB (THIS IS MISSING!)
    // For TX, we just re-enable interrupts, don't set CONMOB bits
    // as TX is one-shot operation
    CANIE2 |= (1 << u8MOBIndex);
}
```

Actually, looking closer, we might not need to re-enable TX MOB for interrupts since TX is typically one-shot. But we should verify this is intentional.

## Alternative Analysis
It's possible TX MOB doesn't need re-enabling because:
1. TX is one-shot operation
2. New TX is initiated by CANMOBSet() which would set everything up fresh
3. But then why disable it in the first place?

## Recommendation
1. Either remove the disable for TX MOB at the start
2. OR add proper re-enable at the end
3. Test both approaches to see which works better

This could be THE bug causing all our CAN reliability issues!

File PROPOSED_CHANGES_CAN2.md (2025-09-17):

# Additional CAN Fix - Remove TX Handling from RX MOB

## Issue
We're still checking and clearing TXOK status bit in the RX MOB handler. This doesn't make sense - the RX MOB should only handle RX events, not TX status.

## Current Code (can.c lines 364-376)
```c
if( CANMOB_RX_IDX == u8MOBIndex )
{
    // TX success?  Just clear it since this is the RX context
    if( CANSTMOB & (1 << TXOK) )
    {
        // Clear it
        CANSTMOB &= ~(1 << TXOK);
        // [comments about not clearing sg_bBusy]
    }
    // RX success?
    if( CANSTMOB & (1 << RXOK) )
    {
        // ... handle RX
```

## Problem Analysis
1. **RX MOB shouldn't see TX status**: If we're in the RX MOB interrupt handler, we shouldn't be seeing TX status bits
2. **Possible hardware quirk**: Maybe status bits can leak between MOBs? 
3. **Could cause confusion**: Clearing TX bits in wrong context might interfere with actual TX operations

## Proposed Fix

### Option 1: Remove TX handling entirely from RX MOB
```c
if( CANMOB_RX_IDX == u8MOBIndex )
{
    // RX success?
    if( CANSTMOB & (1 << RXOK) )
    {
        // Clear it
        CANSTMOB &= ~(1 << RXOK);
        // ... rest of RX handling
```

### Option 2: Add assertion/debug to understand why this happens
```c
if( CANMOB_RX_IDX == u8MOBIndex )
{
    // This should NEVER happen - RX MOB shouldn't see TX status
    if( CANSTMOB & (1 << TXOK) )
    {
        // Log error or increment error counter
        sg_u32UnexpectedTxInRx++;  // Debug counter
        // Clear it to prevent stuck interrupt
        CANSTMOB &= ~(1 << TXOK);
    }
```

## Recommendation
Go with **Option 1** - completely remove TX handling from RX MOB context. TX status should only be handled in TX MOB handler.

## Risk Assessment
- **Low risk**: TX handling belongs in TX MOB only
- **Possible side effect**: If there's a hardware quirk causing TX bits to appear in RX MOB, not clearing them might cause stuck interrupts
- **Mitigation**: Monitor for any interrupt lockups after change

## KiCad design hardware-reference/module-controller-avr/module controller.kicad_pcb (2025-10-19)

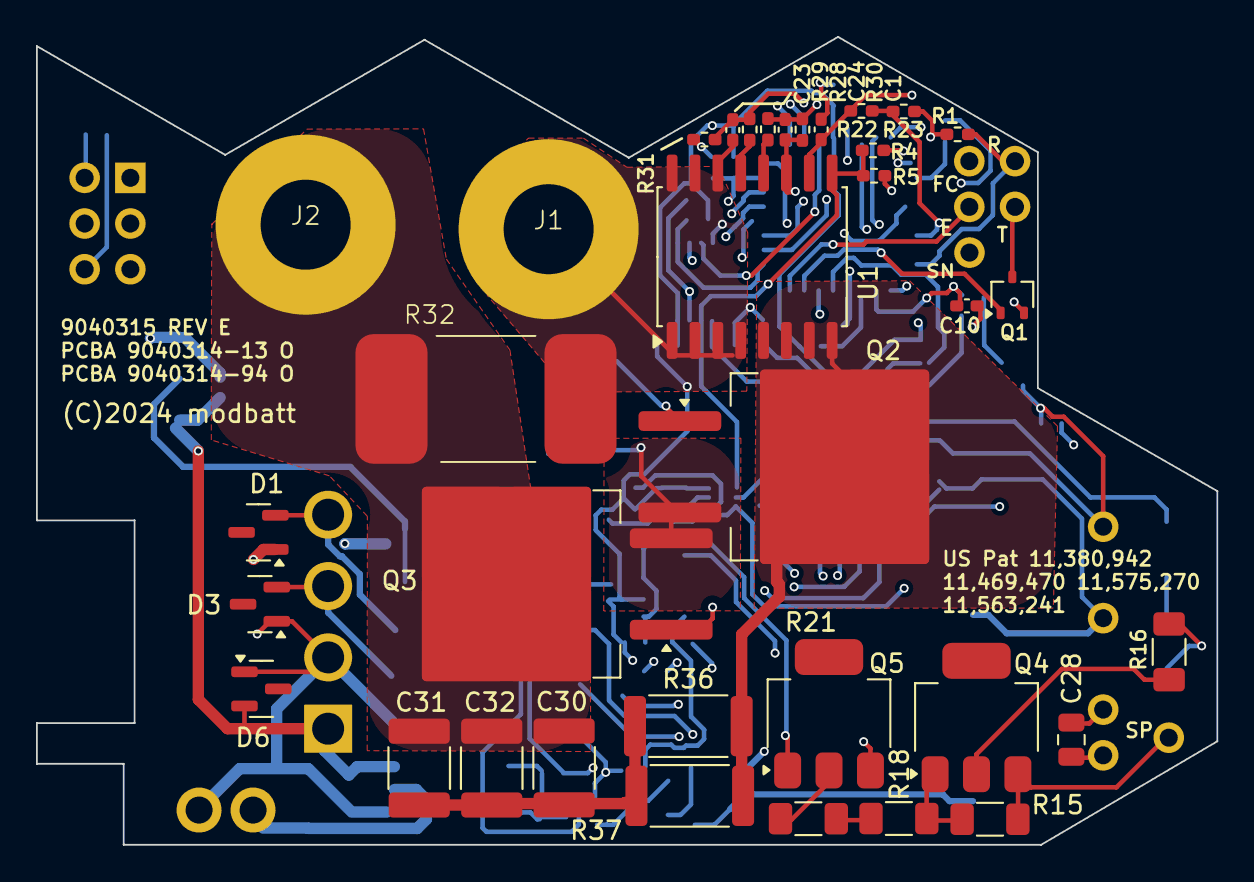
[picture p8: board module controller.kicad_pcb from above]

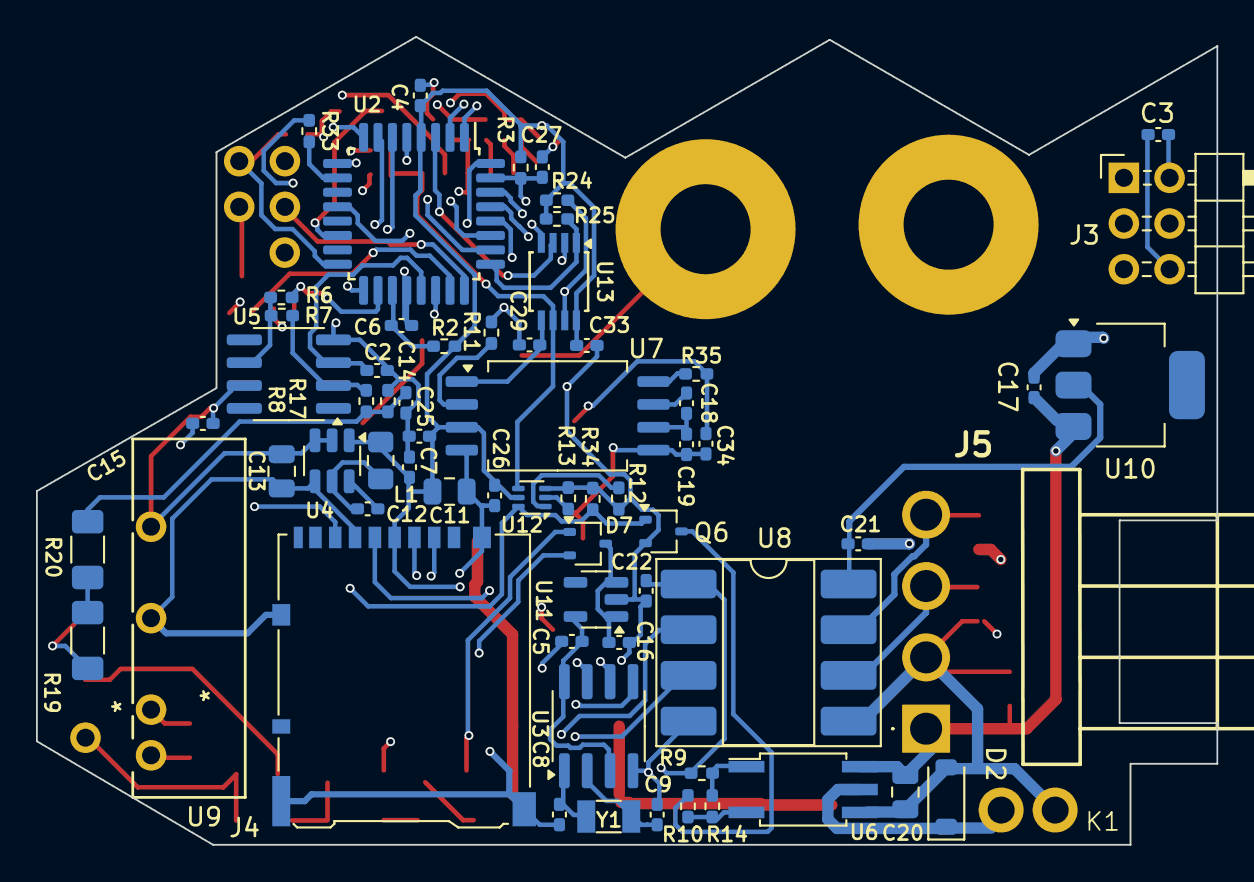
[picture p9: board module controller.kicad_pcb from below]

Board: 4 copper layers, 65.6 x 44.9 mm, 107 parts (65 on the bottom side), 73 nets.

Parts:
C1: 2.2uF; C_0402_1005Metric_Pad0.74x0.62mm_HandSolder
C2: 10nF; C_0402_1005Metric_Pad0.74x0.62mm_HandSolder
C3, C4, C5, C6, C7, C12, C15, C25, C26, C27, C29, C33: .1uF; C_0402_1005Metric_Pad0.74x0.62mm_HandSolder
C8, C9: 7pF; C_0402_1005Metric_Pad0.74x0.62mm_HandSolder
C10, C14, C23, C24, C34: 10pF; C_0402_1005Metric_Pad0.74x0.62mm_HandSolder
C11, C13, C20, C28: 22uF 25V; C_0805_2012Metric
C16, C18, C19: 1uF; C_0402_1005Metric_Pad0.74x0.62mm_HandSolder
C17, C21, C22: .1uF 50V; C_0402_1005Metric_Pad0.74x0.62mm_HandSolder
C30, C31, C32: .1uF 1KV; C_1812_4532Metric
D1, D3, D6: MMBZ27VCLT1G; SOT-23
D2: 20V 350mA SOD123; D_SOD-123
D7: BAT54CW; SOT-323_SC-70
J1, J2: TERM; TERMINAL
J3: Debug; PinHeader_2x03_P2.54mm_Horizontal
J4: Micro_SD_Card_Det_Hirose_DM3AT; microSD_HC_Hirose_DM3AT-SF-PEJM5
J5: 640389-4; 6403896-4
J6, J7, J8, J9, J10, J11: Conn_01x01_Pin; PinHeader_1x01_P1.00mm_Horizontal
K1: DVR05; modbatt relay tab
L1: 4.7uH; L_0805_2012Metric_Pad1.15x1.40mm_HandSolder
Q1, Q6: 2N7002; SOT-323_SC-70
Q2, Q3: IPB60R040CFD7ATMA1; TO-263-3_TabPin2
Q4: ZVP0545G; SOT-223
Q5: ZVN0545G; SOT-223
R1: 1K; R_0402_1005Metric_Pad0.72x0.64mm_HandSolder
R2: 4.7 OHM; R_0402_1005Metric_Pad0.72x0.64mm_HandSolder
R3, R4, R24, R25, R33: 4.7K; R_0402_1005Metric_Pad0.72x0.64mm_HandSolder
R5, R22, R23, R34: 100K; R_0402_1005Metric_Pad0.72x0.64mm_HandSolder
R6: 10K; R_0402_1005Metric_Pad0.72x0.64mm_HandSolder
R7, R8: 1.0M 0.1%; R_0402_1005Metric_Pad0.72x0.64mm_HandSolder
R9, R10: 68; R_0402_1005Metric_Pad0.72x0.64mm_HandSolder
R11: 200K; R_0402_1005Metric_Pad0.72x0.64mm_HandSolder
R12, R13: 787K 1%; R_0402_1005Metric_Pad0.72x0.64mm_HandSolder
R14, R28, R29, R30, R31: 4.99K 0.1%; R_0402_1005Metric_Pad0.72x0.64mm_HandSolder
R15: 200K 1206; R_1206_3216Metric_Pad1.30x1.75mm_HandSolder
R16, R19, R20: 2.7M 0.1% 1206; R_1206_3216Metric_Pad1.30x1.75mm_HandSolder
R17: 100K 0.1%; R_0402_1005Metric_Pad0.72x0.64mm_HandSolder
R18, R21: 2.7M; R_1206_3216Metric_Pad1.30x1.75mm_HandSolder
R32: 33K 3560 6W; 3560
R35: 22; R_0402_1005Metric_Pad0.72x0.64mm_HandSolder
R36, R37: 4R0 500V; R_2512_6332Metric
U1: ACS37002LMABTR-050B5; SOIC-16W_7.5x10.3mm_P1.27mm
U2: ATmega64M1-AU; TQFP-32_7x7mm_P0.8mm
U3: MCP7940N-xMS; SOIC-8_3.9x4.9mm_P1.27mm
U4: AP63203WU; TSOT-23-6
U5: TLV333 8SOIC; SOIC-8_3.9x4.9mm_P1.27mm
U6: TLP152; SO-6_4.4x3.6mm_P1.27mm
U7: TPSI3050D; SOIC-8_7.5x5.85mm_P1.27mm
U8: ISO1050DUB; DIP-8_W8.89mm_SMDSocket_LongPads
U9: IB1205LS-1WR3; SIP6_IB_LS-1WR3_MNS
U10: AZ1117-5.0; SOT-223
U11: MIC5504-3.3YM5; SOT-23-5
U12: TMP392; SOT-563
U13: TC7WH74FU; TSSOP-8_3x3mm_P0.65mm
Y1: 32.768KHz SC-32; Crystal_SMD_3215-2Pin_3.2x1.5mm

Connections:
/12V+: C17.1, C20.1, C28.1, D6.2 (K), J5.1, U6.6 (VCC), U9.1 (VIN), U10.3 (VI)
/12V-: C17.2, C20.2, C21.2, C28.2, D1.1 (K), D2.2 (A), D3.1 (K), D6.1 (K), J5.2, K1.3, U6.4 (VEE), U8.5 (GND2), U9.2 (GND), U10.1 (GND)
/CAN H: D1.2 (K), J5.4, U8.7 (CANH)
/CAN L: D3.2 (K), J5.3, U8.6 (CANL)
/CELL EN: J6.1, U2.24 (PB4)
/CSOUT: Q2.2 (D), R36.2, R37.2, U1.5 (IP-), U1.6 (IP-), U1.7 (IP-), U1.8 (IP-)
/FIRST CELL: D7.2, J11.1
/HV PWR/5V: C1.1, C13.1, C15.1, D7.1, Q5.1 (G), R22.1, U1.10 (VCC), U4.2 (EN), U4.3 (IN), U5.7 (V+), U9.6 (+VO)
/HV PWR/ADC REF 2.56V: C2.1, U2.21 (AREF/ISRC), U5.3 (+)
/HV PWR/CAN RXD: U2.7 (RXCAN/PC3), U8.2 (RXD)
/HV PWR/CAN TXD: U2.6 (TXCAN/PC2), U8.3 (TXD)
/HV PWR/DIVIDER: C14.1, R8.2, R17.2, R20.1
/HV PWR/FET EN: C29.1, U7.1 (EN), U13.5 (Q)
/HV PWR/FET G: C34.1, Q2.1 (G), Q3.1 (G), R35.2
/HV PWR/FET S: C19.2, C34.2, Q2.3 (S), Q3.3 (S), U7.5 (VSSS)
/HV PWR/MC PWR: C3.1, C4.1, C7.1, C11.1, C22.1, C25.2, C26.1, C33.1, J3.2, J4.4 (VDD), L1.1, R2.1, R3.1, R9.2, R24.1, R25.1, U2.4 (VCC), U4.1 (FB), U7.3 (VDDP), U8.1 (VCC1), U12.5 (VDD), U13.8 (VCC)
/HV PWR/RELAY EN: R33.1, U2.10 (PWM/XTAL1/PE1)
/HV PWR/RELAY POS: D2.1 (K), K1.2, U6.5 (VO)
/HV PWR/STRING V SENSE: C10.1, R6.1, U2.18 (ADC9/PC5)
/HV PWR/~OCF: R4.2, R5.1, U1.9 (-OCF), U12.4 (OUTB), U13.6 (~CLR)
/MC RX: J7.1, R1.1, U2.16 (INT1/ADC5/PB2)
/MC TX: J8.1, Q1.3 (D)
/MODULE CONTROLLER/5V DET: R22.2, R23.1, U2.14 (INT0/ADC3/PD6)
/MODULE CONTROLLER/CURRENT ADC0: R28.2, U1.12 (VIOUT)
/MODULE CONTROLLER/CURRENT ADC1: R29.2, U1.13 (VREF)
/MODULE CONTROLLER/MC TX: Q1.1 (G), U2.23 (PB3)
/MODULE CONTROLLER/NV VCC: C5.1, U3.3 (VBAT), U3.8 (VCC), U11.5 (VOUT)
/TERM NEG: C30.2, C31.2, C32.2, J2.1, Q3.2 (D), R32.1
unnamed: C30.1, C31.1, C32.1, R36.1, R37.1
unnamed: J3.1, U2.1 (MISO_A/PD2)
unnamed: J3.3, U2.12 (ADC1/RXD/SCK_A/PD4)
unnamed: J3.4, U2.2 (TXD/MOSI_A/PD3)
unnamed: C27.1, J3.5, R3.2, U2.31 (~RESET/PE0)
unnamed: J4.5 (CLK), U2.28 (SCK/ADC4/PB7)
unnamed: J4.3 (CMD), U2.9 (PB1)
unnamed: J4.7 (DAT0), U2.8 (PB0)
unnamed: J4.2 (DAT3/CD), U2.22 (ADC10/PC6)
unnamed: Q4.2 (D), R16.2
unnamed: Q4.1 (G), R15.2, R18.1
unnamed: Q5.2 (D), R21.2
unnamed: Q6.3 (D), R10.1
unnamed: Q6.1 (G), R33.2, R34.1, U12.6 (OUTA)
unnamed: R6.2, R7.1, U5.6
unnamed: R16.1, R19.2
unnamed: R18.2, R21.1
unnamed: R19.1, R20.2
unnamed: C23.1, R29.1, R31.2, U2.27 (ADC7/PB6)
unnamed: R4.1, U2.17 (ADC8/PC4)
unnamed: C6.1, R2.2, U2.19 (AVCC)
unnamed: C24.1, R28.1, R30.2, U2.26 (INT2/ADC6/PB5)
unnamed: U2.30 (INT3/PC0), U3.7 (MFP)
unnamed: U2.29 (PD0), U3.6 (SCL)
unnamed: U2.32 (PD1), U3.5 (SDA)
unnamed: C8.2, U3.1 (X1), Y1.2
unnamed: C9.2, U3.2 (X2), Y1.1
unnamed: C12.1, U4.6 (BST)
unnamed: C12.2, L1.2, U4.5 (SW)
unnamed: R7.2, R8.1, U5.2 (-)
unnamed: R9.1, R14.1, U6.1 (A)
unnamed: R10.2, R14.2, U6.3 (C)
unnamed: R11.2, U7.2 (PXFR)
unnamed: C18.1, U7.7 (VDDH)
unnamed: C18.2, C19.1, U7.6 (VDDM)
unnamed: R35.1, U7.8 (VDRV)
unnamed: C21.1, U8.8 (VCC2), U10.2 (VO)
unnamed: C16.1, D7.3, U11.1 (VIN), U11.3 (EN)
unnamed: R12.2, U12.1 (SETA)
unnamed: R13.2, U12.2 (SETB)
unnamed: R25.2, U2.25 (PC7), U13.1 (C)
unnamed: R24.2, U13.2 (D), U13.7 (~PR)
unnamed: U2.3 (PC1), U13.3 (~Q)
STRING NEG: C1.2, C2.2, C3.2, C4.2, C5.2, C6.2, C7.2, C8.1, C9.1, C10.2, C11.2, C13.2, C14.2, C15.2, C16.2, C22.2, C23.2, C24.2, C25.1, C26.2, C27.2, C29.2, C33.2, J1.1, J3.6, J4.6 (VSS), J4.11 (SHIELD), J10.1, Q1.2 (S), Q5.3 (S), Q6.2 (S), R1.2, R5.2, R11.1, R12.1, R13.1, R17.1, R23.2, R30.1, R31.1, R32.2, R34.2, U1.1 (IP+), U1.2 (IP+), U1.3 (IP+), U1.4 (IP+), U1.11 (VOC), U1.14 (GS1), U1.15 (GND), U1.16 (GS0), U2.5 (GND), U2.20 (AGND), U3.4 (VSS), U4.4 (GND), U5.4 (V-), U7.4 (VSSP), U8.4 (GND1), U9.4 (0V), U11.2 (GND), U12.3 (GND), U13.4 (GND)
STRING POS: J9.1, Q4.3 (S), R15.1

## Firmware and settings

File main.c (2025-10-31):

/* ModuleCPU
 *
 * Module controller firmware - main module
 *
 * (C) Copyright 2023-2024 Modular Battery Technologies, Inc.
 * US Patents 11,380,942; 11,469,470; 11,575,270; others. All
 * rights reserved
 */

// Define to use fake cell data for testing MODULE_DETAIL responses
//#define FAKE_CELL_DATA

#include <stdint.h>
#include <xc.h>
#include <stdbool.h>
#include <string.h>
#include <avr/io.h>
#include <avr/interrupt.h>
#include <avr/sleep.h>
#include <avr/wdt.h>
#include "main.h"
#include "../Shared/Shared.h"
//#include "FatFS/source/ff.h"
#include "vUART.h"
#include "debugSerial.h"
#include "rtc_mcp7940n.h"
#include "can.h"
#include "STORE.h"
//#include "storage.h"
//#include "File.h"
#include "EEPROM.h"
#include "FRAMECOUNTER.h"
#include "SD.h"
#include "crc32.h"

// watchdog stuff
// Uncomment to enable watchdog timer
//#define WDT_ENABLE
#define WDT_LEASH_LONG WDTO_2S  // used in normal operation, should be at least 1S
#define WDT_LEASH_SHORT WDTO_15MS  // used for high risk ops like switching relays, which often causes journey into the weeds

typedef enum {
EWDT_NORMAL,
EWDT_MECH_RLY_ON,
EWDT_MECH_RLY_OFF,
EWDT_FET_ON,
EWDT_FET_OFF,
} eWDTstatus;

static volatile eWDTstatus __attribute__((section(".noinit"))) sg_eWDTCurrentStatus;  // used to track if we're using WDT to recover from a relay switch glitch, .noinit to survive post-reset init


// Sets the default state of the module
#define STATE_DEFAULT				EMODSTATE_OFF
#define REPORT_MOST_AND_FEWEST_CELLS 1

// Uncomment to automatically cycle through all the power states
//#define	STATE_CYCLE								// if REQUEST_CELL_BALANCE_ENABLE is defined, will test discharge in OFF and STDBY
#define	STATE_CYCLE_INTERVAL		1			// How often do we switch state? (in seconds)

// Request ALL cell detail
#define CELL_DETAIL_ALL						0xff

// Uncomment to cause cell CPUs to return fixed patterns (communication test)
// #define REQUEST_DEBUG_CELL_RESPONSE		5

// Uncomment to enable cell balance requests
//#define REQUEST_CELL_BALANCE_ENABLE
#define CELL_BALANCE_DISCHARGE_THRESHOLD 0x0387  // lowest target voltage for balancing, 0x387 is 3.9V
#define BALANCE_VOLTAGE_THRESHOLD 0x40   // difference between highest and lowest cell that triggers balancing

// Indication of temperature reading being invalid
#define TEMPERATURE_INVALID					0xffff

#define FW_BUILD_NUMBER						(8278)

#define MANUFACTURE_ID						(0x02)
#define PART_ID								(0x03)

// 16 Bit hardware compatibility value for module hardware compatibility command
#define HARDWARE_COMPATIBILITY				0x0000

// Number of consecutive partial string reports to tolerate before power cycling string
#define SEQUENTIAL_COUNT_MISMATCH_THRESHOLD	5

// Value returned when cell temperature is invalid
#define CELL_TEMPERATURE_INVALID			0x7fff

// # Of valid data bits for cell voltage
#define CELL_VOLTAGE_BITS		10			// # Of valid bits in the cell voltage
#define CELL_DIV_TOP			90900		// Resistance of cell plus->voltage resistor on cell CPU
#define CELL_DIV_BOTTOM			30100		// Resistance of ground->voltage resistor on cell CPU
#define CELL_VOLTAGE_SCALE		(((float) CELL_DIV_BOTTOM) / ((float) CELL_DIV_TOP + (float) CELL_DIV_BOTTOM))

#define CELL_VOLTAGE_CAL 1.032 //measured calibration factor

#define FIXED_POINT_SCALE 512  // 2^9, gives us 9 bits of fractional precision  (10 bits overflows)

// Default unique ID for unprogrammed EEPROM
#define EEPROM_UNPROGRAMMED_DEFAULT_UID		0xBA77BABE

// Pre-calculate these constants:
#define VOLTAGE_CONVERSION_FACTOR ((uint32_t)((CELL_VREF * 1000.0 / CELL_VOLTAGE_SCALE * CELL_VOLTAGE_CAL * FIXED_POINT_SCALE) + 0.5))
#define ADC_MAX_VALUE (1 << CELL_VOLTAGE_BITS)

#define ADC_CURRENT_BUFFER_SIZE 8

static int16_t sg_sCurrenBuffer [ADC_CURRENT_BUFFER_SIZE];
static uint8_t sg_u8CurrentBufferIndex;

// Cell VREF
#define CELL_VREF				1.1

// Cell string "off to on" time in milliseconds
#define	CELL_POWER_OFF_TO_ON_MS			100

// Cell string power "on to first message" time in milliseconds
#define	CELL_POWER_ON_TO_FIRST_MSG_MS	5

// Charge current defaults when EEPROM not programmed
#define		MAX_DISCHARGE_AMPS			-42
#define		MAX_CHARGE_AMPS				10

// *****
// FAKE DATA ENABLES
//
// Uncomment to enable and set appropriate values

// Uncomment to inject fake cell data
// #define FAKE_CELL_DATA				1

// Prescaler value of 0: (8Mhz internal osc / 1= 8Mhz)
#define SYSCLOCK_PRESCALE					0

// Converts the prescaler 0 value into CS1[2:0] bits
#if 1==TIMER_PRESCALER0
#define TIMER_PRESCALER_CS0		(1 << CS00)
#elif 8==TIMER_PRESCALER0
#define TIMER_PRESCALER_CS0		(1 << CS01)
#elif 64==TIMER_PRESCALER0
#define TIMER_PRESCALER_CS0		((1 << CS01) | (1 << CS00))
#elif 256==TIMER_PRESCALER0
#define TIMER_PRESCALER_CS0		(1 << CS02)
#elif 1024==TIMER_PRESCALER0
#define TIMER_PRESCALER_CS0		((1 << CS02) | (1 << CS00))
#else
#error "Unknown timer prescaler 0 value - needs to be 1, 8, 64, 256, or 1024"
#endif

// Converts the prescaler 1 value into CS1[2:0] bits
#if 1==TIMER_PRESCALER1
#define TIMER_PRESCALER_CS1		(1 << CS10)
#elif 8==TIMER_PRESCALER1
#define TIMER_PRESCALER_CS1		(1 << CS11)
#elif 64==TIMER_PRESCALER1
#define TIMER_PRESCALER_CS1		((1 << CS11) | (1 << CS10))
#elif 256==TIMER_PRESCALER1
#define TIMER_PRESCALER_CS1		(1 << CS12)
#elif 1024==TIMER_PRESCALER1
#define TIMER_PRESCALER_CS1		((1 << CS12) | (1 << CS10))
#else
#error "Unknown timer prescaler 1 value - needs to be 1, 8, 64, 256, or 1024"
#endif

// Clear current interrupt flag, set the next compare, and enable the interrupt
#define TIMER1_CHA_INT(x)					TIFR1 = (1 << OCF1A); OCR1A = (uint16_t) (TCNT1 + (x)); TIMSK1 |= (1 << OCIE1A)

#define PIN_RELAY_EN						(PORTE1)  //moved from c0!
#define PIN_OCF_N							(PORTC1)  // when FET is on configure as input to monitor OCF, value is inverted starting 
#define PIN_FET_EN							(PORTC4)  // set high to enable clocking of FET, set low to asynchronously disable FET
#define PIN_FET_CK							(PORTC7)  // cycle low then high (no delay needed) to clock FET to ON.  if FET_EN is low this will have no effect.

// 5V Detect port definitions
#define PORT_5V_DET							PORTD
#define DDR_5V_DET							DDRD
#define PIN_5V_DET							(PORTD6)
#define IMASK_5V_DET						PCMSK2
#define PCINT_5V_DET						PCINT22
#define PCIFR_5V_DET						PCIF2

#define PIN_CELL_POWER						(PORTB4)
#define DDR_CELL_POWER						DDRB
#define PORT_CELL_POWER						PORTB

#define RELAY_EN_CONFIGURE()				DDRE |= ((uint8_t) (1 << PIN_RELAY_EN))   //moved from c0!
#define RELAY_EN_ASSERT()					PORTE |= ((uint8_t) (1 << PIN_RELAY_EN))   //moved from c0!
#define RELAY_EN_DEASSERT()					PORTE &= ((uint8_t) ~(1 << PIN_RELAY_EN))   //moved from c0!
#define RELAY_ASSERTED()					(PINE & ((uint8_t) (1 << PIN_RELAY_EN)))

// prior to rev E.  
//#define FET_EN_CONFIGURE()					PORTC &= ~  (((uint8_t) (1 << PIN_FET_EN)) | ((uint8_t) (1 << PIN_OCF_N))); DDRC |= (((uint8_t) (1 << PIN_FET_EN)) | ((uint8_t) (1 << PIN_OCF_N)) ); // set both as outputs and OFF
//#define FET_EN_ASSERT()						DDRC &= ~ ((uint8_t) (1 << PIN_OCF_N));  PORTC |= ((uint8_t) (1 << PIN_FET_EN));  // set to read OCF and drive FET_EN
//#define FET_EN_DEASSERT()					PORTC &= ~  (((uint8_t) (1 << PIN_FET_EN)) | ((uint8_t) (1 << PIN_OCF_N))); DDRC |= (((uint8_t) (1 << PIN_FET_EN)) | ((uint8_t) (1 << PIN_OCF_N)) ); // set both as outputs and OFF
//#define FET_ASSERTED()						(PINC & ((uint8_t) (1 << PIN_FET_EN)))

// starting with rev E
// initial configuration  PC4 low (external pulldown), PC7 high (it is also pulled up externally), PC1 input
// to enable FET to be turned on set PC4 high.  this removes the asynchronous /CLR from the flipflop.  note that an over temp or over current condition will override this
// to turn FET on once it is enabled, cycle the clock by driving PC7 low then high.  no need for delay inbetween.
// to turn FET off when it's on, drive PC4 low.  this will asynchronously clear the flipflop
// read the status of FET EN on PC1 (inverted!)
// an overtemp or overcurrent will drive /CLR and cause PC1 to go high, so a rising edge interrupt can be used to detect these events

#define FET_EN_CONFIGURE()					PORTC &= ~  ((uint8_t) (1 << PIN_FET_EN)); DDRC |= ((uint8_t) (1 << PIN_FET_EN)); DDRC &= ~ ((uint8_t) (1 << PIN_OCF_N)); DDRC |= ((uint8_t) (1 << PIN_FET_CK)) // set FET_EN as output and low, OCF_N as input, FET_CK as output
#define FET_EN_ASSERT()						PORTC |= ((uint8_t) (1 << PIN_FET_EN)); PORTC &= ~ ((uint8_t) (1 << PIN_FET_CK)); PORTC |= ((uint8_t) (1 << PIN_FET_CK))  // set  FET_EN high, then drive flipflop clock low then high
#define FET_EN_DEASSERT()					PORTC &= ~  ((uint8_t) (1 << PIN_FET_EN)) // asynchronously clear the flipflop
#define FET_ASSERTED()						~(PINC & ((uint8_t) (1 << PIN_OCF_N)))  // pin is inverted

#define CELL_POWER_ASSERT()					PORT_CELL_POWER |= ((uint8_t) (1 << PIN_CELL_POWER))
#define CELL_POWER_DEASSERT()				PORT_CELL_POWER &= ((uint8_t) ~(1 << PIN_CELL_POWER))


// the following variables need to survive WDT reset. initialize in regular reset init but not on wdt
//---------------------------------------------------------------------------------------------------
static uint8_t __attribute__((section(".noinit"))) sg_u8ModuleRegistrationID;
// State of charge and health
volatile static uint8_t __attribute__((section(".noinit"))) sg_u8SOC;
volatile static uint8_t __attribute__((section(".noinit"))) sg_u8SOH;
volatile static uint8_t __attribute__((section(".noinit"))) sg_u8CellStatusTarget;
volatile static uint8_t __attribute__((section(".noinit"))) sg_u8CellStatus;


volatile static bool __attribute__((section(".noinit"))) sg_bSendAnnouncement;			// true If we're sending a module announcement to the pack controller
volatile static bool __attribute__((section(".noinit"))) sg_bModuleRegistered;			// true If we've received a registration ID from the pack controller
volatile static bool __attribute__((section(".noinit"))) sg_bEEPROMValid;				// true If EEPROM is programmed (unique ID != 0xFFFFFFFF)
volatile static bool sg_bAnnouncementPending = false;	// true if we need to send announcement after delay
volatile static uint8_t sg_u8AnnouncementDelayTicks = 0;	// ticks remaining before sending announcement

volatile static bool __attribute__((section(".noinit"))) sg_bSendTimeRequest;			// true If we want to send a "set time" command to the pack controller
volatile static bool __attribute__((section(".noinit"))) sg_bPackControllerTimeout;		// true If we've not heard from a pack controller in PACK_CONTROLLER_TIMEOUT_MS

// Cached unique ID to avoid repeated EEPROM reads during message formation
// Module unique ID now stored directly in sg_sFrame.m.moduleUniqueId

volatile static bool __attribute__((section(".noinit"))) sg_bSendModuleControllerStatus;
volatile static bool __attribute__((section(".noinit"))) sg_bSendCellStatus;
volatile static bool __attribute__((section(".noinit"))) sg_bSendHardwareDetail;
volatile static bool __attribute__((section(".noinit"))) sg_bSendCellCommStatus;
static bool sg_bIgnoreStatusRequests = false;  // Ignore new requests while sending
volatile static bool __attribute__((section(".noinit"))) sg_bCellBalanceReady;
volatile static bool __attribute__((section(".noinit"))) sg_bCellBalancedOnce;
volatile static bool __attribute__((section(".noinit"))) sg_bStopDischarge;
static volatile bool __attribute__((section(".noinit"))) sg_bOvercurrentSignal;
static volatile bool __attribute__((section(".noinit"))) sg_bADCUpdate;
static volatile uint16_t __attribute__((section(".noinit"))) sg_u16LowCellVoltageRAW; //  used for setting balance discharge target

volatile static FrameData __attribute__((section(".noinit"))) sg_sFrame;  //current frame data to be written to SD card
volatile static EFrameType __attribute__((section(".noinit"))) sg_eFrameStatus;  // alternating between EFRAMETYPE_READ, EFRAMETYPE_WRITE, at PERIODIC_CALLBACK_RATE_MS - we read a frame, then we write/send it
volatile static bool __attribute__((section(".noinit"))) sg_bNewTick;  // set tru in periodic tick isr, cleared in main loop

// # Of sequential cell count expected vs. received messages.
// Removed sg_u8SequentailCountMismatchThreshold - now using SEQUENTIAL_COUNT_MISMATCH_THRESHOLD #define

// Incremented each time there's a cell count mismatch from what we get vs. what
// we expect
volatile static uint8_t __attribute__((section(".noinit"))) sg_u8SequentailCellCountMismatches;

// Status
// 0=Charge prohibited/discharge prohibited (always the case in any state by ON)
// 1=Charge allowed/discharge prohibited
// 2=Charge allowed/discharge allowed
// 3=Charge prohibited/discharge allowed

// SD card status

static volatile bool __attribute__((section(".noinit"))) sg_bSDCardReady;
static volatile bool __attribute__((section(".noinit"))) sg_bSDWriteEnabled;  // Flag to control SD writes based on state
static volatile bool __attribute__((section(".noinit"))) sg_bSDBusy;  // Flag indicating SD card is currently being accessed (survives WDT reset for stuck SPI detection)

// Frame transfer state machine
typedef enum
{
	FRAME_TRANSFER_IDLE,
	FRAME_TRANSFER_SENDING_START,
	FRAME_TRANSFER_SENDING_DATA,
	FRAME_TRANSFER_SENDING_END,
} FrameTransferState;

static FrameTransferState sg_eFrameTransferState = FRAME_TRANSFER_IDLE;
static uint8_t sg_u8FrameTransferSegment = 0;  // Current segment being sent (0-127)
static volatile FrameData* sg_pFrameToTransfer = NULL;  // Pointer to frame being transferred

typedef enum
{
	EMODESTATUS_CHARGE_PROHIBITED_DISCHARGE_PROHIBITED=0,
	EMODESTATUS_CHARGE_ALLOWED_DISCHARGE_PROHIBITED=1,
	EMODESTATUS_CHARGE_ALLOWED_DISCHARGE_ALLOWED=2,
	EMODESTATUS_CHARGE_PROHIBITED_DISCHARGE_ALLOWED=3
} EModuleControllerStatus;



// Module controller's status, for later expansion
static EModuleControllerStatus sg_eModuleControllerStatus = EMODESTATUS_CHARGE_PROHIBITED_DISCHARGE_PROHIBITED;

#ifdef STATE_CYCLE
volatile static uint8_t __attribute__((section(".noinit"))) sg_u8StateCounter;
volatile static EModuleControllerState __attribute__((section(".noinit"))) sg_eStateCycle;
#endif

volatile static EModuleControllerState __attribute__((section(".noinit")))sg_eModuleControllerStateCurrent;
volatile static EModuleControllerState __attribute__((section(".noinit")))sg_eModuleControllerStateTarget;
volatile static EModuleControllerState __attribute__((section(".noinit")))sg_eModuleControllerStateMax;

// Counter incremented every time the periodic timer fires (once every PERIODIC_INTERUPT_RATE_MS ms)
static volatile uint8_t sg_u8CellFrameTimer;
static volatile bool sg_bFrameStart;
static volatile uint8_t sg_u8CellStringPowerTimer;
static volatile uint8_t sg_u8TicksSinceLastPackControllerMessage;
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
int main(void)
{
	
	// Always disable the watchdog on startup for safety (see datasheet)
	WatchdogOff();
	// Stop all interrupts
	cli();
	
	// Enable FET and Relay enable outputs
	FET_EN_CONFIGURE();  // DO THE FET FIRST
	FET_EN_DEASSERT();   // MAKE SURE IT'S OFF
	
	RELAY_EN_CONFIGURE();
	RELAY_EN_DEASSERT();

	// Set cell power port/pin as an output
	DDR_CELL_POWER |= (1 << PIN_CELL_POWER);	
	
	// Turn off the cell chain
	CELL_POWER_DEASSERT();
		
	sg_u8Reason = MCUSR;
	if ((1 << WDRF) & sg_u8Reason)
	{
		// Watchdog reset, most likely caused by power/reset glitch when switching relays
		// determine what we were doing and tweak as needed
		switch (sg_eWDTCurrentStatus)  // it is in .noinit so should survive the reset
		{		
			case EWDT_NORMAL:
			{
				// shoould not occur, but if it did try to continue like nothing happened
			}
			case EWDT_MECH_RLY_ON:
			{
				// we were switching mech relay on
			}
			case EWDT_MECH_RLY_OFF:
			{
				// we were switching mech relay off
			}
			case EWDT_FET_ON:
			{
				// we were switching fet on, add overcurrent handling here  *dp
			}
			case EWDT_FET_OFF:
			{
				// we were switching fet off
			}
		}
		sg_sFrame.m.sg_u8WDTCount++;
		WDTSetLeash(WDT_LEASH_LONG, EWDT_NORMAL);  // set on long leash
		ModuleControllerStateHandle();  // finish what we were doing
	}
	else
	{
		// all other reset types, do normal init		
		if ((1 << BORF) & sg_u8Reason)
		{
			// Brown out reset
		}
		if ((1 << EXTRF) & sg_u8Reason)
		{
			// External reset
		}
		if ((1 << PORF) & sg_u8Reason)
		{
			// Power on reset
		}
		// Set the sysclock to 8 MHz
		// *dp some of these may also need to be done on WDT
		SetSysclock();
		TimerInit();
		vUARTInit();
		ADCInit();

#ifndef STATE_CYCLE		// don't attempt SD when cycling
		sg_bSDCardReady = STORE_Init();
		sg_bSDWriteEnabled = false;  // Start with SD writes disabled (module starts in OFF state)
		sg_bSDBusy = false;  // Initialize SD busy flag (can be set if WDT reset during SD operation)
#else
		sg_bSDCardReady = false;
		sg_bSDWriteEnabled = false;
		sg_bSDBusy = false;
		sg_eStateCycle = EMODSTATE_OFF;
		sg_u8StateCounter = 0;
#endif
	
		// Set how many cells we're expecting	
	
		FrameInit(true);  // true for full init
		
	
		// And how many sequential incorrect cell count until we reset the
		// chain?
		// Removed EEPROM read - now using SEQUENTIAL_COUNT_MISMATCH_THRESHOLD #define

		// Cache the unique ID from EEPROM to avoid repeated reads during message formation

		// Set 5V DET as input
		DDR_5V_DET &= (uint8_t) ~(1 << PIN_5V_DET);
		// And PIN_5V_DET pullup
		PORT_5V_DET |= (1 << PIN_5V_DET);

		// Ensure SPI is routed to Port B (not Port D) - clear SPIPS bit
		// This prevents SPI peripheral from interfering with PD2/PD3/PD4
		MCUCR &= (uint8_t) ~(1 << SPIPS);

		// Enable pullups on debug/SPI pins (PD2=MISO, PD3=MOSI, PD4=SCK in alternate mode)
		// Prevents floating inputs from triggering spurious interrupts when debug cable disconnected
		DDRD &= (uint8_t) ~((1 << PORTD2) | (1 << PORTD3) | (1 << PORTD4));  // Ensure inputs
		PORTD |= (1 << PORTD2) | (1 << PORTD3) | (1 << PORTD4);  // Enable pullups

		// Clear pin change interrupt flag by writing a one
		PCIFR = (1 << PCIF0);			// Bank A flag
		PCIFR = (1 << PCIF1);			// Bank B flag
		PCIFR = (1 << PCIF2);			// Bank C flag
		PCIFR = (1 << PCIF3);			// Bank D flag

		// Enable 5V loss interrupt
		IMASK_5V_DET |= (1 << PCINT_5V_DET);
	
		// Pin change interrupt - enable it
		PCIFR |= (1 << PCIFR_5V_DET);
	
		// Set the CAN bus receive callback and init it
		CANSetRXCallback(CANReceiveCallback);
		CANInit();
		// init the _noinit_ section variables
		sg_u8ModuleRegistrationID = 0;
		sg_bModuleRegistered = false;
		sg_bIgnoreStatusRequests = false;  // Reset all status flags
		ModuleControllerStateSet( EMODSTATE_OFF );  // turn off when deregistered

		// Check if EEPROM is programmed (unique ID != 0xFFFFFFFF)
		uint32_t u32UniqueID = ModuleControllerGetUniqueID();
		if (u32UniqueID == EEPROM_UNPROGRAMMED_DEFAULT_UID)
		{
			// EEPROM is unprogrammed - use defaults for testing
			sg_bEEPROMValid = false;
		}
		else
		{
			// EEPROM is programmed - normal operation
			sg_bEEPROMValid = true;
		}

		// Initialize critical status and safety flags
		sg_bSendAnnouncement = true;  // Should announce on startup
		sg_bPackControllerTimeout = false;
		sg_bSendModuleControllerStatus = false;
		sg_bSendCellStatus = false;
		sg_bSendHardwareDetail = false;
		sg_bSendCellCommStatus = false;
		sg_bCellBalanceReady = false;
		sg_bCellBalancedOnce = false;
		sg_bStopDischarge = false;
		sg_bOvercurrentSignal = false;
		sg_u8CellStatusTarget = 0;
		sg_u8CellStatus = 0;
		sg_u8SOC = 0;
		sg_u8SOH = 0;
		// Removed initialization - now using SEQUENTIAL_COUNT_MISMATCH_THRESHOLD #define
		sg_u8SequentailCellCountMismatches = 0;

	
	
//		DebugOut("ModBatt: Module Controller\n");
	
		(void) RTCInit();
	
		sg_eModuleControllerStateCurrent = EMODSTATE_INIT;
		sg_eModuleControllerStateTarget = STATE_DEFAULT;
		sg_eModuleControllerStateMax = EMODSTATE_OFF;  // Initialize to OFF to prevent relay turning on at startup
		sg_bModuleRegistered = false;  // Initialize to false to prevent relay/FET activation without registration
		sg_eStringPowerState = ESTRING_INIT;  // Initialize cell string power state machine
		WDTSetLeash(WDT_LEASH_LONG, EWDT_NORMAL);  // set on long leash
		sg_eFrameStatus = EFRAMETYPE_WRITE; // start on a write so that housekeeping gets done
	}
	
		
	// Enable all interrupts!
	sei();
	
	while(1)
	{
		WatchdogReset();

		// Process queued CAN RX messages (deferred from ISR for reduced interrupt latency)
		// Call frequently to ensure timely message processing
		CANProcessQueue();

		if (sg_bNewTick)
		{
			sg_bNewTick = false;  // set tru in periodic tick isr, cleared in main loop
			uint8_t u8Reply[CAN_STATUS_RESPONSE_SIZE];

			// Check CAN TX status every tick (100ms) for recovery from stuck transmissions
			CANCheckTxStatus();

			// Check overall CAN health and recover from error states
			CANCheckHealth();

			// Process TX retries if pending (deferred from ISR)
			CANCheckRetry();

			// Reconfigure MOBs if needed (deferred from ISR)
			CANCheckMOBs();

			// Process frame transfer if active
			ProcessFrameTransfer();

			// Clear separation of registered vs unregistered behavior
			if (!sg_bModuleRegistered)
			{
				// Not registered - handle announcement delays
				if (sg_bAnnouncementPending)
				{
					if (sg_u8AnnouncementDelayTicks > 0)
					{
						sg_u8AnnouncementDelayTicks--;
					}
					
					if (sg_u8AnnouncementDelayTicks == 0)
					{
						// Time to send the announcement
						sg_bSendAnnouncement = true;
						sg_bAnnouncementPending = false;
						DebugOut("Announcement delay complete - sending\r\n");
					}
				}
			}
			else
			{
				// Registered - handle normal operations
				// Send controller status messages
				ControllerStatusMessagesSend(u8Reply);
			}


		
			// Check for a pack controller timeout.  Reset our ID if we've lost contact.
			if( sg_bPackControllerTimeout )
			{
				sg_bPackControllerTimeout = false;
				sg_u8ModuleRegistrationID = 0;
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

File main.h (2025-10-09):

#ifndef _MAIN_H_
#define _MAIN_H_

#include "adc.h"

// Maximum number of cells that this module controller can handle
#define TOTAL_CELL_COUNT_MAX				(94)  // current modules are 94

// CPU speed (in hz) - internal clock
#define CPU_SPEED						8000000

// Timer prescaler - can be 1, 8, 64, 256, or 1024
#define TIMER_PRESCALER0				8
#define TIMER_PRESCALER1				256

// # Of clocks per second post prescaler. Integer arithmetic OK here since all
// divisors are powers of 2.
#define TIMER0_CLOCKS_PER_SECOND			((uint32_t)CPU_SPEED / (uint32_t)TIMER_PRESCALER0)
#define TIMER1_CLOCKS_PER_SECOND			((uint32_t)CPU_SPEED / (uint32_t)TIMER_PRESCALER1)

// This provides a 100ms periodic period. (8000000/256)=32150 ticks per interrupt, or 100ms
#define PERIODIC_COMPARE_A_RELOAD			(3125)
#define PERIODIC_INTERRUPT_RATE_MS			100
#define PERIODIC_INTERRUPT_MS_TO_TICKS(x)	(x / PERIODIC_INTERRUPT_RATE_MS)

// Callback rate (in milliseconds)
#define PERIODIC_CALLBACK_RATE_MS		300  //needs to be multiple of 100, per above.  300ms gives enough time for full string to be received (50us * 11 bits * 4 bytes = 2.2ms/cell)
#define PERIODIC_CALLBACK_RATE_TICKS	PERIODIC_INTERRUPT_MS_TO_TICKS(PERIODIC_CALLBACK_RATE_MS)

// Callback frames alternate between active read (where we get string data) and write (where we report and store it).

typedef enum
{
	EFRAMETYPE_READ,
	EFRAMETYPE_WRITE,
} EFrameType;



// Pack controller timeout (in milliseconds)
#define PACK_CONTROLLER_TIMEOUT_MS		11100
#define PACK_CONTROLLER_TIMEOUT_TICKS	PERIODIC_INTERRUPT_MS_TO_TICKS(PACK_CONTROLLER_TIMEOUT_MS)



// 0 - all off
// 1 - mech on, fet off
// 2 (this is a pack level state, means only one module turns on, pack controller will decide which.  modules will never see this state)
// 3 - both on
// * on loss of 5V go to state 0
// * on overcurrent detect go to state 1
//
// NOTE: DO NOT Change the order of these states as they are  tied to the CAN
// specification in addition to the transition code relying on them being in
// the order they're in.
typedef enum
{
	EMODSTATE_OFF = 0,
	EMODSTATE_STANDBY,
	EMODSTATE_PRECHARGE,
	EMODSTATE_ON,
	
	EMODSTATE_COUNT,
	
	// NOTE: This must come AFTER count, as it's a state that kicks off an
	// initial assessment of the system.
	EMODSTATE_INIT,
} EModuleControllerState;

extern EModuleControllerState ModuleGetState(void);

extern void Delay(uint32_t u32Microseconds);
extern uint8_t PlatformGetRegistrationID( void );
extern void ADCCallback(EADCType eType,
						uint16_t u16Reading);

// I2C Port
#define I2C_PORT			PORTD
#define I2C_PORT_READ		PIND
#define I2C_PORT_DDR		DDRD

// I2C Pins on that port
#define I2C_SDA_PIN			PORTD1
#define I2C_SCL_PIN			PORTD0

extern void PlatformAssert( const char* peFilename, const int s32LineNumber );
#define MBASSERT(x)			{if(false == (x)){PlatformAssert(__FILE__, __LINE__);}}
	
extern void DebugGPIOToggle( void );

extern uint16_t PlatformGetSendData( bool bUpdateBalanceStatus );
extern void WatchdogReset( void );
extern void SetSDBusy( bool bBusy );

extern void vUARTRXStart(void);
extern void vUARTRXEnd(void);
extern void vUARTRXData( uint8_t u8rxDataByte );
extern volatile bool g_bServiceNeeded;

extern void FrameInit(bool  bFullInit);  // call with true for full init (session), false for partial (frame)

#endif

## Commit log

2025-07-10 claude fixes for FET_EN and CANMOBSet
    ● I've fixed the CAN interrupt corruption issue. The problem was a classic race condition:
    Root Causes:
    1. No interrupt protection in CANMOBSet - The function that configures MOBs and writes data wasn't atomic
    2. ISR re-enabled global interrupts with sei(), allowing nested interrupts
    3. CANPAGE register corruption - When RX interrupt fired during TX setup, it changed CANPAGE, causing remaining
    TX data to be written to wrong location
    Fixes Applied:
    1. Added interrupt protection in CANMOBSet by disabling CAN interrupts during the entire MOB configuration
    2. Removed sei() from the ISR to prevent interrupt nesting
    3. Proper save/restore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
    [can.c, main.c]
2025-07-29 relay handling fix
    initialize registered and max state variables at power on (they were moved to the .noinit section). added check to only turn on relays when registered.
    [main.c]
2025-07-30 Fix status request race condition and deregister handling
    Major fixes:
    - Pack controller: Track all 3 status messages before clearing statusPending
    - Module: Add sg_bIgnoreStatusRequests to prevent sequence restart
    - Fix individual deregister message handling
    - Add comprehensive debug output for status messages
    - Update CLAUDE.md with critical development protocol
    This fixes the registration/deregistration loop caused by multiple
    status requests interrupting the module's status sequence.
    [can.c, main.c]
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2025-09-06 Fix MODULE_MAX_STATE heartbeat parsing bug
    The module was reading the wrong byte for the max state value.
    MODULE_MAX_STATE (0x517) is a 1-byte message with state at byte 0,
    but code was incorrectly reading byte 1 (out of bounds).
    This caused the module to not recognize heartbeats from the Pack
    Controller, leading to timeout and re-registration cycles.
    Changed: pu8Data[1] -> pu8Data[0] for MaxState parsing
    [main.c]
2025-09-06 WIP: Debugging CAN receive callback issues
    Current status:
    - CAN receive callback never gets called (breakpoint not triggered)
    - Module times out after 11.1s and announces itself
    - Pack Emulator successfully transmits heartbeat (0x517) every 200ms
    - Module does NOT receive these heartbeats, causing timeout/re-registration cycle
    Investigation findings:
    - ModuleCPU sets IDE bit (line 228) configuring it for extended CAN frames
    - Pack Controller (real hardware) also uses extended frames (IDE=1)
    - CAN acceptance filter mask changed from 0x500 to 0x700 (more correct but not the issue)
    - ID extraction code at line 389 may be wrong for extended frames but somehow worked before
    Open questions:
    - H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
    [can.c, main.c]
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2025-09-08 Fix cell string power initialization on power-on reset
    - Move sg_eStringPowerState to .noinit section to survive watchdog resets
    - Add explicit initialization to ESTRING_INIT on power-on reset
    - Cell string power state machine now properly starts and transitions
    - Verified cell processing is enabled (FAKE_CELL_DATA commented out)
    [main.c]
2025-09-09 Add debug output for MODULE_DETAIL_REQUEST handling
    Added comprehensive debug logging to understand why module isn't sending MODULE_DETAIL responses:
    1. Log incoming detail requests with module ID, cell ID, and counts
    2. Log when scheduling cell detail response
    3. Log reasons for not scheduling (already sending, out of range)
    4. Log when attempting to send cell details
    5. Log when cell ID exceeds available cells
    Current findings:
    - Module receives DETAIL_REQUEST messages correctly
    - Only 1 cell is communicating (sg_u8CellCPUCount = 1)
    - Module will only send details for cells < sg_u8CellCPUCount
    - This explains why no MODULE_DETAIL messages are sent for cells 1-12
    Next step: Test with deb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
    [main.c]
2025-09-09 Fix MODULE_DETAIL to respond for all requested cells
    Major fix to cell detail reporting:
    1. Module now sends MODULE_DETAIL (0x505) for ALL requested cells
    2. Cells without data send zeros instead of stopping the sequence
    3. Added comprehensive debug logging to track the process
    4. Fixed divide-by-zero issues in SOC/SOH calculations
    Previous behavior:
    - Only sent details for cells < sg_u8CellCPUCount (cells that reported)
    - Stopped sending when reaching non-communicating cells
    - Pack Emulator never received MODULE_DETAIL responses
    New behavior:
    - Sends MODULE_DETAIL for all requested cells (0-12)
    - Non-communicating cells return 0V and 0°C
    - Pack Emulator receives all responses and displa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
    [main.c]
2025-09-09 Fix build errors - remove all debug statements
    Fixed compilation errors by removing all debug statements:
    - ModuleCPU does not have debug output functions (no DebugOut, DebugOutUint8, etc.)
    - Removed all debug statements added in previous commit
    - Kept the fix for sending MODULE_DETAIL for all requested cells
    - Added note to CLAUDE.md about no debug output capability
    The module now properly:
    1. Sends MODULE_DETAIL for all requested cells (0-12)
    2. Returns zeros for non-communicating cells
    3. Compiles without errors
    Debug must be done through CAN messages or LED indicators only.
    [main.c]
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2025-09-09 Fix alternating min/max values in status messages
    - Modified FrameInit() to preserve min/max/avg statistics across frames
    - Only clear statistics when there's no valid cell data
    - Prevents Pack Emulator from seeing zeros during status polling
    - Disabled FAKE_CELL_DATA after successful testing
    - Fixes display glitch where values alternated between actual and zero
    [main.c]
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2025-09-09 Fix MODULE_DETAIL to use raw StringData values directly
    - Remove unnecessary CellDataConvert() call that was returning zeros
    - Use raw values directly from StringData like CalculateStats() does
    - Clear MSG_CELL_DISCHARGE_ACTIVE bit from voltage if present
    - This fixes the issue where MODULE_DETAIL returned zeros despite valid stats
    [main.c]
2025-09-09 Fix MODULE_DETAIL to check against expected cell count
    - sg_u8CellCPUCount is reset to 0 by FrameInit() between frames
    - Use sg_u8CellCountExpected instead to check if cell index is valid
    - This allows MODULE_DETAIL to access StringData even when sg_u8CellCPUCount is 0
    - Cells that haven't reported will have voltage=0 in StringData
    [main.c]
2025-09-09 Fix: Preserve StringData across frames for MODULE_DETAIL responses
    - Don't clear StringData in FrameInit(false) partial initialization
    - StringData contains the last received cell data and must persist
    - This allows MODULE_DETAIL to return actual cell values between frames
    - Min/max/avg stats already persist, now individual cell data does too
    [main.c]
2025-09-09 Fix MODULE_DETAIL to properly convert voltage and temperature
    - Use CellDataConvertVoltage() to convert raw voltage to millivolts
    - Use CellDataConvertTemperature() to convert raw temperature
    - These conversion functions handle scaling and validation
    - Matches the conversion done in CalculateStats() for min/max/avg
    [main.c]
2025-09-09 Fix temperature conversion in MODULE_DETAIL
    - Call CellDataConvertTemperature properly for individual cells
    - The raw temperature in StringData needs conversion
    - This matches how CalculateStats converts temperatures for min/max/avg
    [main.c]
2025-09-10 Fix sg_u8CellCPUCountMost initialization issue
    - Explicitly initialize sg_u8CellCPUCountMost to 0 after memset in full init
    - Fixes issue where max cells was reporting 170 (0xAA) instead of actual count
    - Note: 29.25V voltage issue was hardware-related (resistor config for 48V)
    [main.c]
2025-09-11 WIP: VUART edge-triggered timing correction (overcorrecting)
    - Added edge detection during data reception for timing correction
    - Tracks min/max timing errors and correction count statistics
    - Switches between falling-edge (start bit) and any-edge (data bits) modes
    - Current implementation may be overcorrecting - needs simpler approach
    [vUART.c]
2025-09-12 WIP: Move VUART diagnostic sync signal from PC7 to PD7
    - PC7 drives flipflop clock on REV E+ boards, causing conflicts
    - Moved profiler output to PD7 which is unused
    - Signal not appearing on PD7 despite code executing (needs hardware debugging)
    [vUART.c]
2025-09-12 WIP: VUART edge correction and cell detail fixes
    - Implemented edge-triggered timing correction for VUART RX
    - Moved diagnostic sync signal from PC7 to PD5
    - Fixed cell detail target calculation (was same, now +1)
    - Removed unsolicited status messages during cell processing
    - Edge correction made VUART less reliable, needs investigation
    - Cell detail sequence still erratic despite fixes
    [main.c, vUART.c]
2025-09-13 fix: clear ignore status flag on module registration
    - Reset sg_bIgnoreStatusRequests to false when module is registered
    - Ensures module can respond to status requests after registration
    - Updated SESSION_STATUS.md with current status of issues
    [main.c]
2025-09-14 Add missing noinit variable initializations on power-on reset
    - Initialize all critical status message flags to false
    - Initialize safety flags (overcurrent, discharge, balance) to false
    - Initialize SOC, SOH, cell status variables to 0
    - Initialize cell count mismatch tracking variables
    - Set sg_bSendAnnouncement to true for startup announcement
    - Ensures clean startup state for all control variables
    [main.c, vUART.c]
2025-09-17 Fix CAN reliability issues in ModuleCPU
    - Fixed hardware detail flag to clear regardless of CAN send success
    Hardware detail is not critical, so don't retry forever if CAN is busy
    - Fixed critical race condition bug in CAN interrupt handler
    Commented out incorrect sg_bBusy/sg_bInRetransmit clearing in RX MOB context
    These flags should only be cleared in TX MOB context to prevent overlapping TX operations
    This was causing module lockups and CAN peripheral confusion
    These fixes should resolve the module going quiet and stuck in CAN ISR issues.
    [can.c, main.c]
2025-09-17 Remove incorrect TX status handling from RX MOB context
    - Commented out entire TXOK handling block in RX MOB interrupt handler
    - RX MOB should NEVER handle TX status bits - this belongs only in TX MOB
    - This incorrect handling could interfere with actual TX operations
    - May fix remaining CAN reliability issues
    [can.c]
2025-09-17 Add comprehensive CAN MOB interrupt flow documentation
    - Documents normal TX flow and how TX MOB gets re-enabled via CANMOBSet
    - Documents TX error/retry flow
    - Documents normal RX flow and continuous re-enabling
    - Explains why system works: CANMOBSet always re-enables on next TX
    - Notes potential issue: TX MOB stays disabled after last transmission
    - Helps future debugging by clarifying the non-obvious re-enable mechanism
    [can.c]
2025-09-19 Fix VUART rising edge detection for inverted signals
    Level shifters between cells invert the signal, so ModuleCPU needs
    to detect rising edge (not falling) for start bit. Added VUART_RX_RISING_EDGE
    macro and updated all edge detection to use rising edge.
    Also includes:
    - Disabled temperature range validation temporarily for debugging
    - Added FAKE_CELL_DATA define for testing
    - Updated context documentation
    [main.c, main.h, vUART.c]
2025-09-22 Fix CAN TX stuck busy issue with timeout mechanism
    - Changed sg_bBusy from bool to uint8_t timeout counter
    - Added CANCheckTxStatus() to poll TXOK and recover from stuck TX
    - Timeout after 200ms (2 ticks) if TX doesn't complete
    - Called every 100ms from main loop as backup to interrupts
    - Prevents permanent CAN lockups when interrupts fail
    [can.c, main.c]
2025-09-22 Improve CAN TX timeout mechanism and add diagnostics
    - Fixed timeout extension on retransmits (don't reset on AERG)
    - Added diagnostic counters for timeouts, errors, and polled TXOK
    - Properly disable TX MOB interrupt on timeout
    - Clear sg_bInRetransmit flag on timeout/error recovery
    - Export diagnostic functions to monitor CAN health
    [can.c]
2025-09-22 Fix critical CAN bus-off recovery issue
    CRITICAL FIX: CAN controller was not recovering from bus-off state!
    Problem: CAN permanently failed even with sg_u8Busy=0
    Root cause: Bus-off handler only cleared flag, never re-enabled controller
    Changes:
    - Bus-off handler now re-enables controller with CANGCON=(1<<ENASTB)
    - Added CANCheckHealth() called every 100ms to:
    - Detect and recover from disabled controller state
    - Verify and re-enable RX MOB if disabled
    - Monitor error passive state (TEC/REC > 127)
    - Added diagnostic counters for bus-off and error passive events
    - Clear busy/retransmit flags on bus-off since transmission is lost
    This should fix the issue where CAN stops working compl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
    [can.c, main.c]
2025-09-22 Add bus-off recovery delay and error counter diagnostics
    Problem: Module rapidly cycling in/out of bus-off state
    Root cause: Immediate retransmission after bus-off causing re-entry
    - Add 1-second delay after bus-off before allowing transmissions
    - Track error counter changes to detect rapid accumulation
    - Add CANGetTEC()/CANGetREC() for error counter monitoring
    - Improve CANCheckHealth() with better error tracking
    - Document physical layer requirements (termination, baudrate)
    The rapid bus-off cycling indicates physical bus problems:
    - Check 120Ω termination at both ends
    - Verify 500kbps on all nodes
    - Check ground connections
    - Verify differential pair integrity
    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
    [can.c]
2025-09-22 feat(can): add TX-only error detection and adaptive backoff
    - Detect when CANTEC increases but CANREC stays at 0 (TX-only errors)
    - Implement exponential backoff for persistent TX errors (200ms to 1.6s)
    - Add diagnostic counters for TX-only errors and backoff delays
    - Prevent transmissions during backoff periods
    - Add rapid error detection (>10 errors/tick triggers 500ms backoff)
    This handles hardware issues where module can transmit but not receive,
    specifically addressing issue where one module shows CANTEC=0x1C with
    CANREC=0. Software mitigation for likely transceiver hardware failure.
    [can.c]
2025-09-23 refactor: use shared VUART timing constants from Shared.h
    - Replaced local VUART_BIT_TICK_OFFSET (was 7) with VUART_ISR_OVERHEAD from Shared.h
    - Now uses VUART_SAMPLE_OFFSET for start bit sampling
    - Set to 0 for nominal timing experiments
    - Ensures consistent timing with CellCPU
    [vUART.c]
2025-09-23 feat: make edge sync configurable with #ifdef ENABLE_EDGE_SYNC
    - Edge sync is now disabled by default (commented out)
    - Can be easily enabled for experiments by uncommenting the define
    - Fixed sync formula to use VUART_SAMPLE_OFFSET for consistency
    - Properly handles interrupt enable/disable based on mode
    - Wrapped all edge sync code in conditional compilation blocks
    This allows easy A/B testing between fixed timing and edge sync modes.
    [vUART.c]
2025-09-24 Fix cell reporting order and frame stability issues
    - Added sg_u8LastCompleteCellCount to track cells from last complete frame
    - Implemented reverse-order cell mapping for VUART chain (last functional cell reports first)
    - MODULE_DETAIL now reports actual cells received vs expected count
    - Frame structure standardized to exactly 1024 bytes (2 SD sectors)
    - Cell count saved in CellStringProcess() for stable reporting during next frame collection
    This fixes the issue where cells were reporting incorrect data due to:
    1. VUART chain reverse order (physical cell N-1 is at StringData[0])
    2. Active frame instability (sg_u8CellCPUCount changing during collection)
    3. Pack Controller expecting physic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
    [main.c]
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2025-09-25 Replace EEPROM-based string tolerance with compile-time constant and fix VUART timeout detection
    - Replaced sg_u8SequentailCountMismatchThreshold EEPROM variable with SEQUENTIAL_COUNT_MISMATCH_THRESHOLD #define (set to 5)
    - Fixed CellStringProcess() to handle zero bytes received as communication failure
    - Now properly detects complete VUART communication failures (no interrupts)
    - Zero cells received triggers mismatch counter, leading to automatic string reset after threshold
    - Pack controller receives accurate cell count (0) to mark data as stale
    [main.c]
2025-09-26 Re-enable hardware detail retries on CAN busy
    - Changed back to only clear sg_bSendHardwareDetail on successful send
    - This allows retries if CAN bus is busy
    - Previously disabled to prevent infinite retries, but now CAN has proper timeout mechanism
    [main.c]
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2025-09-28 Implement circular buffer for multiple string readings
    - Added invalid cell markers (0xFFFF/0x7FFF) for non-reporting cells
    - Dynamic buffer sizing: 11 readings for 20 cells, 4 for 50, 2 for 94
    - Initialize buffer with invalid markers at READ frame start
    - Always advance buffer at WRITE frame (never gets stuck)
    - CAN responses use GetLatestCompleteString() for consistent data
    - Frame counter increments with each reading
    - System properly handles partial strings and cell dropouts
    - Tested: compiles and reports to pack controller correctly
    [main.c]
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2025-10-02 Implement MOB-based module ID filtering for extended frames
    Added MOB 0/2 configuration for hardware-based message filtering:
    - MOB 0: Module-specific messages (0xFF unregistered, assigned ID when registered)
    - MOB 2: Broadcast messages (always 0x00)
    - Added CANSetModuleIDFilter() to reconfigure MOB filters dynamically
    - CANInit() sets MOB 0 to 0xFF (unregistered), MOB 2 to 0x00 (broadcast)
    - Registration updates MOB 0 filter to assigned module ID
    - Deregistration resets MOB 0 filter back to 0xFF
    - Interrupt handler processes both MOB 0 and MOB 2 RX events
    Benefits:
    - Hardware filtering isolates module-specific traffic
    - Modules don't hear each other's responses
    - Reduced interrup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
    [can.c, main.c]
2025-10-02 Comment out redundant module ID checks in module-specific message handling
    Hardware MOB filtering now ensures only messages addressed to this module
    (or broadcast 0x00) reach the RX handler, making software ID checks redundant.
    - Commented out module ID extraction and validation for module-specific messages
    - Hardware filtering (MOB 0 with assigned ID) guarantees message is for us
    - Registration message still extracts moduleId - this is the ASSIGNED ID value
    being communicated from pack controller, not a redundant routing field
    Module-specific messages (status request, state change, etc.) no longer need
    to check pu8Data[0] against sg_u8ModuleRegistrationID.
    🤖 Generated with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
    [main.c]
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2025-10-03 feat(can): add sequence numbers to frame transfer DATA messages
    - Add CANSendMessageWithSeq() API to include sequence in extended ID bits 8-17
    - Implement CANMOBSetWithSeq() for encoding sequence into CAN extended frames
    - Update frame transfer to send DATA segments with explicit sequence numbers
    - Fix frame transfer CRC failures by using STORE frameBuffer instead of live sg_sFrame
    - Add STORE_GetFrameBuffer() accessor to prevent race conditions during transfer
    - Skip SD writes during frame transfer to preserve frameBuffer integrity
    - Cell reading continues normally while frame transfer is in progress
    This enables detection of missing, duplicate, or out-of-order CAN messages
    during frame tr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
    [can.c, main.c]
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2025-10-04 fix: initialize frame current fields to 0A instead of floor value
    Initialize u16maxCurrent, u16minCurrent, u16avgCurrent to 0x8000 (0.00A)
    instead of 0x0000 (-655.36A floor) on frame initialization.
    Current encoding: Amps = -655.36 + raw * 0.02
    For 0A: raw = 655.36 / 0.02 = 32768 = 0x8000
    This prevents emulator from displaying -655.36A for uninitialized values.
    [main.c]
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2025-10-05 fix: reset min/max cell count per frame instead of per session
    With circular buffer storing multiple string readings per frame, min/max
    cell CPU count should track the range within each frame's readings, not
    across the entire session.
    Now resets sg_u8CellCPUCountFewest and sg_u8CellCPUCountMost after writing
    each complete frame, before starting the next frame's circular buffer cycle.
    Updated comments to clarify these are per-frame statistics.
    [main.c]
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2025-10-09 wip: Add SD/state transition mutex and debug pin pullups
    SD Card / State Transition Mutex:
    - Added sg_bSDBusy flag in .noinit section for WDT recovery detection
    - Added SetSDBusy() function to set/clear busy flag
    - STORE_WriteFrame/ReadFrame now set busy flag during SD operations
    - State transitions check sg_bSDBusy and defer if SD is active
    - Prevents relay switching EMI from corrupting SPI transactions
    - Setting target state now preemptively disables SD writes
    - Added TODO in WDT ISR for stuck SPI detection/recovery
    Debug Pin Pullups (PD2/PD3/PD4):
    - Added internal pullups on debug/SPI alternate pins
    - Explicitly clear SPIPS to route SPI to Port B
    - Prevents floating inputs from triggerin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
    [main.c, main.h]
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2025-10-22 feat(safety): depower cell string during state transitions
    Added cell string pause mechanism to protect CellCPU circuits from
    voltage glitches during relay/FET switching.
    - New PauseCellString() function depowers cells before transitions
    - Sets cell string to ESTRING_INIT state
    - Turns off cell power with 10ms propagation delay
    - Clears frame data and resets vUART gracefully
    - Called once before any state transition
    - Cell string automatically powers back up via state machine
    - Protects CellCPU boards, temperature sensors, and monitoring circuits
    - No added delay to state transitions (10ms propagation time)
    - Automatic recovery (~100-150ms via existing state machine)
    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
    [main.c]
2025-10-23 feat(eeprom): add unprogrammed EEPROM handling for testing [WIP]
    Added support for testing with unprogrammed EEPROM to simplify
    hardware bring-up and debugging with new boards.
    - New sg_bEEPROMValid flag in .noinit section
    - Default UID 0xBA77BABE when EEPROM unprogrammed (UID=0xFFFFFFFF)
    - Auto-discovery of cell count starting from 0
    - Cells expected increments as cells are discovered
    - Only grows (never shrinks) for stability
    - Current thresholds already handle unprogrammed values (0x0000/0xFFFF)
    - No EEPROM programming needed for initial testing
    - Automatically adapts to actual cell string size
    - Simplifies bring-up of new boards
    - Easy transition to production (just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
    [main.c]
2025-10-24 fix(eeprom): auto-discover cell count even when unique ID is programmed
    Fixed issue where module would ignore actual cell count if unique ID
    was programmed but cell count was left at 0xFF or 0x00.
    - Check cell count value (0xFF or 0x00) instead of just sg_bEEPROMValid
    - Auto-discover if cell count is unprogrammed, regardless of UID
    - Two-tier auto-discovery:
    1. If expected count = 0: Set to first received count
    2. If EEPROM fully unprogrammed: Allow count to keep growing
    This handles mixed programming scenarios:
    - UID programmed, cell count not → auto-discover from first read
    - UID not programmed, cell count not → auto-discover and grow
    - Both programmed → use fixed EEPR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
    [main.c]
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

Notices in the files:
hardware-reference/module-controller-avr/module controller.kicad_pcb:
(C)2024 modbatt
